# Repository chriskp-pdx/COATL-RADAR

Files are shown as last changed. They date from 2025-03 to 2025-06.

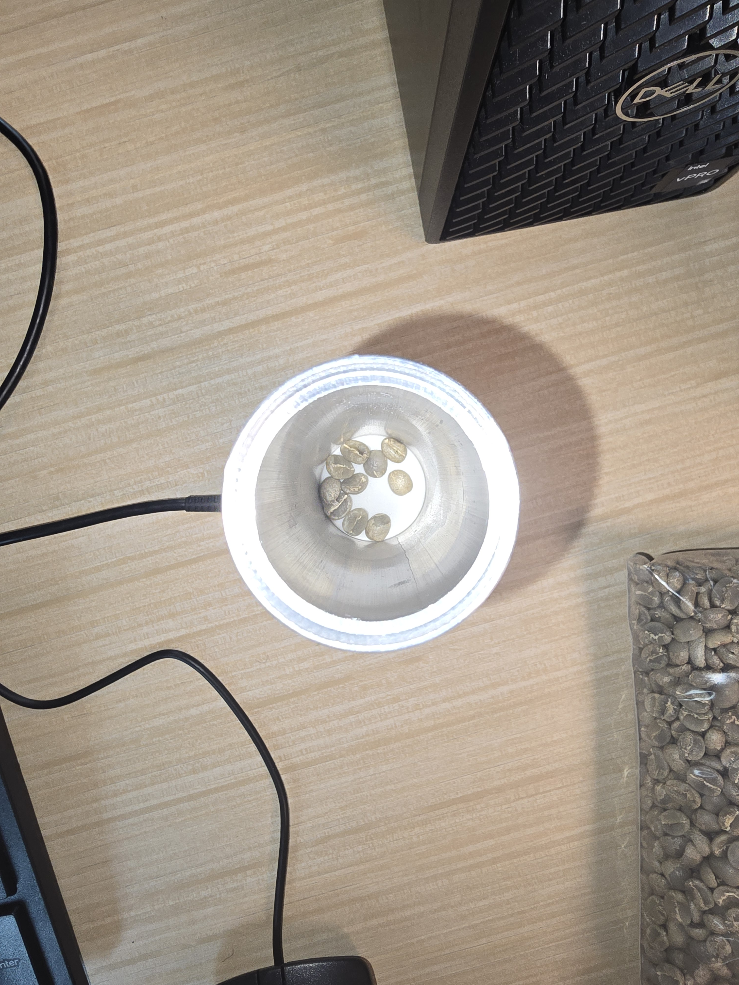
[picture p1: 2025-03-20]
Documentation/Test Documentation/3D Printed Prototype Testing/1-10 Bean Range Tests/Lens 1 Testing/Images/20250310_161537.jpg

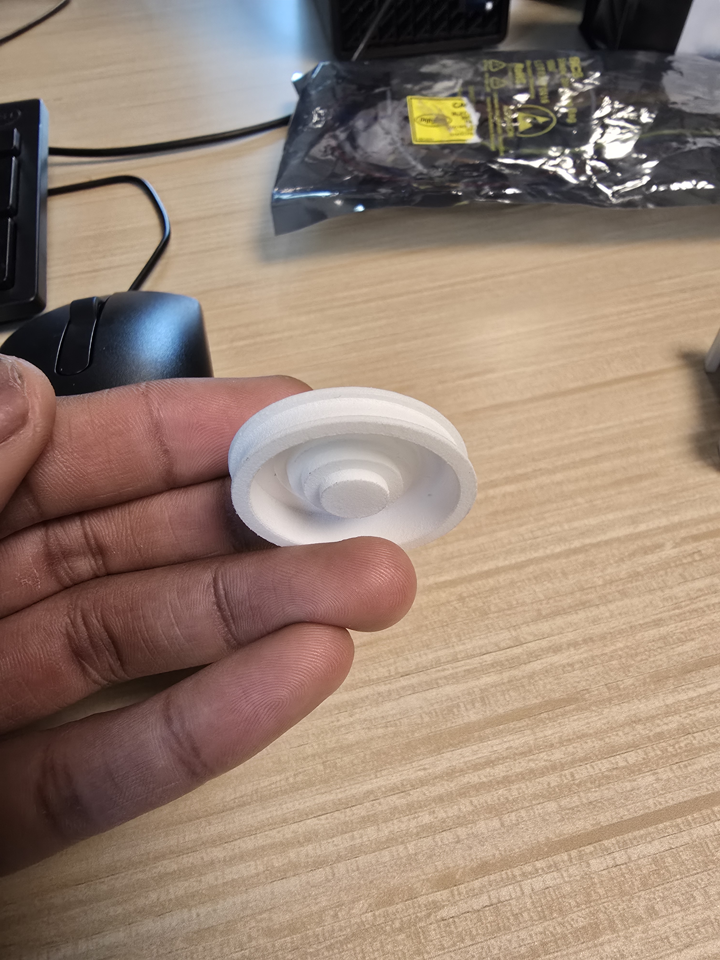
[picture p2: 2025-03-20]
Documentation/Test Documentation/3D Printed Prototype Testing/1-10 Bean Range Tests/Lens 2 Testing/Images/Lens2.jpg

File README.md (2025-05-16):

# COATL-RADAR

2025 ECE 412/413 COATL-RADAR PROJECT

Green Coffee Bean Moisture Content Detection Using 60GHz Radar Module

# Team:
Chris Kane-Pardy

Kamal Smith

Henry Sanders

Wallace Mckenzie

# Software:

## A121 Binary File

Acconeer Provided File for Flashing Firmware to New XE125 EVK Radar Module

## A121 Exploration Tool Connection

Initial Test Programs to Interface with Acconeer A121 Exploration Tool Through Python

## Data Collection

### Consistency Testing

After Deciding Against Calculating Permittivity, We Created These Programs, Which Attempted to Mitigate Inconsistencies in Results due to Bean Geometries

### Datasets

Collected Datasets for Use in Machine Learning

### Permittivity Calculations

Original Test Programs, Which Aimed to Determined Moisture Content by First Calculating Permittivity from Acconeer "IQ" Data

### FullAverageScan (Green Coffee)

Final Program Version Which Utilizes Several Averages and Captures the Entire Waveform of the IQ Data Scan

### FullAverageScan (Roasted Coffee)

Final Program Version With Modified Settings Aimed at using Ground Roasted Coffee

## Machine Learning

### Preliminary Testing

Original Exploratory Machine Learning Programs

### Experimentation Variants

3 Separate Versions of the Base Machine Learning Program (Chris, Kamal, & Henry), Which We Used to Test and Compare Accuracy Across Different Settings

### Final Machine Learning Program with Live Testing

The Final Version of Our Machine Learning Program

## Stepper Motor

Outdated Programs for Interfacing ESP32 to Stepper Motor Using I2C for Bean Rotation

# Documentation:
## Acconeer Documentation

-Acconeer A121 Radar Datasheets

-Acconeer XE125 EVK User Guides

-Acconeer Exploration Tool Documentation

-Acconeer Lens Kit Documentation & Data Sheet

## Administrative (Team Organization)

-Weekly Progress Reports

-Team Meeting Notes

## Datasheets

Miscellaneous Datasheets from Abandoned Components

## Research Documents

### COATL-RADAR Research Documentation

Documents Compiled by the Team Throughout Our Process Which We've Deemed Useful Starting Points

### Machine Learning Research (Mark Martin)

Brief Introduction to Machine Learning Provided by Our Wonderful Industry Sponsor (Dr. Mark Martin)

### Optics Research

Documents Focusing on the use of Lenses in Radar Applications (Brief Research from Wallace)

### Research Articles (Dr. Joshua Mendez)

Contains Research Papers Provided by Our Industry Sponsor (Dr. Joshua Mendez)

## Test Documentation

Test Results, Intermediate Procedures, and Various Methods We Attempted Throughout the Course of the Project

### 3D Printed Prototype

Testing Results Utilizing PETG/PLA 3D Printed Test Device

### Medium Metal Device Testing

Testing Results Utilizing Medium-Sized Aluminum Test Device

### Metal Device Testing

Testing Results Utilizing Large Aluminum Test Device

### Thin Metal Device Testing

Testing Results Utilizing Thin Aluminum Test Device

# 3D Modeling
### V1.1
Contains Original 3D Printed "Spider" Prototype for Testing Rotation
### V1.2
Contains Modified 3D Printed "Spider" Prototype with Updates
### V2.1
Contains "Christmas Tree Stand" to Hold Metal Tube Flush w/ Lens for Shielding and 0 Intereference

# Assigments:
Contains All Course Deliverables

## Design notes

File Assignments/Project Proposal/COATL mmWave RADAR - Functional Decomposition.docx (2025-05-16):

COATL mmWave RADAR:

Functional Decomposition

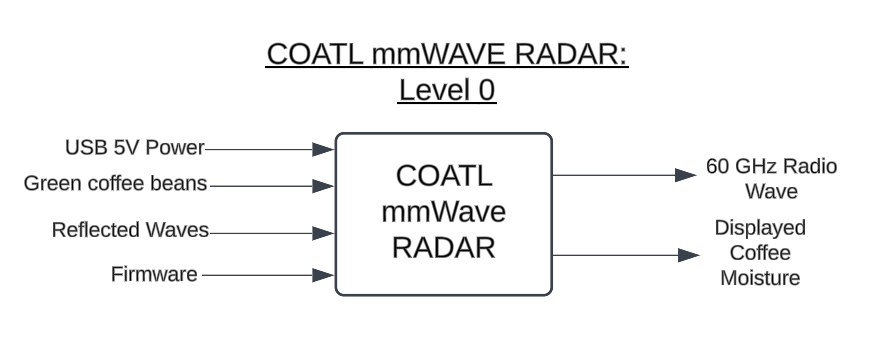
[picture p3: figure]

Module | COATL mmWave RADAR
Inputs
Outputs
Functionality

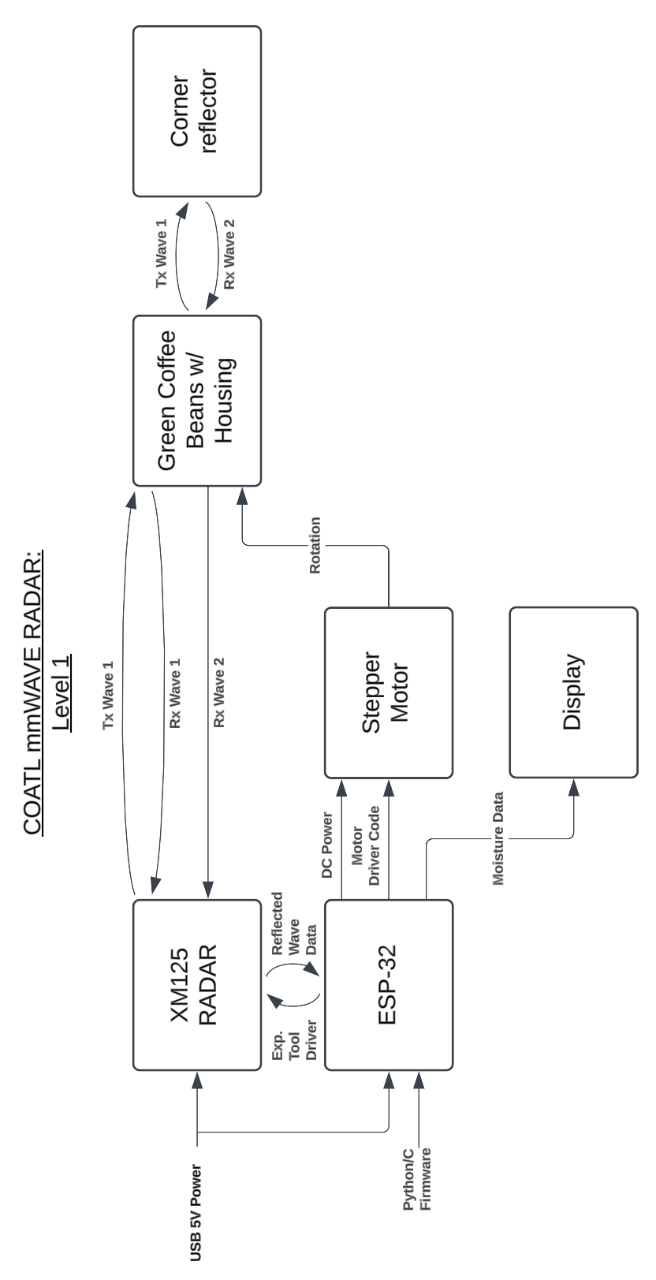
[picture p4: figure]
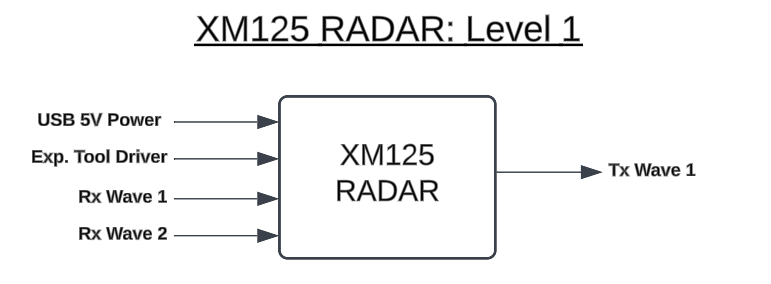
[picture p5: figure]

Module | XM125 RADAR
Inputs
Outputs
Functionality

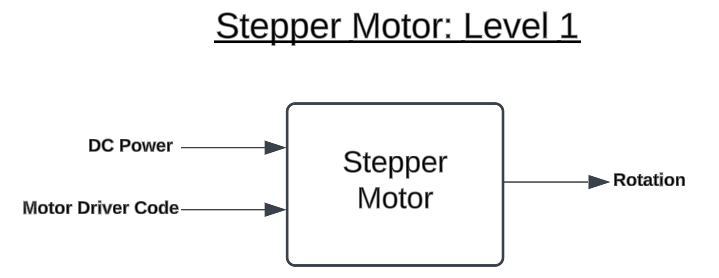
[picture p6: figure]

Module | Stepper Motor
Inputs
Outputs
Functionality

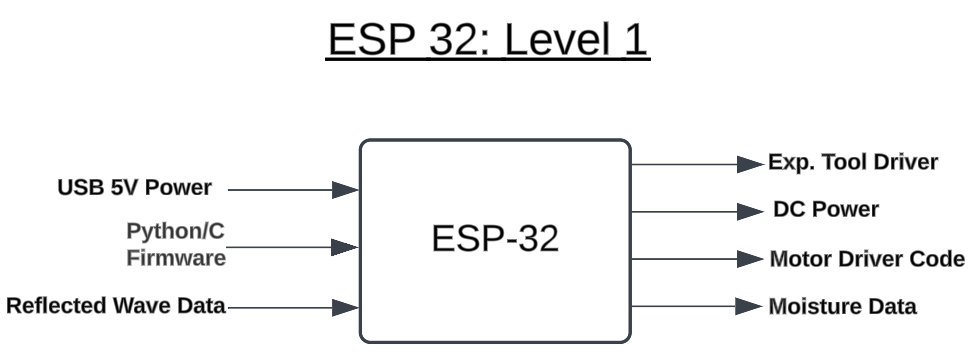
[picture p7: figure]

Module | ESP 32
Inputs
Outputs
Functionality

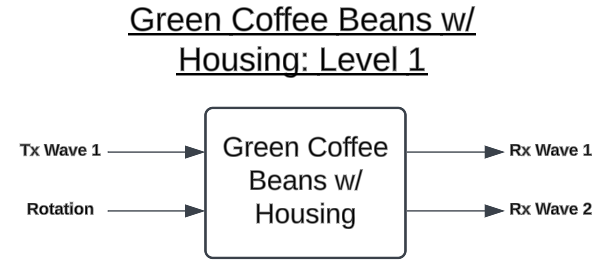
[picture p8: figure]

Module | Green Coffee Beans w/ Housing
Inputs
Outputs
Functionality

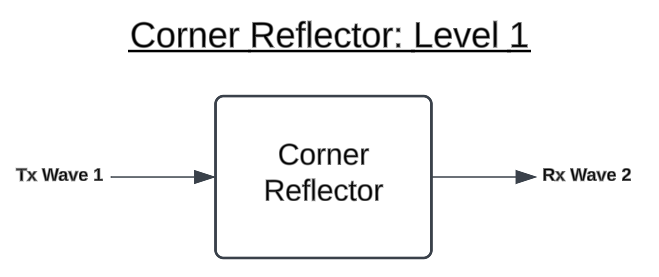
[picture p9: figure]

Module | Corner Reflector
Inputs
Outputs
Functionality

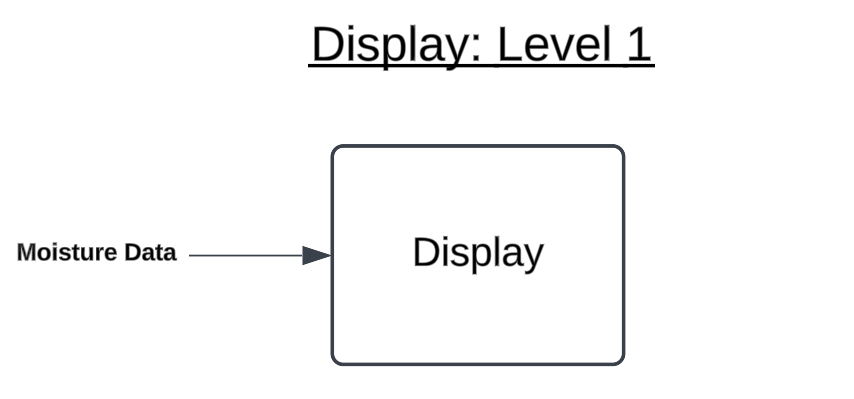
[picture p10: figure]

Module | Display
Inputs
Outputs
Functionality

Kamal Smith Henry Sanders Chris Kane-Pardy Wallace McKenzie 29 January 2025

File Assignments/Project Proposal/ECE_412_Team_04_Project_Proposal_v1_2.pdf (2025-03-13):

# COATL - Millimeter Wave

# RADAR Project Proposal

# Team 4

# Version 1.1

Portland State University

Maseeh College of Engineering & Computer Science

Department of Electrical & Computer Engineering

## Authors:

Kane-Pardy, Chris

McKenzie, Wallace

Sanders, Henry

Smith, Kamal

## January 31, 2025

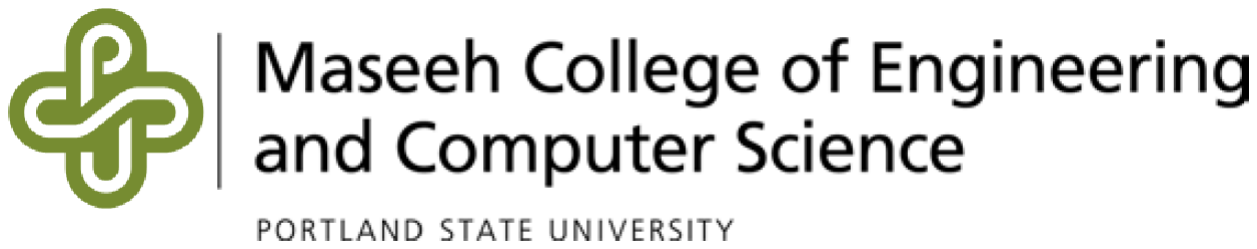
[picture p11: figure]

COATL - Millimeter Wave RADAR | PSU ECE 412

# Executive Summary

The Millimeter-Wave RADAR for Assessing Green Coffee Quality project aims to develop an innovative, non-destructive method for measuring the moisture content of green coffee beans. Accurate moisture measurement is critical for optimizing coffee roasting processes and preserving quality during storage. Current solutions, such as oven drying or capacitive moisture sensors, are either destructive or cost-prohibitive for widespread use.
To address these challenges, this project proposes leveraging the XM125 60 GHz millimeter-wave RADAR module, known for its sensitivity to moisture due to water’s strong absorption properties at this frequency. The system will utilize time-of-flight RADAR technology to detect variations in dielectric properties influenced by moisture content. A key innovation of this approach is its potential to offer a low-cost, scalable alternative for producers, importers, and specialty roasters.
The project will result in a functional prototype comprising a RADAR-based sensor system, software to estimate dielectric constants, and a real-time graphical user interface for visualizing measurement data. Core deliverables include moisture content estimation software, validation against professional-grade sensors, and a userfriendly design for practical use.
This multidisciplinary effort will require expertise in RF system design, programming, CAD modeling, and data analysis. The project aligns with industry needs and has significant implications for improving coffee quality assessment methods while reducing costs for small-scale producers.

Engineering Building, 1930 SW 4th Ave, Portland, OR 97201 1

# Contents

1 Background and Research | 3
2 Product Design Specification | 6
3 Project Management Plan | 13
4 Industry Sponsor / Faculty Advisor Signatures | 16

Engineering Building, 1930 SW 4th Ave, Portland, OR 97201 2

# 1 Background and Research

Sponsor
The project is sponsored by the Coffee And Telesensing Lab (COATL), a research group focused on applying advanced sensing technologies to improve agricultural processes and product quality. COATL specializes in using state-of-the-art remote sensing techniques, including radar and microwave systems, to address challenges faced by coffee producers and processors. By combining expertise in electrical engineering, signal processing, and agricultural science, COATL aims to develop scalable, cost-effective solutions to enhance coffee quality monitoring and control.

Technology Domain and Context
The technology domain of this project is millimeter-wave radar sensing for agricultural product quality assessment. Specifically, this system uses the XM125 60 GHz pulsed coherent radar module to measure the moisture content of green coffee beans. Moisture content is critical in coffee’s long-term storage stability, roasting profile, and overall quality. Traditional moisture measurement methods include oven drying (destructive and time-consuming) or capacitive sensors (non-destructive but expensive). The millimeter-wave radar system offers a promising alternative by leveraging water’s strong absorption characteristics at 60 GHz. This approach has already been used for monitoring moisture in other agricultural products, such as drying leaves.

System Functionality
The radar-based moisture sensor works on a time-of-flight principle. The radar transmits a series of electromagnetic pulses and measures the delay and amplitude of reflected waves. When green coffee beans are placed in a sample holder, the dielectric properties of the beans—directly related to their water content—affect the reflected signal. By extracting the dielectric constant, the system estimates the moisture level in the sample. The relationship between reflectivity γ and permittivity is given by:

γ =

√
ϵ1 −

√
ϵ2
√
ϵ1 +

√
ϵ2

!2

Engineering Building, 1930 SW 4th Ave, Portland, OR 97201 3 where ϵ1 and ϵ2 are the relative permeabilities on either side of the coffee-air boundary.
A conceptual design of the proposed RADAR-based moisture sensor is illustrated in Figure 1 below. The system includes: (1) the XM125 radar module, (2) a sample holder designed to contain coffee beans, and (3) a corner reflector. When the sample holder is empty, the millimeter-wave pulses emitted by the radar are reflected back with high amplitude from the corner reflector. To minimize interference with the measurements, the sample holder must be made from materials transparent to 60 GHz waves. When filled with green coffee beans, the pulses are attenuated proportionally to the moisture content in the beans. The raw radar data from the XM125 module is processed using a computer or microcontroller to calculate the dielectric constant of the sample. The system’s performance will be validated by comparing its moisture content estimates to those obtained using a commercial capacitive moisture sensor.

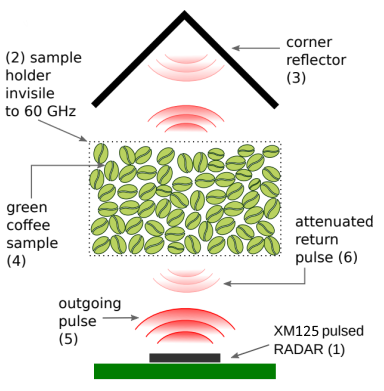
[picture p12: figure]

Figure 1: Conceptual model of material sensing with 60 GHz RADAR for coffee

Engineering Building, 1930 SW 4th Ave, Portland, OR 97201 4

## 1.1 Research

### 1.1.1 Commercial Off-the-Shelf Products

Our industry sponsor (Dr. Joshua Mendez) has provided us with the Acconeer XE125 EVK (evaluation board for the XM125 PCR module). Additionally, he’s provided us with access to the RoastRite Coffee Moisture and Density Meter RM-800 to act as a known good test module/baseline for our test results.

### 1.1.2 Open Source Projects

We’ll be using the Acconeer Exploration Tool (version A121) which runs on Python 3.11.9. Aside from using command line Python, we may utilize Spyder 6 for its convenience as a Python IDE. VS code will be used for C programming, along with the ESP-IDF.

### 1.1.3 Patents, Papers, White Papers, Articles, Conference Proceedings

Patents & White Papers:
Our project proposal and PDS have been thoroughly reviewed via extensive internet research to ensure that it does not infringe on any existing patents or intellectual property. We have conducted due diligence to confirm that all designs, methods, and materials used will be original or fall within the public domain.

Papers:

“A 60 GHz pulsed coherent radar for online monitoring of the withering condition of leaves,” ScienceDirect, Jun. 16, 2022.
https://www.sciencedirect.com/science/article/pii/S0924424722003314 (accessed Jan. 2025).
T. Albing, R. Nelander, and Acconeer AB, “Material Classification of Recyclable Containers Using 60 GHz Radar,” arxiv.org, 2023. https://arxiv.org/pdf/2312.14539

The two papers above use the same radar module as the one we will be using (the XM125). One detects moisture content in leaves, and the other detects recyclable material type. Neither is too dissimilar to our objective and appear to be good reference points. We plan to first try and replicate the recyclables project results to try and familiarize ourselves with the sensor, and periodically reference the leaf paper for any helpful information it may provide.

Engineering Building, 1930 SW 4th Ave, Portland, OR 97201 5

# 2 Product Design Specification

## 2.1 Product Overview

The millimeter-wave radar offers an affordable solution with capabilities rivaling more expensive competitors. This device accurately measures the moisture content of green coffee beans by sending a 60 GHz signal through the provided container. It helps users determine the freshness of their beans and whether it’s time to discard or roast them. Designed for coffee enthusiasts and newcomers alike, the device ensures users can identify beans that are too dry or perfectly suited for roasting. The device is simple to use: fill the container with the specified amount of coffee beans, ensuring it is not overfilled to maintain accuracy. Place the lid securely, then use the small screen to start the reading. Within moments, the moisture content will be displayed.
Initially, we will produce a limited quantity for our industry sponsor and as a proof of concept. If successful, we plan to pursue a patent and explore options for manufacturing or selling the finished product.

## 2.2 Stakeholders

Industry Sponsor

- Dr. Joshua Mendez

Engineering team

- Henry Sanders
- Chris Kane-Pardy
- Wallace McKenzie
- Kamal Smith

Customer/Intended Audience

- Coffee Roasters (companies)
- Coffee Enthusiasts

Engineering Building, 1930 SW 4th Ave, Portland, OR 97201 6

## 2.3 Requirements

- Must:

– Be able to extract the dielectric constant of a fixed-volume sample placed in the RADAR’s beam path for materials with dielectric constants ranging from 5-20.

– Differentiate between at least 3 coffees with different moisture contents (e.g. 8%, 10%, and 12%)

– Detect when the sample holder is empty.

- Should:

– Be able to determine the moisture content of coffees in the range of 7%-15%.

– Have the ability to determine the moisture content of green coffee with a resolution of 1%.

– Provide estimates of moisture content that are within 20% of the value reported by a professional capacitive sensor moisture meter.

- May:

– Have the ability to determine the moisture content of green coffee with a resolution of 0.1%.

– Provide estimates of moisture content that are within 10% of the value reported by a professional capacitive sensor moisture meter.

## 2.4 Specifications

- XM125 PCR Module
- Acconeer A121 Exploration Tool

Engineering Building, 1930 SW 4th Ave, Portland, OR 97201 7

## 2.5 Initial Product Design

Hardware Architecture

L0 Block Diagram-

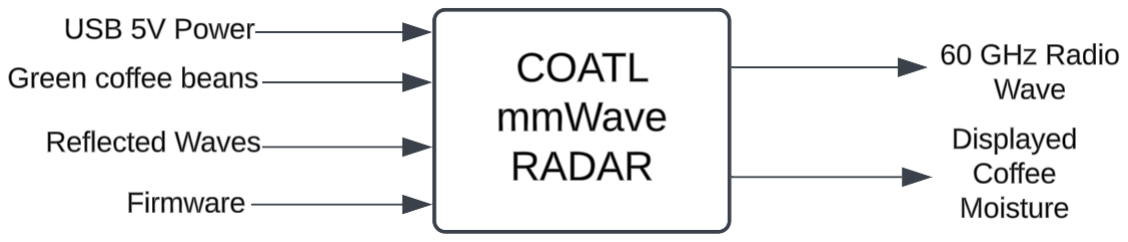
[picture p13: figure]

Figure 2: L0 Block Diagram - COATL mmWave RADAR

L1 Block Diagram-

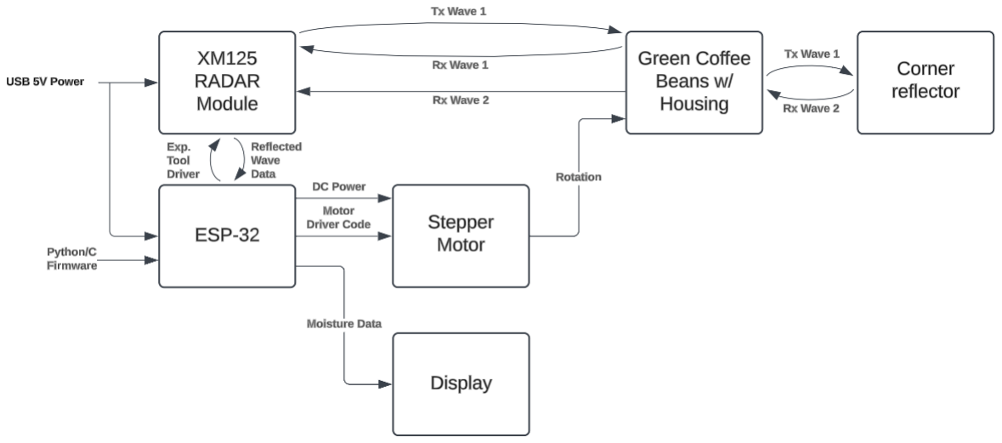
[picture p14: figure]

Figure 3: L1 Block Diagram - COATL mmWave RADAR

We intend to create L1 Block Diagrams for the individual modules in Figure 3 for the final revision of the project proposal.

Engineering Building, 1930 SW 4th Ave, Portland, OR 97201 8

Software Architecture

Languages-

- Python
- C (ESP-IDF)

IDE’s-

- Spyder 6 (Python Scripting)
- VS Code (C Programming)
- STM32Cube Programmer (XE125 EVK Firmware Updates)

Data Flow-

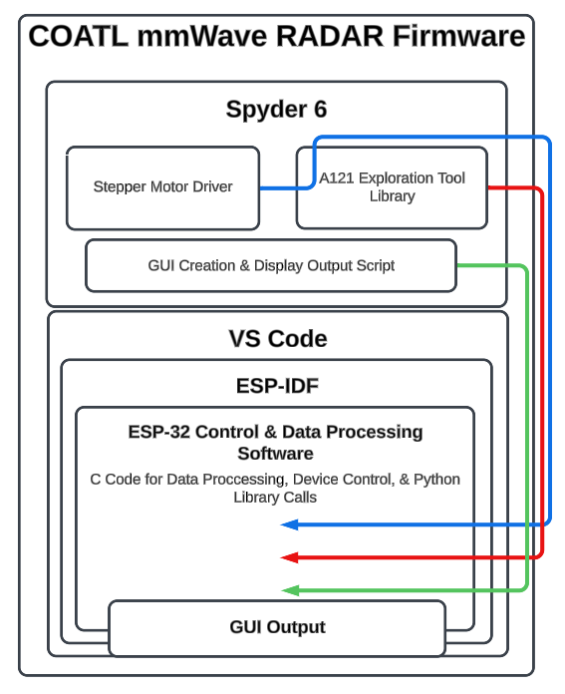
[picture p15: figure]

Figure 4: High-Level Data Flow Diagram

We intend to create more in-depth low-level code block diagrams for the future versions of this document as the project progresses.

Engineering Building, 1930 SW 4th Ave, Portland, OR 97201 9

User interface/experience

- Preparing for Measurement: The user begins by placing the provided container on a flat surface and filling it with the required amount of green coffee beans, ensuring it is not overfilled to maintain measurement accuracy. The lid is securely placed, and the container is positioned in the designated slot of the RADAR system.
- Initiating a Reading: Through the UI, the user selects the ”Start Measurement” option. The RADAR system sends a 60 GHz signal through the coffee beans, analyzing the time-offlight and dielectric properties to estimate moisture content.
- Viewing Results: Within seconds, the moisture content is displayed on the screen, accompanied by a visual indicator (e.g., color-coded bar or gauge) highlighting whether the beans fall within an ideal moisture range for roasting. For advanced users, the system provides an option to view detailed metrics, such as dielectric constant readings and moisture percentage.
- Data Management: Users can choose to save the results to the device’s memory or export them via USB for further analysis. This feature is especially valuable for producers who need to log data for quality control or compliance purposes.
- Maintaining the System: The software includes prompts for routine calibration checks to ensure long-term accuracy. Additionally, the device provides troubleshooting tips in case of measurement anomalies or user errors.

The interface prioritizes simplicity for beginners while offering advanced features for professionals. By combining straightforward setup, quick readings, and detailed insights, the system empowers users to make informed decisions about their coffee quality with minimal effort.

## 2.6 Verification plans

We will verify the accuracy of our product by comparing its results to those of the RoastRite™

Coffee Meter, a proven tool for measuring coffee bean moisture content.
The testing process begins with multiple bags of green coffee beans. A bag will be selected at random, and its moisture content measured using the RoastRite™ Coffee Meter. This value will

serve as the benchmark for our millimeter-wave radar system. While our initial goal was to achieve results within 20% of the benchmark, we aim to reduce this error margin to within 5%.
We will repeat the process for additional bags, averaging the deviations between our product’s measurements and the RoastRite™ results to evaluate overall performance. All testing will follow

the provided user instructions without any modifications.

Engineering Building, 1930 SW 4th Ave, Portland, OR 97201 10

## 2.7 Risks

Key risks for our project include:

- The radar module may not be as accurate as anticipated.
- Difficulty consistently detecting beans due to their size being comparable to the RF signal wavelength.

Although the extent of these risks is uncertain, we are exploring potential solutions. One idea is to adjust the angle of the transmitted signal to improve measurement accuracy. However, the interaction between the signal and similarly sized coffee beans remains unclear, so testing will begin as soon as possible to address this issue.
A critical challenge is determining how to effectively reflect the signal. While we were provided with an initial test setup, it has proven unreliable and may require redesigning. Resolving this will be a significant step toward refining our testing and code development process.
Another consideration is how to handle the collected data. Older XM125 modules support machine learning, while newer versions do not. Although we’ve discussed using machine learning, it’s unclear whether it would simplify or complicate the process. Further testing and analysis will help determine the best approach.

## 2.8 Deliverables

Course Deliverables

- Project proposal
- Weekly Progress Reports
- Final report
- ECE Capstone Poster Session poster
- Detailed design documentation, explaining what our design does, how our design works, and why we made the decisions we did
- Bill of materials and pricing
- User’s manual
- Version control
- A working prototype
- A manufacturable design

Engineering Building, 1930 SW 4th Ave, Portland, OR 97201 11

Industry Sponsor Deliverables

- Must:

– A USB-powered prototype system that demonstrates the ability to use millimeter-wave RADAR to perform non-destructive material detection and classification

– Software that computes the dielectric constant of a sample from RADAR returns

– A graphical user interface (on a computer) that can display both RADAR return signals and dielectric constant estimates in real time

- Should:

– Software that computes the water content of coffee beans from the estimated dielectric constant

– A graphical user interface (on a computer) that can display RADAR return signals, dielectric constant estimates, and moisture values in real time

– Software to remove the contribution of user-made sample holders from the RADAR return

Product delivery method to be determined w/ Industry Sponsor

Engineering Building, 1930 SW 4th Ave, Portland, OR 97201 12

# 3 Project Management Plan

## 3.1 Timeline, with milestones

Our project schedule can be found at: COATL-RADAR Project Schedule

## 3.2 Budget and Resources

The budget is currently loosely defined - specifics will be determined soon. We currently have 2 XM125 radar modules, and 2 more have been ordered. We also are in the process of determining our budget for 3D printing. The industry sponsor will be providing us with the coffee samples needed for testing.
We will conduct most of our experimentation in FAB 60-14, otherwise known as the ”Balloon Lab”. Additionally, we will be using the EPL as a resource for on-the-fly, as-needed components, as well as 3D printing. We intend to purchase a locker in the EB to store fragile and/or sensitive devices/components.

## 3.3 Intellectual Property Discussion

The industry sponsor has yielded all IP to the creators. Nothing is currently licensed, but a discussion about patenting will take place after the project is completed.

## 3.4 Team

Henry Sanders, FA Coordinator

Henry is the group’s record keeper, documentation expert, and power engineer. He will ensure all documentation requirements are met, assist with programming, and work on researching and implementing the dielectric constant calculations. He is currently researching power sources for the design.

Skills:

- Power Systems
- Python, C, Assembly
- Technical Communication/Writing

Engineering Building, 1930 SW 4th Ave, Portland, OR 97201 13

Chris Kane-Pardy, IS Coordinator

Chris is currently working on interfacing with the XM125, specifically researching alternative methods of programming and displaying the reflected waveform. Additionally, he will be in charge of 3D modeling.

Skills:

- Hardware Architecture Design
- Microelectronic Circuit Design
- 3D Modeling

Wallace McKenzie

Wallace is the resident optics engineer and will be looking into the best ways to manipulate the XM125’s millimeter wave to suit the needs of the project. Additionally, he will be assisting with programming and managing the project.

Skills:

- Embedded Systems, Micro-controllers, ESP-IDF, C , Python, C++, Assembly
- Leadership, project tracking, project management
- Applied Optics

Kamal Smith

Kamal will be tackling the machine learning aspect of this project, if there ends up being one (TBD). He will also be assisting with research, programming, 3D modeling, and project scheduling.

Skills:

- Code Debugging
- Hardware design
- PCB Circuit design

Engineering Building, 1930 SW 4th Ave, Portland, OR 97201 14

## 3.5 Development Tools and Process

Project Management Methodology

We will be adhering to a project schedule/timeline as outlined in section 3.1. We have weekly standups on Wednesdays from 7:30pm-8:30pm, and group work sessions on Fridays from 1:00pm-5:00pm. Research and work assignments for the following week will be designated during stand-up.

Collaboration Tools

- Email
- Discord
- Google Drive
- GitHub
- Overleaf (LaTeX)
- Google Calendar
- Zoom

Technical Tools

- STM32CubeProgrammer
- Python (Spyder 6 IDE)
- Fusion 360
- Lucid FlowCharts
- Excel/Google Sheets
- KiCAD (TBD)

Engineering Building, 1930 SW 4th Ave, Portland, OR 97201 15

# 4 Industry Sponsor / Faculty Advisor Signatures

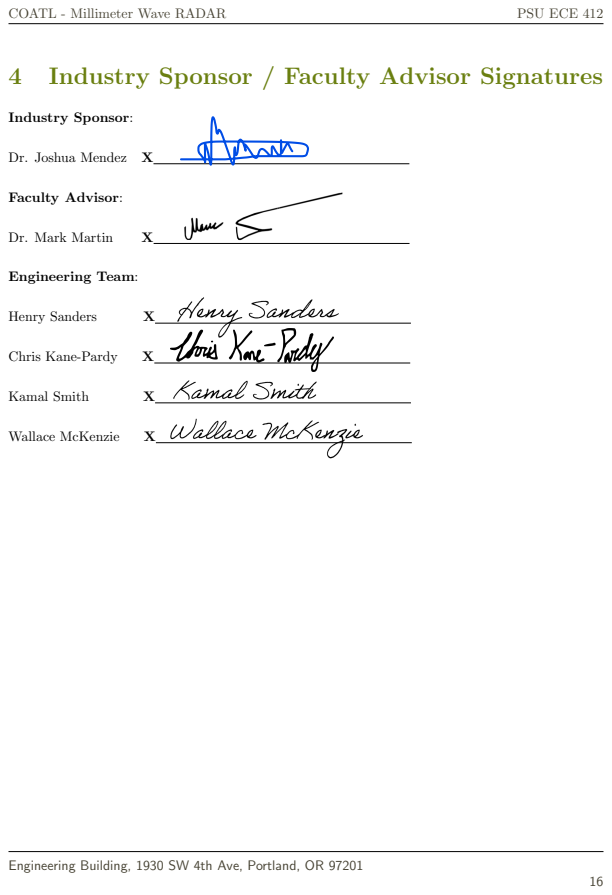
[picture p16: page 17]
Industry Sponsor:; Faculty Advisor:; Dr. Mark Martin; Engineering Team:; Henry Sanders; Chris Kane-Pardy; Kamal Smith; Wallace McKenzie

Dr. Joshua Mendez X

Engineering Building, 1930 SW 4th Ave, Portland, OR 97201

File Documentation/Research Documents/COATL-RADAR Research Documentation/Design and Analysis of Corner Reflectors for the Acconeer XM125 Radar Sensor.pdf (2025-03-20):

Design and Analysis of Corner Reflectors for the Acconeer XM125 Radar Sensor

Abstract

This paper examines the design of corner reflectors to optimize the performance and accuracy of the Acconeer XM125, a 60 GHz pulsed coherent radar sensor. Three reflector shapes—parabolic, flat plate, and trihedral corner—are analyzed for their radar cross-section (RCS), beam characteristics, and suitability within a constrained setup. A parabolic reflector is proposed for its focusing potential and compared to flat plate and trihedral alternatives to determine the best choice for enhancing signal quality and data collection.

### 1. Introduction

The Acconeer XM125 radar sensor operates at 60 GHz, offering a 2.5 mm range resolution and a wide field of view (FoV) due to its integrated antenna (Acconeer, 2023). However, its omnidirectional pattern can dilute signal strength for small or low-reflectivity targets. A corner reflector can increase the radar cross-section (RCS) and improve signal-to-noise ratio (SNR), enhancing measurement precision. This paper evaluates parabolic, flat plate, and trihedral corner reflectors to identify the optimal design for the XM125.

### 2. Reflector Design Considerations

### 2.1 Requirements

- Maximize RCS to boost reflected signal strength.
●
Enhance SNR for accurate detection of small targets. ●
Fit within a compact space (e.g., <50 mm dimensions).
●
Use lightweight, radar-reflective materials (e.g., aluminum).

### 2.2 Reflector Shapes

1. Parabolic Reflector:
- Description: A curved dish focusing radar waves into a narrow beam, with the XM125 at the focal point.
○
RCS: High when aligned, approximately σ ≈ πD²/(4λ²), where D is the diameter and λ is the wavelength (5 mm at 60 GHz)
○
Advantages: Concentrates energy, improving SNR and aiding precision.
○
Challenges: Needs precise alignment; harder to fabricate.
2.
Flat Plate:
- Description: A planar surface reflecting waves directly back when perpendicular to the radar beam.
○
RCS: σ = (4πA²)/λ², where A is the area
○
Advantages: Simple to make; predictable reflection.
○
Challenges: Narrow angular response; no focusing effect.
3.
Trihedral Corner:
- Description: Three orthogonal planes form a corner, reflecting waves back over a wide angle.
○
RCS: σ = (12πa⁴)/λ², where a is the side length.
○
Advantages: High RCS; wide FoV (up to 90°). ○
Challenges: Bulkier; no beam focusing.

### 2.3 Parabolic vs. Other Shapes

- Focusing: The parabolic reflector focuses energy into a tight beam, boosting SNR by ~10-15 dB (estimated from antenna gain, Balanis, 2012). Flat plates and trihedral corners scatter energy without concentration.
●
Angular Response: Trihedral corners reflect consistently across a 90° FoV, ideal for omnidirectional use, while parabolic and flat designs require alignment.
●
Size Efficiency: A 4 cm diameter parabolic dish (~12 cm³ volume) offers high RCS with less bulk than a trihedral corner (e.g., ~27 cm³ for a = 3 cm with similar RCS).

### 3. Design Implementation

### 3.1 Parabolic Reflector

- Dimensions: Diameter = 4 cm, depth = 1 cm (focal length ≈ 1 cm). ●
Material: Thin aluminum foil (0.1 mm), reflective at 60 GHz.
●
RCS: σ ≈ π(0.04)²/(4×0.005²) ≈ 50 m² (theoretical peak).
●
Fabrication: Molded from foil or 3D-printed with a conductive coating.

### 3.2 Flat Plate

- Dimensions: 4 cm x 4 cm square. ●
Material: Aluminum sheet.
●
RCS: σ ≈ (4π(0.04)²)/0.005² ≈ 20 m².
●
Fabrication: Cut from stock material; minimal processing.

### 3.3 Trihedral Corner

- Dimensions: Side length a = 3 cm. ●
Material: Aluminum panels.
●
RCS: σ ≈ (12π(0.03)⁴)/0.005² ≈ 30 m².
●
Fabrication: Assembled from three cut pieces; moderate complexity.

### 4. Performance Analysis

- Parabolic: Offers the highest SNR due to focused energy, ideal for precision tasks like small-target detection. Alignment is critical but manageable with fixed positioning.
●
Flat Plate: Provides moderate RCS but loses effectiveness if misaligned; lacks focusing for enhanced resolution.
●
Trihedral: Delivers high RCS across a wide angle, best for static setups needing omnidirectional reflection, but no SNR boost.

The parabolic reflector outperforms in directed signal enhancement, critical for detailed data collection, while the trihedral excels in versatility and the flat plate in simplicity.

### 5. Conclusion and Recommendation

The parabolic reflector is recommended for the XM125 due to its superior SNR and energy focusing, optimizing radar performance for precise applications. A 4 cm diameter design balances RCS and size, using aluminum foil for cost-effective fabrication. While trihedral corners offer wide-angle reflection and flat plates simplicity, the parabolic shape best enhances data quality within the XM125’s constraints. Future testing should validate theoretical RCS and explore alignment stability.

References

- Acconeer. (2023). A121 Pulsed Coherent Radar Sensor Datasheet. Acconeer AB. ●
Balanis, C. A. (2012). Antenna Theory: Analysis and Design (3rd ed.). Wiley.
●
Knott, E. F., Shaeffer, J. F., & Tuley, M. T. (2004). Radar Cross Section (2nd ed.). SciTech Publishing.

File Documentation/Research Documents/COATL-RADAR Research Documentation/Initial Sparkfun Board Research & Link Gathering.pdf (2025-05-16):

## Sparkfun XM125:

- The sensor has remarkably low power consumption (Look into on datasheet)
- AP2112K 3.3V/600mA and RT9080 1.8V/600mA voltage regulators
- USB I

2C
- Motion detection (although probably not particularly useful for us)
- Acconeer Exploration Tool (https://github.com/acconeer/acconeer-python-exploration) “The ML interface (no longer supported). Support for the Machine Learning interface in Exploration Tool has been dropped. If you still need to use it, it is possible to use an old version of Exploration Tool.”
- Note: Due to the higher frequencies, pulsed coherent radar sensors may be regulated in certain countries. Be sure to check local regulations before use. (Assuming fine bc chosen by Josh)

## XM125 Module Breakdown:

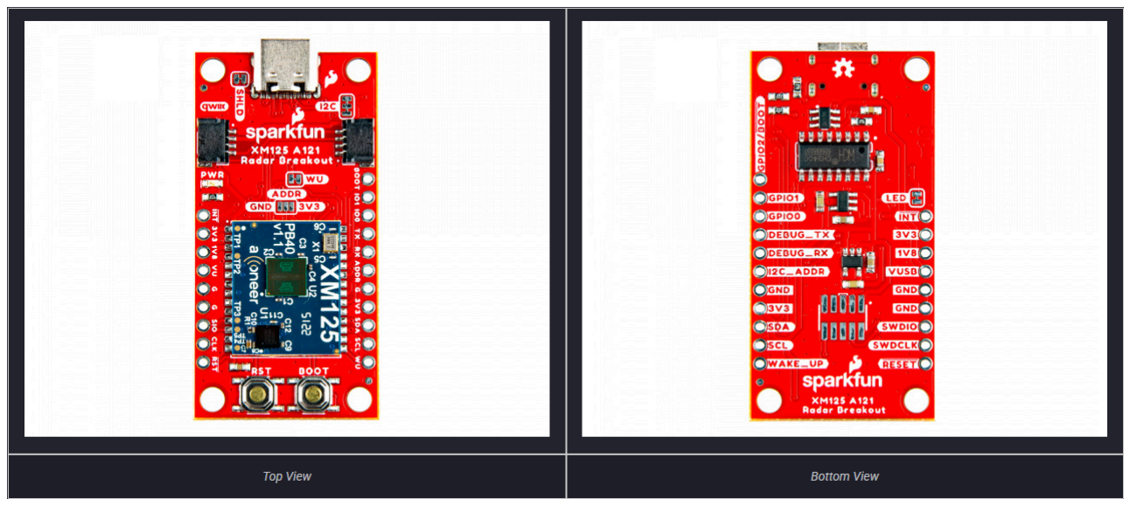
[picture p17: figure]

Hardware Overview - Acconeer XM125 Hookup Guide (https://docs.sparkfun.com/SparkFun_Qwiic_Pulsed_Radar_Sensor_XM125/hardware_overview/)
5V power from the USB C Connector or PTH is regulated down to 3.3V with the AP2112K 3.3V/600mA voltage regulator. The voltage is further regulated down to 1.8V with the RT9080 1.8V/600mA voltage regulator. The logic level for the XM125 is 3.3V for the I/O pins.
There are two PTHs labeled SDA and SCL on one side of the board. These are the I

2C data and clock lines and are connected to two 2.2kΩ pull-up resistors. We also conveniently added a GND and 3.3V pin on one side should you decide to daisy chain additional I

2C devices to the PTH. (SDA — I

2C data, SCL — I

2C
clock)

## XM125 Programming:

Arduino Library - Acconeer XM125 Hookup Guide (https://docs.sparkfun.com/SparkFun_Qwiic_Pulsed_Radar_Sensor_XM125/arduino_library/)
Arduino Examples- Acconeer XM125 Hookup Guide (https://docs.sparkfun.com/SparkFun_Qwiic_Pulsed_Radar_Sensor_XM125/arduino_examples/)

In addition to the Arduino IDE, you may need to install the STM32CubeProgrammer as well.
STM32CubeProgrammer - Acconeer XM125 Hookup Guide (https://docs.sparkfun.com/SparkFun_Qwiic_Pulsed_Radar_Sensor_XM125/installing_stm32cubeprogrammer/)

Flashing Firmware
Flashing Firmware to the XM125 (https://docs.sparkfun.com/SparkFun_Qwiic_Pulsed_Radar_Sensor_XM125/flashing_firmware_xm125/)

Python Exploration Tool
Installing the Acconeer Python Exploration Tool (https://docs.sparkfun.com/SparkFun_Qwiic_Pulsed_Radar_Sensor_XM125/installing_acconeer_python_exploration_tool/)
Getting Started with the Acconeer Python Exploration Tool (https://docs.sparkfun.com/SparkFun_Qwiic_Pulsed_Radar_Sensor_XM125/acconeer_python_exploration_tool/)

## XM125 Schematic:

XM125 Breakout Schematic (https://docs.sparkfun.com/SparkFun_Qwiic_Pulsed_Radar_Sensor_XM125/assets/board_files/SparkFun_Qwiic_Pulsed_Coherent_Radar_Sensor_Breakout-XM125_Schematic_v10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)

## Data Sheets:

A121 – Pulsed Coherent Radar (PCR) (https://docs.sparkfun.com/SparkFun_Qwiic_Pulsed_Radar_Sensor_XM125/assets/component_documentation/A121%20datasheet.pdf) ZED-F9F-02B - GNSS Module (https://cdn.sparkfun.com/assets/f/8/d/6/d/ZED-F9P-02B_DataSheet_UBX-21023276.pdf)

## Timing Requirements:

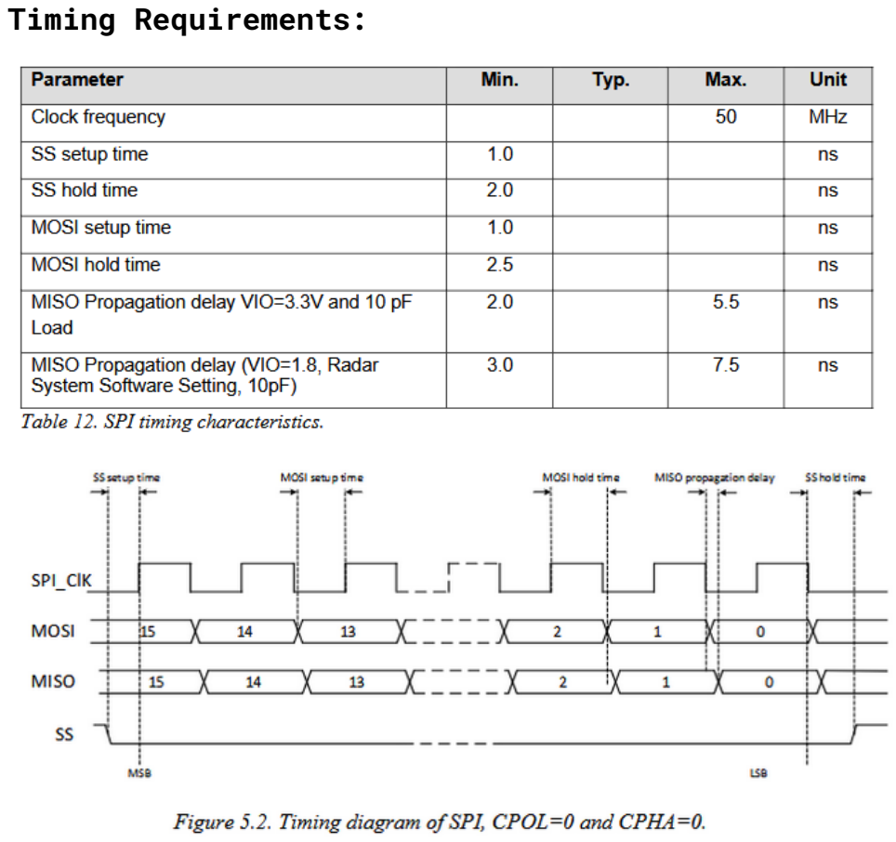
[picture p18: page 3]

## Previous Research Papers:

## Material Classification of Recyclable Containers Using 60 GHz Radar:

- Material Classification of Recyclable Containers Using 60 GHz Radar (https://arxiv.org/pdf/2312.14539)
- The frame rate was set to 15 frames per second and the disc rotated at 0.5Hz, resulting in 30 frames per revolution. One revolution of data is hereafter referred to as the classification window.
- The graphs where two distinct peaks are present correspond to the case when the material has some degree of transparency, allowing the transmitted pulse to partially pass through the front of the container, reflecting off the back, resulting in a second peak.

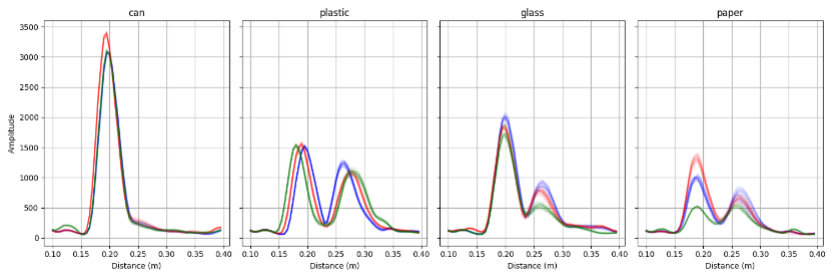
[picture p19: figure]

- Based on these observations, the following features were selected as inputs to the classification model.
- Main peak mean amplitude – Measured amplitude, reflected from the front of the container.
- Secondary peak mean amplitude – Measured amplitude, reflected off the back of the container.
- Peak amplitude ratio – The ratio between the main and secondary peak mean amplitudes.
- Main peak amplitude variance – The variance of the amplitudes, acquired while rotating the container, at the main peak.
- Secondary peak amplitude variance - The variance of the amplitudes, acquired while rotating the container, at the secondary peak.
- Peak variance ratio – The ratio between the variance of the main and secondary peak amplitudes.
These six features, along with the class label, were extracted from each classification window and used for training the classification model.

- One possible alternative to further improve the result and lower the miss-classifications is to extend the classification window to include a longer time series. However, this would increase the required measurement time.

## A 60 GHz pulsed coherent radar for online monitoring of the withering condition of leaves:

- A 60 GHz pulsed coherent radar for online monitoring of the withering condition of leaves (https://www.sciencedirect.com/science/article/pii/S0924424722003314)
- The advantage of using a pulse radar over continuous–wave (CW) radar is that pulse radar operates in the time domain and therefore it does not require the fast Fourier transform (FFT) analysis that characterizes CW radar. Without excessive computational needs, a highly integrated radar system can be implemented using low-power microcontrollers.
- In particular, the resonances for frequencies below 100 GHz occur at nearly 22 GHz for water vapor (H20) and 63 GHz for oxygen (O2). Attenuation due to water vapor is a strong function of temperature, pressure, and humidity. Since this work focuses on measuring changes in the water content in the leaf and not the properties of surrounding vapor or gas in its environment, the choice for 60 GHz over 24 can be decisive.
- The lens performances are conditional to the distance from the integrated antenna. In this work, the construction that allows the maximum gain 9.1 [dB] and 10.0 [dB] for the Fresnel Zone Plate lens (FZP lens) and Hyperbolic Lens (HBL lens), respectively, was chosen. The outlined maximum gains are relative to the free-space scenario.
- Depending on the use case and based on different algorithms, four modes of operation are available for Acconeer pulse coherent radar: sparse, power bins, IQ, and envelope. The sparse service is ideal for motion-sensing applications requiring high robustness and low power consumption. The Power Bins Service is mainly intended for use in low-power applications where large objects are measured at short distances from the radar sensor. The IQ service provides the capability of detecting fine movement occurring in a target scene. This service is similar to the envelope service. Though, the envelope service is optimized for providing an accurate envelope estimate, while the IQ service is optimized for producing a phase-stable estimate. Since there is no use of phase information in the data process for monitoring the withering condition of leaves, the envelope service was selected. A detailed description of all settings for the envelope and other services can be found at https://developer.acconeer.com/download/hardware-and-physical-integratio n-guideline-pdf (https://developer.acconeer.com/download/hardware-and-physical-integration-guideline-pdf)
- The assembled EVK was connected to a computer. A standard corner reflector with RCS of 1 m

2 at 60 GHz was used to fix the path length of the radar signal from the transmit antenna of the PCR along the direction of propagation and to make the power of the reflected signal independent of the environmental background and the other objects.
- The working principle of the prototype:

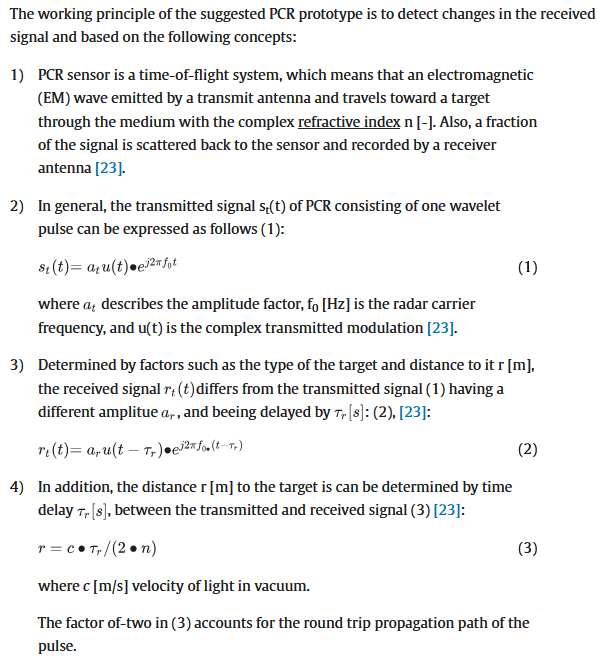
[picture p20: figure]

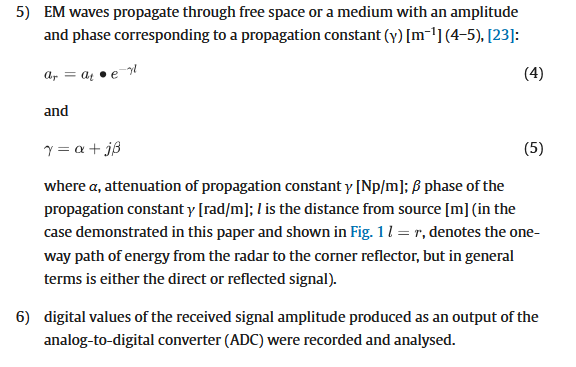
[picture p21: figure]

- Review “2.4. Determination of RWC in a plant leaf applying the Beer-Lambert’s law” for attenuation constant derivation
- Although, the absence of a radome did not show any extreme deviations in measurements and their analysis (the R-Squared value was between 0.93%−95% in all investigated cases), it is not recommended such a setup for monitoring the withering condition of leaves because of reasons described in Section 2.1. (RADOME?)

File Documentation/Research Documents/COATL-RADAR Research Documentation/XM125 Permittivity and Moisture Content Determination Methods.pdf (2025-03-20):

The Acconeer XM125 radar module provides its received data in the form of complex numbers (I/Q data). This is common in radar systems that use pulsed coherent radar (PCR) technology, as the complex representation allows for both amplitude and phase information to be retained.

1. In-phase (I) and Quadrature (Q) Components

The received signal is split into two parts:

- In-phase (I): The real component.
- Quadrature (Q): The imaginary component.

This helps in detecting motion, measuring distance, and determining the Doppler shift.

2. Phase Information
- The phase difference between transmitted and received signals allows for accurate distance measurement.
- The Doppler shift (rate of phase change over time) enables velocity estimation.
3. Signal Processing
- The complex format allows the application of FFT (Fast Fourier Transform) for spectral analysis.
- Phase unwrapping and IQ demodulation help in extracting useful features from the received signal.

Determining the permittivity (dielectric constant, ε ) of an object using the Acconeer XM125
r
involves analyzing how the emitted electromagnetic (EM) waves interact with the material. This can be done using phase shift, signal attenuation, and reflection properties from the complex I/Q data.

# Breaking Down the Amplitude vs Distance Graph in the Acconeer Exploration Tool

The y-axis (Amplitude) represents the strength of the radar reflections at different distances along the x-axis (Distance in meters).

1. Distance (X-axis, in meters)
- This corresponds to the range bins where reflections are detected.
- Each bin represents a specific time-of-flight measurement converted to distance using the speed of light.
- The bin resolution is dictated by the pulse characteristics and radar processing settings.
2. Amplitude (Y-axis, Unitless or Arbitrary Units)
- The amplitude is derived from the magnitude of the complex IQ signal:

A = I

2
+ Q

2

- It represents the strength of the reflected signal at each distance.
- The units are arbitrary, meaning they don’t correspond to a physical unit like volts or watts.
- Instead, the amplitude values are relative and can be used for comparing different reflections.
3. What the Amplitude Represents
- Higher amplitude means a stronger reflection, which can indicate:
- A dense or highly reflective object (e.g., metal, water-rich material like wet beans).
- A closer object that reflects more energy to the sensor.
- A large surface area reflecting the radar wave.
- Lower amplitude means a weaker reflection, possibly due to:
- An object being farther away.
- A material that absorbs or diffuses radar waves.
- The presence of multiple scattering effects.
4. What the Data Means for Moisture Sensing
- Moisture content affects the dielectric constant of materials, which in turn changes how radar waves reflect and propagate.

- Higher water content typically increases the reflection and attenuation, meaning you should see amplitude changes in the Sparse IQ data when comparing dry vs wet samples.
- By analyzing amplitude shifts at specific distances, you can create a model to correlate radar reflections with moisture content.

# Determining the Permittivity of Green Coffee Beans Using the Acconeer XM125: Attenuation-Based & Phase Shift Hybrid Approach

Since green coffee beans are organic and contain moisture, their permittivity is frequency-dependent and varies based on water content and density. Given that the XM125 operates at 60 GHz, the most suitable method would be one that captures both dielectric constant (ε′) and loss factor (ε′′).

A combination of attenuation-based analysis and phase shift measurement is ideal for measuring the real and imaginary parts of permittivity in coffee beans.

Coffee Beans Are a Lossy Dielectric

- They contain moisture and organic material that absorbs EM waves, leading to signal attenuation.
- The attenuation can be related to the loss factor ε′′.

Bean Density Variation Affects Phase Velocity

- The radar signal slows down inside the material, causing a measurable phase shift.
- This allows us to estimate the dielectric constant ε′.

Measuring Phase Difference

- The radar transmits an EM wave and receives the reflected signal.
- Compute the phase shift Δφ between the signal in free space and after passing through the material.

# Steps for Measuring Permittivity Using the XM125

1. Measure Attenuation Through a Known Thickness of Coffee Beans
- Place the coffee beans in a controlled container of known thickness d.
- Transmit the radar signal through the beans.
- Measure the received signal strength after passing through the beans.
- Compare with the signal strength in free space to calculate the attenuation coefficient.

Attenuation-Based Calculation
The transmitted power P through the beans is given by:
T
P

T = P
0

e

−αd

where:
- P received power through the beans
T =
- P received power in free space
0 =
- α = attenuation constant
- d = thickness of the beans

The imaginary part of permittivity ε′′ is related to α by:
ε′′ =
| cα
| 2πf
where:
- c = speed of light,
- f = frequency (60 GHz for XM125).
2. Measure Phase Shift for Permittivity Estimation
- Measure the phase difference between the received signal in free space and the received signal after passing through the beans.
- The relative permittivity ε is related to the phase shift Δφ as:
| r

ε′ =

| λ
| 0 λm

( )

2

where:
- λ free-space wavelength at 60 GHz (5mm for XM125)
0 =
- λ wavelength inside the coffee beans, derived from the measured phase shift m =

3. Relate Permittivity to Moisture Content
- The permittivity of green coffee beans is strongly correlated with their moisture content.
- By creating a calibration curve (mapping measured permittivity to known moisture levels), you can estimate the moisture of unknown samples (we probably will not take this approach).

# Extracting Real (ε′) and Imaginary (ε′′) Parts of Permittivity from XM125 Complex Data

1. Understanding the XM125 Complex Output

The XM125 provides complex I/Q data in the form:

### S = I + jQ

where:
- I = In-phase component (real part),
- Q = Quadrature component (imaginary part),
- S represents the received signal at different timestamps.

This I/Q data is influenced by the permittivity of the material through changes in signal attenuation and phase shift.

2. Extracting Phase Shift and Amplitude

The complex values contain both amplitude and phase information, which change depending on the material’s permittivity.

- Amplitude (A):

### A = |S| = I

2
+ Q

2

This represents signal attenuation, which relates to ε′′ (loss factor)

- Phase Shift (φ):

### φ = tan

−1 Q

( I )

This represents how much the wave slows down, which is linked to ε′ (dielectric constant).

3. Converting Phase Shift & Attenuation to Permittivity

The relationship between the phase velocity, attenuation, and permittivity is given by:

k

### m = β − jα

where:

- k complex propagation constant in the medium m =
- β = phase constant (linked to ε′),
- α = attenuation constant (linked to ε′′).

From measured phase shift and attenuation, we estimate:

ε′ =

βc

( ω )

2

ε′′ =

2αc
ω

where:
- c = speed of light (3 · 10 m/s),

8
- ω = 2πf = angular frequency of the radar (for XM125, f = 60 GHz)
- β = (estimated from phase shift across known material thickness ),

φ
d

d

- α = | (estimated from measured attenuation).

ln(A
0

/A)
d
4. Step-by-Step Process to Compute Permittivity
Step 1: Measure Free-Space Reference
- Record I/Q data when no material is present.
- Compute reference phase shift φ and amplitude .
0

A
0
Step 2: Measure Signal Through the Material
- Place the coffee beans in the radar path.
- Collect I/Q data and compute:
- Measured phase shift φ , m
- Measured amplitude A , m

Step 3: Compute Phase Change and Attenuation
- Compute phase constant:

β =

φm−φ0
d
- Compute attenuation constant:

α =

ln A
0

/A
m

( )

d
Step 4: Compute Permittivity
- Compute real permittivity:

ε′ =

βc

( ω )

2

- Compute imaginary permittivity:

ε′′ =

2αc
ω

# Determining Moisture Content of Green Coffee Beans from Permittivity

Since the permittivity (ε | ) of green coffee beans is directly influenced by moisture
r = ε′ − jε′′
content, we can estimate moisture levels by mapping measured permittivity values to known moisture percentages.

Moisture and Permittivity Relationship

1. Water has a high permittivity
- At 60 GHz, water has a permittivity of about ε
| r ≈ 5 − j12
- Dry organic material has a much lower permittivity (~2-3)
- More water content increases permittivity, especially the imaginary part (ε′′), which represents energy absorption
2. Empirical models relate permittivity to moisture

Several empirical relationships exist to relate moisture content (MC, in %) to permittivity. The most commonly used is the Lichtensteiger & Shubert model:

### MC = A · ε′ + B · ε′′ + C

where:
- A, B, C are material-specific coefficients found through calibration
- ε′ = real permittivity (dielectric constant)
- ε′′ = loss factor (absorption due to moisture)

# Using the RoastRite Capacitive Moisture Sensor as a Baseline for XM125 Model Comparison

1. Establish a Controlled Testing Setup

To ensure a fair comparison, both the RoastRite sensor and XM125 should measure the same coffee bean samples under identical conditions (temperature, humidity, bean density, etc.

- Prepare multiple samples with different moisture levels
- Ensure consistent packing density in both measurement steps
- If possible, use ground truth moisture values from oven-drying for additional accuracy (we will most likely not be using these values as we may not have access to this information - something to check in with Josh about)
2. Measure Moisture Content with RoastRite (Baseline Measurement)
- Take readings from the RoastRite for each sample
- Record the moisture content (%) it provides as the baseline truth value
3. Measure Permittivity Using the XM125
- Use the XM125 to measure the real (ε′) and imaginary (ε′′) parts of permittivity for the same samples.
- Ensure the same thickness/density of coffee beans is used in each measurement
4. Develop a Correlation Model Between Permittivity and Moisture Content

Since permittivity is a function of moisture content, we need to map the permittivity values from the XM125 to the moisture values from RoastRite.

- Fit a model of the form:

### MC = A · ε′ + B · ε′′ + C

where:
- MC = moisture content (from RoastRite),
- ε′ = real permittivity (XM125),
- ε′′ = imaginary permittivity (XM125),
- A, B, C = coefficients to be determined via regression.

- Perform a linear regression (or nonlinear regression if needed) to fit the XM125 permittivity values to the RoastRite readings.
5. Evaluate the Accuracy of the XM125 Model
- Compare the predicted moisture content from the XM125 model with the RoastRite moisture readings.
- Compute the Mean Absolute Error (MAE) or Root Mean Square Error (RMSE) to quantify the accuracy.

### MAE =

1
n
i=1

n
∑ MC

XM125 − MC
RoastRite

### RMSE =

1
n
i=1

n
∑ MC

XM125 − MC
RoastRite
( | )
| 2
- If necessary, refine the correlation model based on the observed error trends

# Example Python Script to Calculate Permittivity of Green Coffee Beans

# Example program that takes in I/Q data from the XM125 (both the sample and reference) # Computes phase shift (Δφ) and attenuation (α)

# Calculates permittivity:

# ε′(real part) from phase velocity

# ε′′(imaginary part) from attenuation

# Plots the results

import numpy as np
import matplotlib.pyplot as plt

# Constants

c = 3e8 # Speed of light (m/s)
f = 60e9 # Frequency of XM125 (Hz)
w = 2 * np.pi * f # Angular frequency

def process_xm125_data(iq_data, ref_iq_data, d):
"""
Compute permittivity (epsilon' and epsilon'') from XM125 I/Q data.
:param iq_data: Complex array of I/Q data (measurement with coffee beans) :param ref_iq_data: Complex array of I/Q data (free-space reference) :param d: Thickness of coffee bean sample (meters)
:return: epsilon' and epsilon''
"""
# Compute phase shift

phase_meas = np.angle(iq_data)
phase_ref = np.angle(ref_iq_data)
delta_phi = np.unwrap(phase_meas - phase_ref) # Phase difference beta = delta_phi / d # Phase constant

# Compute attenuation

amp_meas = np.abs(iq_data)
amp_ref = np.abs(ref_iq_data)
alpha = np.log(amp_ref / amp_meas) / d # Attenuation constant

# Compute permittivity

epsilon_real = (beta * c / w) ** 2
epsilon_imag = (2 * alpha * c) / w

return epsilon_real, epsilon_imag

# Example data (replace with real XM125 data)

num_samples = 100
iq_data = np.random.randn(num_samples) + 1j * np.random.randn(num_samples) # Simulated XM125 data
ref_iq_data = np.random.randn(num_samples) + 1j * np.random.randn(num_samples) # Simulated reference
d = 0.01 # Thickness of coffee bean sample (10 mm)

# Compute permittivity

epsilon_real, epsilon_imag = process_xm125_data(iq_data, ref_iq_data, d)

# Plot results

plt.figure(figsize=(10, 4))
plt.subplot(1, 2, 1)
plt.plot(epsilon_real, label="Real Permittivity (ε')") plt.xlabel("Sample Index")
plt.ylabel("ε'")
plt.legend()

plt.subplot(1, 2, 2)
plt.plot(epsilon_imag, label="Imaginary Permittivity (ε'')", color='r') plt.xlabel("Sample Index")
plt.ylabel("ε''")
plt.legend()

plt.tight_layout()
plt.show()

# Handling Variable Thickness (d) in Permittivity Measurements

Since the green coffee beans are irregularly shaped and packed together, the thickness d of the sample won’t be constant. This variability can introduce errors when calculating permittivity.

using a stepper motor to rotate the container is an approach that should be considered because:

- It captures multiple angles, reducing bias from non-uniform packing
- It smooths out variations in thickness, leading to a more reliable permittivity estimate
- It allows for averaging across different paths, minimizing errors from gaps between beans

How to Implement the Stepper Motor Approach

1. Rotate the Container & Collect Data at Multiple Angles
- Mount the container on a stepper motor.
- Rotate in small increments (e.g., 5° per step).
- Take multiple XM125 readings at each step.
- Store the I/Q data at each angle.
2. Estimate the Effective Thickness (d )
eff
- One way is to use a mechanical depth sensor to measure the average depth of beans in the container.
- Another way is to estimate (d ) statistically by averaging phase-based distance
eff
measurements over multiple rotations.
3. Compute Permittivity Using the Average Thickness
- After rotating, computed a weighted average thickness:

d

eff =

1
N
i=1

N
∑ d
i
- Use d in the permittivity calculations to account for variations
eff

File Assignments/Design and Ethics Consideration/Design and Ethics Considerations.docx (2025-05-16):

# COATL mmWave RADAR

# Design and Ethics Considerations

Capstone Team # | 4
Capstone Name | COATL mmWave RADAR
Team members | Henry Sanders, Wallace McKenzie, Chris Kane-Pardy, Kamal Smith

# Design Considerations

Consideration: | Yes/No/ Possibly | Why?
Public health, safety, and welfare | Possibly | While there is no significant direct impact on public health, safety, or welfare, there remains a minor risk associated with potential radar leakage from the container used to measure the moisture content of coffee beans. However, the likelihood and impact are considered very low.
Global factors | No | The use of the XM125 radar for measuring coffee bean moisture content is unlikely to have any global impact. The radar emits minimal energy and operates within non-ionizing radiation parameters, posing negligible risk.
Cultural factors | Possibly | There could be a positive cultural impact, as the introduction of a low-cost, accurate moisture detection method could benefit coffee producers, particularly small-scale and specialty roasters.
Environmental factors | Possibly | Similar to public health considerations, there is a minor potential for radar emissions to leak from the container. However, the environmental impact is expected to be very low and unlikely to affect people, animals, or ecosystems significantly.
Economic factors | Yes | The device has the potential to significantly lower the cost of measuring moisture content in green coffee beans, creating a positive economic impact. This may lead to lower prices across the coffee production and roasting industries, benefiting consumers and small businesses.

# Ethics Considerations

Consideration: | Yes/No/Possibly | Why?
Global | No | There are no expected global ethical concerns associated with this project. The radar device operates at low power and uses non-ionizing radiation, making it safe for widespread use.
Economic | No | No significant ethical issues are anticipated regarding the economic impact of the device.
Environmental | Possibly | From an ethical standpoint, minor environmental concerns could arise if radar emissions were to leak and interfere with nearby devices or living beings. However, the risk is minimal and manageable.
Societal | Possibly | There is a slight ethical consideration regarding societal impacts. Smaller coffee roasters may initially experience slightly less accurate measurements compared to high-end devices like the RM-800 from Roastrite. However, future iterations and improvements to the system are expected to address any performance gaps over time.

Kamal Smith Henry Sanders Chris Kane-Pardy Wallace McKenzie 25 April 2025

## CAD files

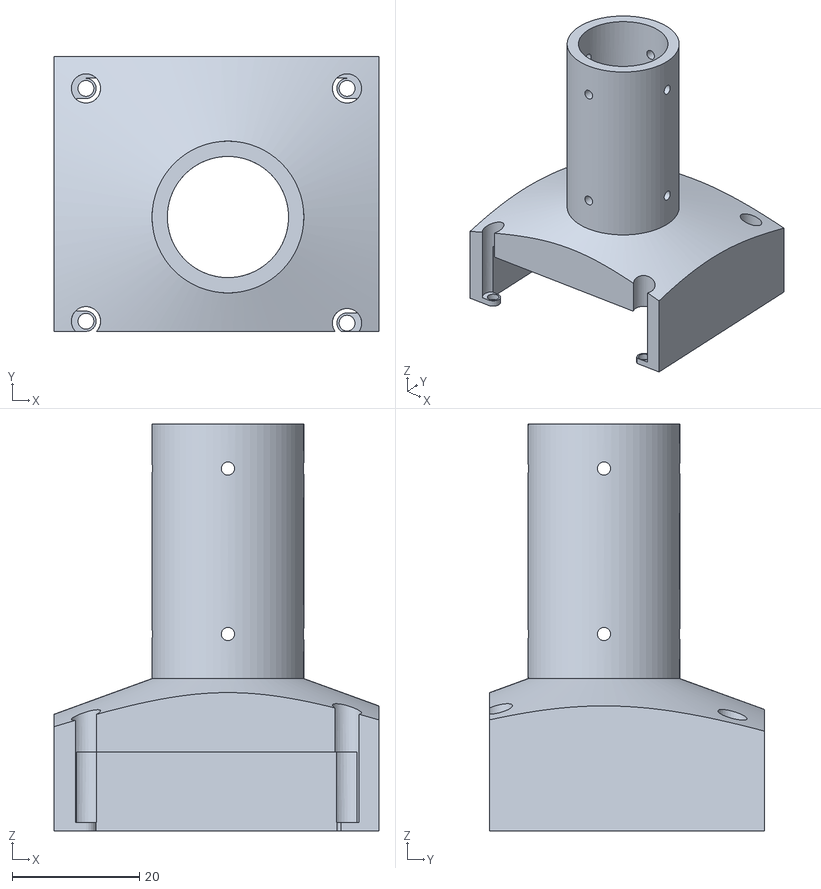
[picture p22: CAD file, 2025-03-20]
3D Modeling/V2.1/Skinny Device Frame.stl
51.0 x 43.2 x 64.0

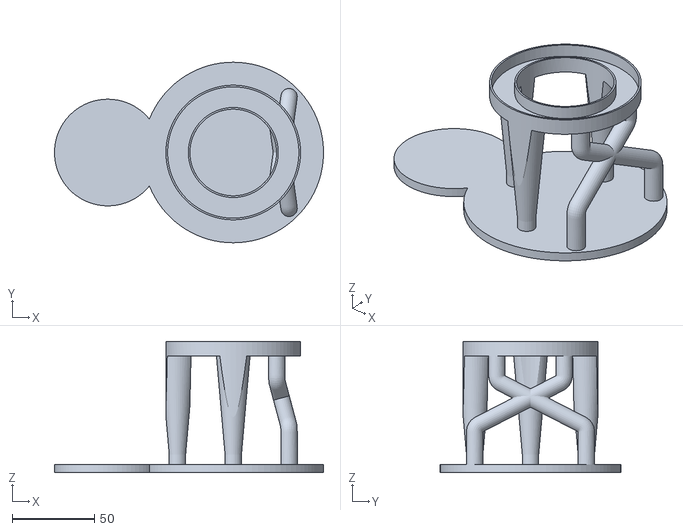
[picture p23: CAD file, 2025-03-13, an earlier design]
3D Modeling/V1.1/Individual Components/Base x 1 (PLA) v1.stl
163.8 x 110.0 x 80.0

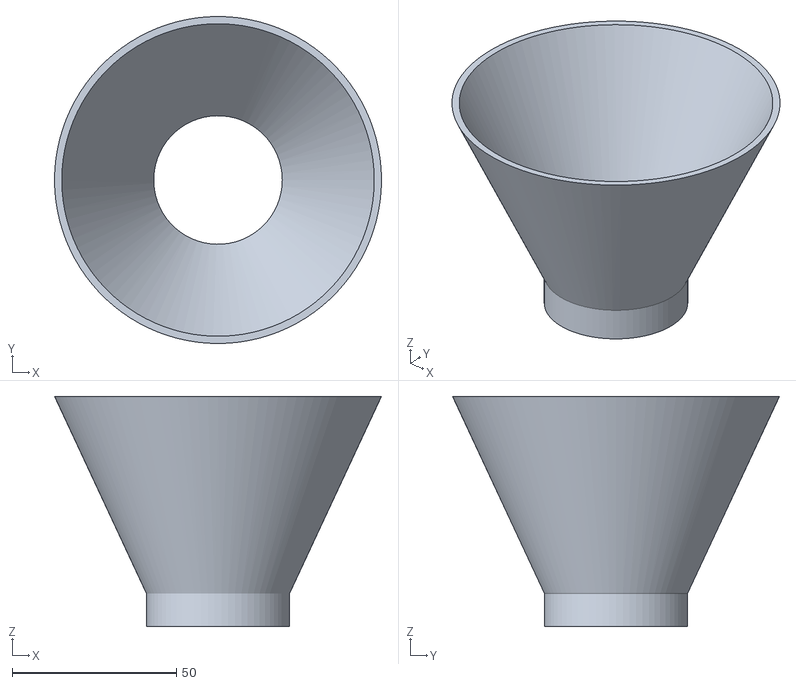
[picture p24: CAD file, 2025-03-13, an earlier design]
3D Modeling/V1.2/STL Files/Beannel x1 (PLA) v1.stl
99.5 x 99.5 x 70.0

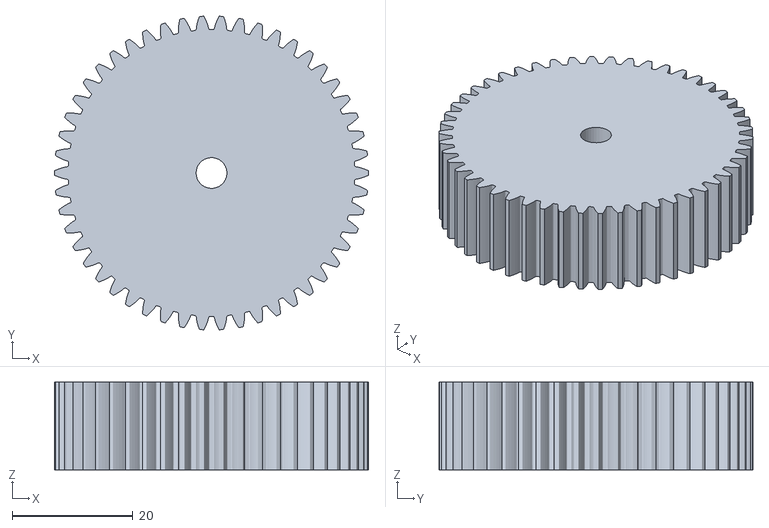
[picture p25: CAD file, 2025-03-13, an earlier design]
3D Modeling/V1.1/Individual Components/Stepper Gear x 1 (PLA) v1.stl
52.0 x 51.9 x 14.5

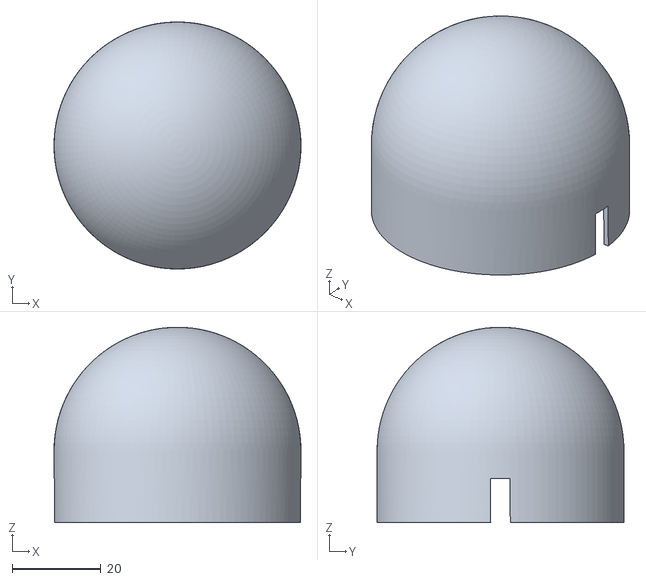
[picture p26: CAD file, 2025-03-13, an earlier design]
3D Modeling/V1.2/STL Files/Lid x 1 (PetG) v2.stl
55.6 x 55.6 x 44.0

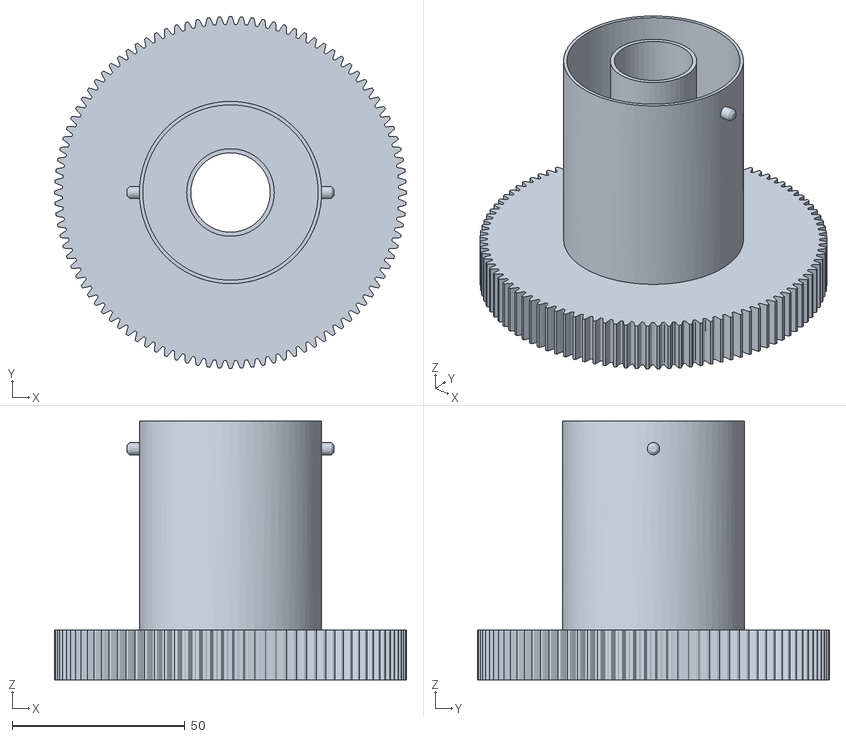
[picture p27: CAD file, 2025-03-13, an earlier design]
3D Modeling/V1.1/Individual Components/Bean Container x 1 (PETG) v1.stl
102.0 x 102.0 x 75.0

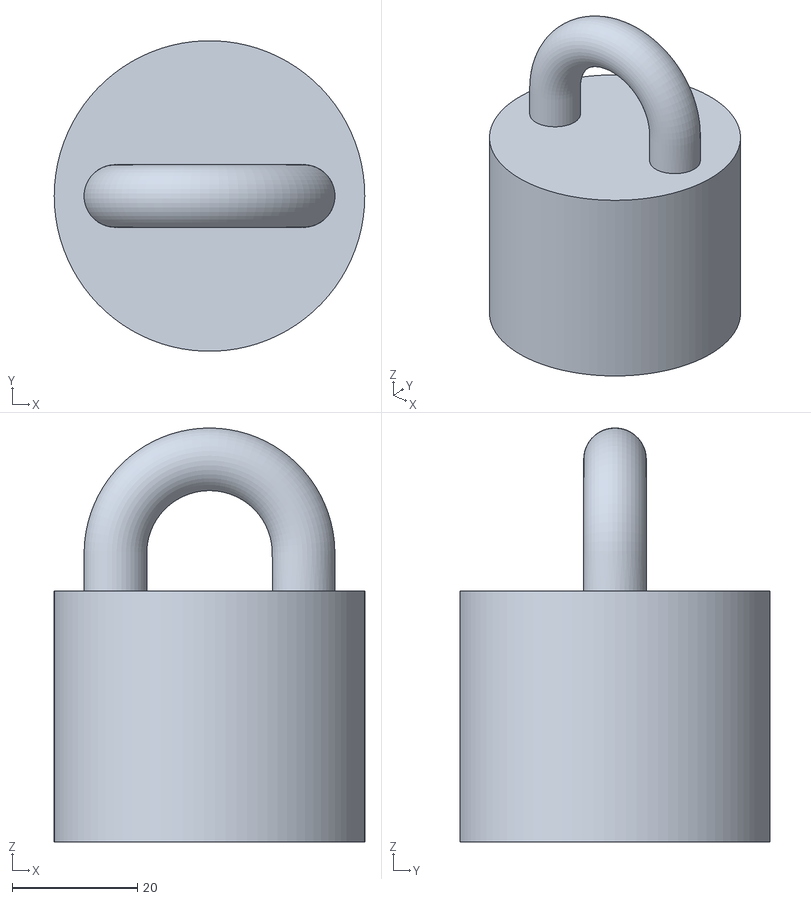
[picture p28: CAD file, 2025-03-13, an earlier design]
3D Modeling/V1.2/STL Files/Bean Plug x1 (PLA) v1.stl
49.5 x 49.5 x 66.0

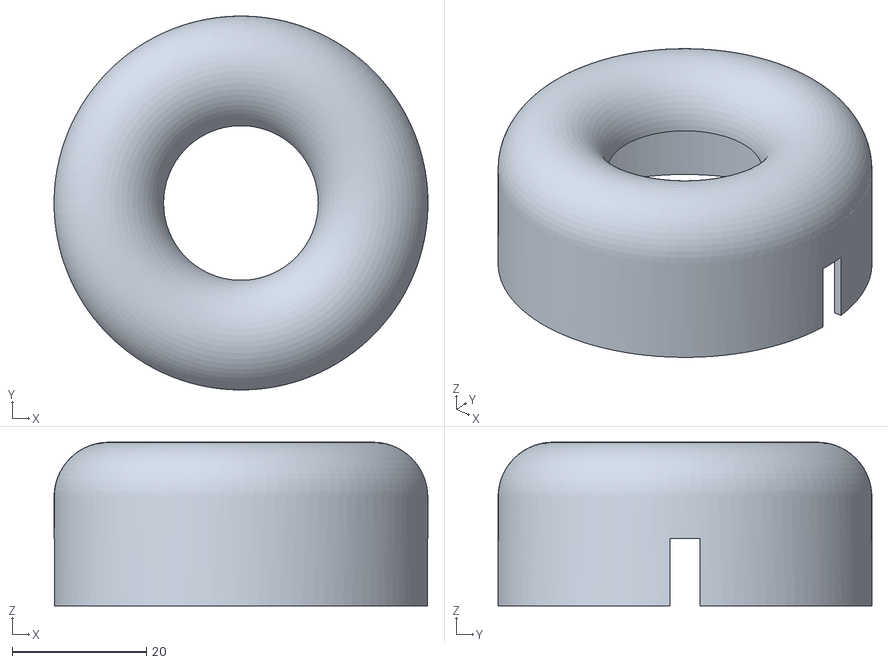
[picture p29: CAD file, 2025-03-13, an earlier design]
3D Modeling/V1.1/Individual Components/Lid x 1 (PETG) v1.stl
55.6 x 55.6 x 24.4

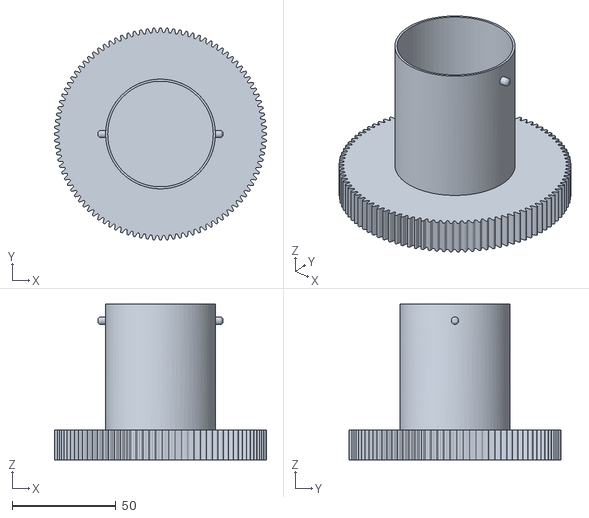
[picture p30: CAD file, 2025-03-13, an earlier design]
3D Modeling/V1.2/STL Files/Bean Container x 1 (petG) v2.stl
102.0 x 102.0 x 75.0

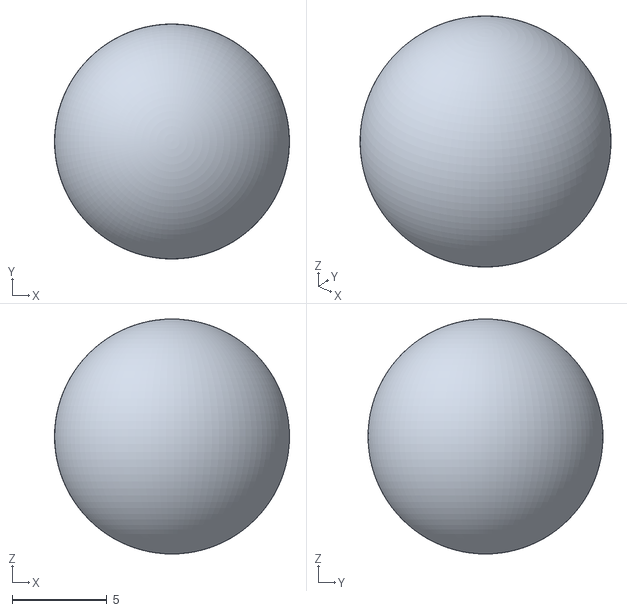
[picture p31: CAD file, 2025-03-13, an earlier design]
3D Modeling/V1.1/Individual Components/Ball x 20 (SLA Resin) v1.stl
12.4 x 12.4 x 12.4

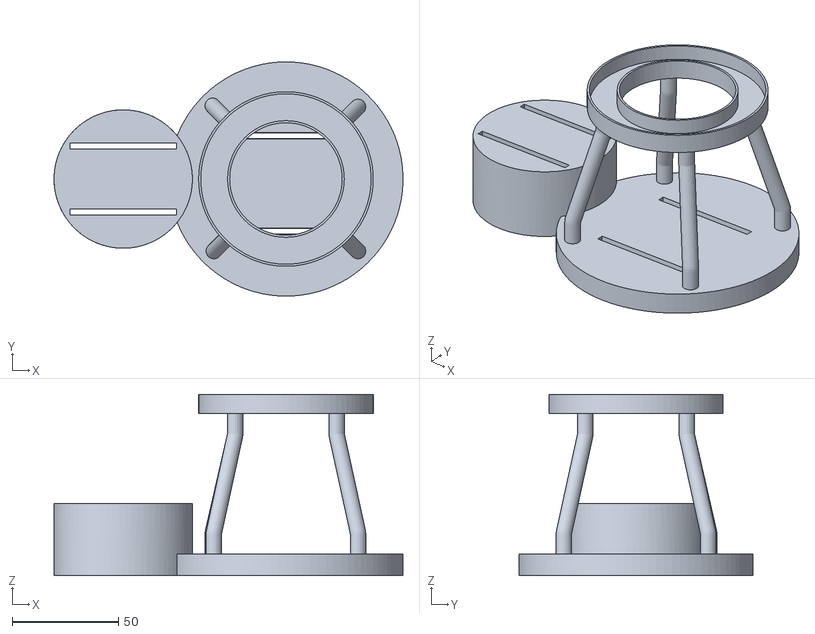
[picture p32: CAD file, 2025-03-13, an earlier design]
3D Modeling/V1.2/STL Files/Base x 1 (PLA) v2.stl
163.9 x 110.0 x 85.0

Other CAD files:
3D Modeling/V1.2/Base x 1 (PLA) v2.f3d
3D Modeling/V1.2/Bean Container x 1 (petG) v2.f3d
3D Modeling/V1.2/Bean Plug x1 (PLA) v1.f3d
3D Modeling/V1.2/Beannel x1 (PLA) v1.f3d
3D Modeling/V1.2/Lid x 1 (PetG) v2.f3d
3D Modeling/V2.1/Skinny Device Frame.f3d

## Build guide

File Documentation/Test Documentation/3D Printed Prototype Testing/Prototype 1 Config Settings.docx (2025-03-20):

XM125 Configuration Settings Brainstorm on 2/11/2025 w/ Henry:

Beans should be ~67.5 mm above the radar face on their side (topmost edge w/o lens)

- Stepper motor top will be 71 +/- 2mm
- We want the radar to pass through the beans at an ODD integer multiple of ~7.5mm (60GHz wavelength = 5mm, 1.5x5mm = 7.5mm) for maximum resolution
- Measurement should have a starting point of 37.5mm (15x2.5mm)to act as a buffer
- The step size should be 1 which is 2.5mm
- The endpoint is at 165mm (51 steps from the start) and should be just past the corner reflector

Since we’re comparing accuracy against the RoastRite, we need to use the same sample size of beans.

- What is the minimum amount of beans that can be used w/ the RoastRite to still produce an accurate reading?
  - 155 mL
- Ask Josh if the RoastRite has an instruction manual.

3D Model Bean Box Dimensions Brainstorm on 2/12/2025 w/ Henry:

The volume of beans measured must be 155mL to match the RoastRite

- The lens of the radar is ~13/16” = 20.65mm
  - To give some leeway to our measurements, we are suggesting a 1.5 inch = 38.1mm pathway for the radar to measure
  - For an Annular Cylinder, the equation for volume is:

V_(AnnularCylinder) =π(h)(r^2 _(outer) -r^2 _(inner) )

  - With the given volume of 155ml (155000 mm^3), and a chosen inner diameter of 1 inch, the inner radius will be 12.7mm
  - With our chosen values, the equation then becomes:

155000_(mm^3) =π(h)((12.7_(mm) +38.1_(mm) )^2 -(12.7_(mm) )^2 )

  - Solving for h yields a height of ~27.12435mm

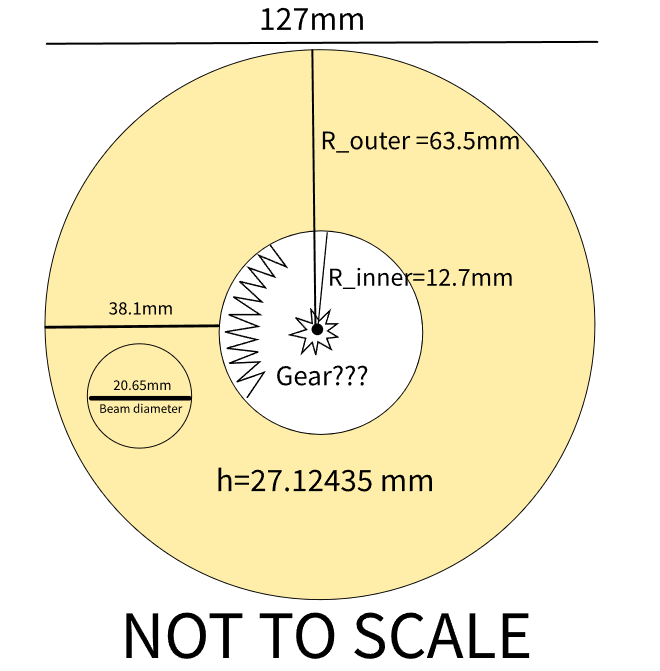
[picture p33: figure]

84.8mm diameter container

5mm shaft diameter

2:1 gear ratio

7.2degree steps

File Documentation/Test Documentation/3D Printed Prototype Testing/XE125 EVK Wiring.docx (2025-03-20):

XE125 Evaluation Board Product Brief (https://www.mouser.com/datasheet/2/1126/XE125_Product_Brief-3133230.pdf)

Power:

The XE125 is powered via the USB connector J1 and/or via the pin header J8. The USB 5V power domain supplies the USB-UART chip (U2). If the USB-UART interface is not used, a dedicated USB

charger can be used.

The power pin header J8 provides the possibility to supply the XM125 module with power from

external power supplies. In Table 1, the pin assignment of J8 is shown:

It seems like the best choice for use, due to both ease and modularity will be to power the device via the USB connector, either in parallel to the ESP-32 from our power supply, or the ESP-32.

DATA:

Inter-Integrated Circuit (I2C) - ESP32-S3 - — ESP-IDF Programming Guide v5.4 documentation (https://docs.espressif.com/projects/esp-idf/en/stable/esp32s3/api-reference/peripherals/i2c.html)

Above is documentation regarding programming I2C on the ESP-32 S3, it’s pinouts are given in the datasheet from the adafruit:

Pinouts | Adafruit ESP32-S3 Feather (https://learn.adafruit.com/adafruit-esp32-s3-feather/pinouts)

From this, it appears that SDA and SCL or the designated I2C connectors will be sufficient.

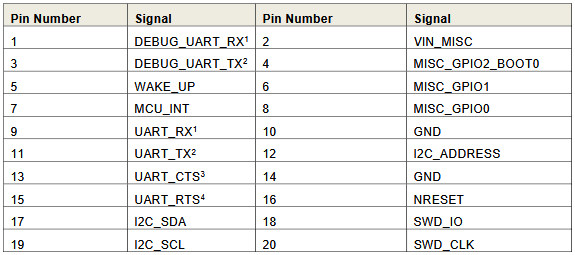
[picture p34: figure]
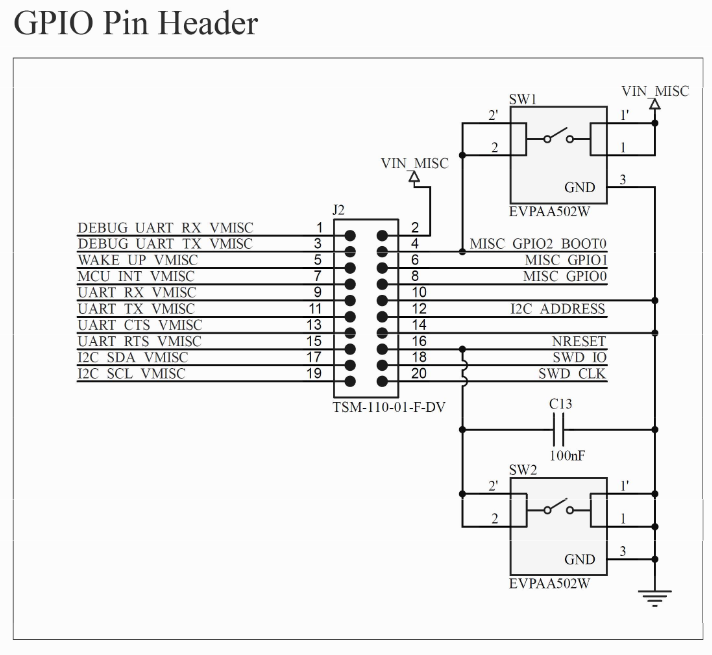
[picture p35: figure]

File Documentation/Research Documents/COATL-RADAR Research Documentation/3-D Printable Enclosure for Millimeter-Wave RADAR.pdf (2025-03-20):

ECE412 Capstone - Team 4 COATL Radar - Wallace McKenzie HenrySanders Chris Kane-Pardy KamalSmith IndustrySponsor: Joshua Mendez Academic Advisor: Mark Martin

# A 3-D Printable Enclosure for Millimeter-wave RADAR AnIn-depthlook at the pros and cons of viable candidates for best millimeter-wave performance

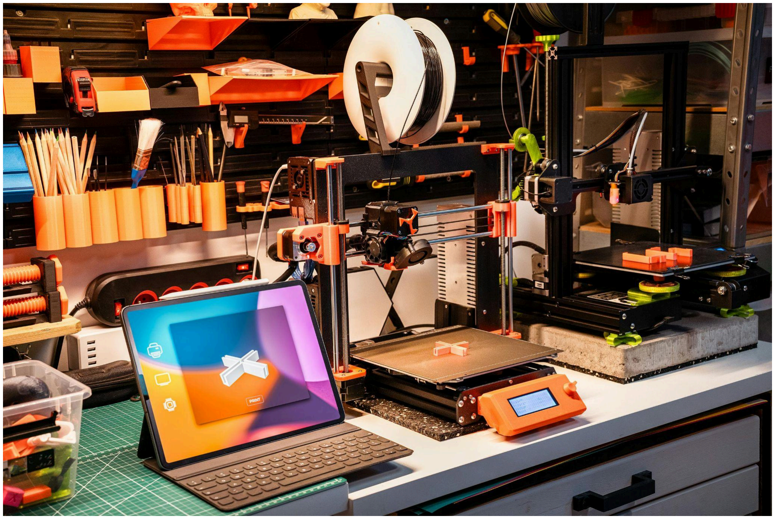
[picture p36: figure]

## Abstract

Coffee. One of the most traded commodities in the world. Roasting coffee is not only an art, but science as well. For this portion of the COATL millimeter-wave radar project, our focus is to find the most suitable material to use, for our Acconeer XM125 60GHz millimeter-wave radar, to detect, with great precision, the amount of water contained in coffee beans. The following research will help to understand the types of filaments that are out on the market for 3D printing enclosure(s), to give the best results. Let's take a look at the first point of contention in these filaments, their use cases, and which one would be best for this portion of the project.

Radar Characterization and Beam Attenuation

Radar Characterization

The XM125 radar, which includes acconeers’ A121 pulsed coherent radar technology, operating at a frequency of 60GHz, but is low power in usage. Due to the nature of this project, and the aim of this report, is to find which materials, shapes, size(s), and properties, the A121, has on the proposed enclosure. By the end of this report, the final summary will include suggestions for, and against, and and all materials which would be viable candidates for the enclosure.

Since reflective materials are a hindrance to the radar beam itself, as well as any materials that attenuate the signal, the comparisons will become more obvious in the final outcomes, and conclusions.

Beam Attenuation

Beam attenuation is of great concern for this project, hence the need to understand the problem statement in detail. We must find a material that minimizes the attenuation of the beam, and its deflection, when the receiver detects, and analyzes the signal. Since signal integrity will determine the data that will be used in the measurement of the coffee beans, and the moisture content therein, we must choose wisely, the density, and thickness of the materials, in addition to the evident chemistries involved with each filament and its production quality. This is the crucial part, in the success of the enclosure, and its intended function.

Filament Material and Properties

Filament Properties

For the function of the enclosure to work as intended, we must first understand the properties of the 3D printing process itself. The outcomes of the desired design and strength of the end product play a pivotal role in the time it takes to 1) print the enclosure, and even the lid, 2) the shape of the enclosure that can be reasonably printed, and 3) the curing/drying process. The best design for the outside of the enclosure, is that of something that supports the entire enclosure, with almost no fragility in the enclosure itself, which is the backbone of the entirety of this project.

For the filament, there are so many manufacturers, and types, that it took quite a bit of time to sort out which would be best utilized, in the creation process. For the remainder of this report, we will discuss, and even review charts, which can provide a process of elimination, for each type of filament.

The ideal properties would be one which does the following: 1) not degrade over time, 2) is not soluble when it comes into contact with moisture/water, 3) is relatively cost effective, 4) has low reflectivity and is transparent to radar, and 5) maintains its structural integrity when under extreme conditions (think heat, moisture, pressure, etc…) .

Filament Material(s) Considerations and Comparisons

Looking at a couple key lines within the above chart, we can see that for price, a majority of the candidates look reasonable, and are cost effective for this project.

Now, as we look at durability, this is one of the parameters that sets these materials apart. Right off the bat, you may notice that PLA (Polylactic Acid), and Carbon Fiber Filled, are quite low with this regard. The best options in this arena are the PETG (Polyethylene Terephthalate Glycol-Modified), Nylon, and Polycarbonate, keeping in mind the price point/cost effectiveness for each of these filaments.

Moving forward to our next area is stiffness. With stiffness, this category is to see how rigid the material is after curing/cooling. For this, the worst is flexible, which is not really an issue, since this will not be considered. The best candidates for this are PLA, HIPS

(High-Impact Polystyrene), PETG, Nylon, and Polycarbonate. This is one that we will need to consider, especially when interacting with the radar beam.

Our next area of study, with regard to categories in material considerations is Ultimate Strength. The worst performers in this category are ABS (Acrylonitrile Butadiene Styrene), Flexible, and HIPS. The best performers for this category are PLA, PETG, Nylon, and Polycarbonate. Take note, these are all with an Ultimate Strength rating of 50 or greater.

Let's take a look at density, as this is one of the key components in the success of this project. Density, when we look more closely at the chart, shows us some of the materials that are not a viable option. Considering radar and the properties of the container, the lesser the density, the least susceptible to radar attenuation or absorption will be likely for the creation of the container. Higher density, has an inverse relationship to the material being transparent/”invisible” to the radar. For this project’s purposes, the lowest density materials are ABS, HIPS, some Nylon, and Polypropylene. For some of the higher density materials, we have Flexible, PLA, PETG, Carbon Fiber Filled, and Polycarbonate. While we want a lower density material, we also want something that has a great rigidity profile, and stability when it comes to the elements.

Another resource for comparing materials, is found at https://www.miprotosolutions.com/post/3d-printed-material-comparison. This site does its comparisons a little bit differently, but has a similar structure to the above data that is found in the below chart (see Table 1).

Lastly, we have a couple more tables, which are similar to decision matrices, and can provide a little more insight, and guide as to the final choice, with regards to 3D printable materials. (Table 2, Table 3)

3D Printer Comparisons (Bambu Labs and Prusa Mk4S)

Achieving precise tolerances in 3D printing involves understanding both the capabilities of your printer and the characteristics of the materials you use. Below is an overview of tolerances for the Bambu Lab printers and the Prusa MK4S, along with considerations for various materials.

Bambu Lab Printers:

Dimensional Accuracy: Users have reported that Bambu Lab printers, such as the X1C, exhibit excellent dimensional accuracy. For instance, a 100 mm dimension may measure approximately 99.7 mm, indicating a minimal deviation of 0.3 mm.

Source: Bambu Labs (https://forum.bambulab.com/t/how-to-tune-your-bambu-printer-for-dimensional-accuracy/25564)
Design Tolerances: When designing parts, a common practice is to incorporate clearances between 0.15 mm and 0.3 mm. Specifically:

Moving Joints: 0.2–0.25 mm clearance

Glue/Screw Joints: 0.15–0.2 mm clearance
Draft/Prototype Prints: Up to 0.3 mm clearance to account for potential inaccuracies in draft settings.

Source: reddit.com (https://www.reddit.com/r/BambuLab/comments/y8f7ak/tolerance_when_designing_parts/)

Calibration: While Bambu Lab printers are known for their accuracy, it's essential to design with appropriate tolerances to accommodate slight variations. Regular calibration and test prints can help ensure parts fit as intended.
Prusa MK4S Printer:

Precision Tolerance: A well-assembled Original Prusa printer typically achieves a precision tolerance of 0.1 mm on the Z-axis and 0.3 mm on the X and Y axes. With additional calibrations, such as extrusion multiplier adjustments and extruder linearity correction, tolerances can be refined to as little as 0.05 mm on all axes.

Source: Prusa Mk4S Printer (https://help.prusa3d.com/article/faq-frequently-asked-questions_1932)

Design Tolerances: For part design:

Tight Fit: 0.15 mm clearance

Reasonable Fit: 0.2 mm clearance

Loose Fit: 0.3 mm clearance

These values serve as general guidelines and may require adjustment based on specific applications and materials.

Source: forum.prusa3d.com (https://forum.prusa3d.com/forum/original-prusa-i3-mk2-s-others-archive/general-tolerances-for-part-design/)

Material Considerations: Factors such as filament diameter consistency, material shrinkage during cooling, and ambient conditions can influence print accuracy. Regular calibration and test prints are recommended to account for these variables.

Source: Print Accuracy (https://forum.prusa3d.com/forum/english-forum-original-prusa-i3-mk4-general-discussion-announcements-and-releases/what-printing-accuracy-can-i-expect/)

3D Printer Comparisons (Bambu Labs and Prusa Mk4S vs FormLabs Form2 & 3)

When comparing the Formlabs Form 2 and Form 3 resin-based 3D printers to the previously discussed Bambu Lab and Prusa MK4S filament printers, it's essential to understand the differences in printing technologies and how they impact tolerances and part accuracy.

Formlabs Form 2 vs. Form 3:

Laser Spot Size and Resolution:

Form 2: Features a laser spot size of 140 microns.

Form 3: Improved with a reduced laser spot size of 85 microns, enhancing the ability to capture finer details.

liqcreate.com (https://www.liqcreate.com/supportarticles/difference-form-2-form3-formlabs)

Dimensional Accuracy:

Form 2: Users have reported achieving tolerances within ±0.015 inches (±0.381 mm).

reddit.com (https://www.reddit.com/r/3Dprinting/comments/rx2597/formlabs_form3_form3l)

Form 3: Some users have observed parts being consistently oversized by approximately 0.4%, with limited options for fine-tuning the X/Y axes.
forum.formlabs.com (https://forum.formlabs.com/t/part-accuracy-and-tolerances-on-f3/26510)

Support Structures and Surface Finish:

Form 3: Introduces light-touch support structures with thinner tips, making parts easier to remove and reducing surface imperfections.

liqcreate.com

User Feedback(FormLabs):

Some users have expressed a preference for the Form 2 over the Form 3, citing calibration capabilities and long-term reliability.
forum.formlabs.com (https://forum.formlabs.com/t/two-years-in-why-i-like-my-form-2-better-than-my-form-3/33671)

Comparison with Bambu Lab and Prusa MK4S:

Printing Technology:

Formlabs Form 2 and Form 3: Utilize Stereolithography (SLA) technology, curing liquid resin with a laser to produce parts.

Bambu Lab and Prusa MK4S: Employ Fused Deposition Modeling (FDM), extruding melted filament layer by layer.

Dimensional Accuracy and Tolerances:

SLA Printers (Formlabs): Capable of achieving high-resolution prints with fine details, but may require calibration to maintain dimensional accuracy.

FDM Printers (Bambu Lab and Prusa): Generally offer good dimensional accuracy, with tolerances typically around ±0.1 mm, depending on calibration and material used.

Material Considerations:

SLA: Offers a wide range of resins with varying mechanical properties, but parts may require post-curing and can be more brittle.

FDM: Supports a variety of thermoplastics, each with unique properties affecting shrinkage and tolerance.

Design Adjustments: Consider the specific characteristics of the chosen printing technology and material when designing parts, accounting for factors like shrinkage, support removal, and post-processing requirements.

For a visual comparison and more in-depth insights into the differences between the Formlabs Form 2 and Form 3, you might find the following video informative:
Formlabs Form 3 vs. Form 2 | See What's New (https://www.youtube.com/watch?v=D6Gbn2zOVL4)

This video provides a side-by-side comparison, highlighting the advancements and changes introduced in the Form 3.

Material Summaries (Finalized list):

PLA (Polylactic Acid): A biodegradable, easy-to-print filament with high rigidity and dimensional accuracy but poor moisture resistance and radar transparency due to its density.

ABS (Acrylonitrile Butadiene Styrene): Durable, impact-resistant, and moisture-resistant, but prone to warping and moderate radar attenuation. Requires controlled printing environments.

PETG (Polyethylene Terephthalate Glycol): Combines strength, flexibility, and moisture
resistance with moderate radar transparency, making it a versatile option. Prints easily compared to ABS.

Nylon: Strong, flexible, and moisture-resistant but highly hygroscopic, requiring drying before and after printing. Radar transparency varies based on density.

Resin (Formlabs SLA): High-resolution prints with smooth surfaces; moisture-resistant resins available. Radar performance depends on resin composition but typically offers high density and low transparency.

Final Summary and comparisons, with recommendation:

Recommendation for Radar Transparency > Moisture Resistance > Durability > Printability priorities (from left to right, left being highest priority):

PETG – Balanced radar performance, moisture resistance, and printability.

Nylon – Good radar transparency and moisture resistance, though printing complexity is higher.

PLA – Easy to print but moisture resistance is low and density may reduce radar performance.

ABS – Strong and moisture-resistant but radar transparency is moderate.

Resin – Precise, moisture-resistant, but potentially poor radar performance and brittle.
PETG likely provides the best tradeoff for the coffee bean XM125 radar enclosure.

Reference Charts/Tables for the above mentioned specifications:

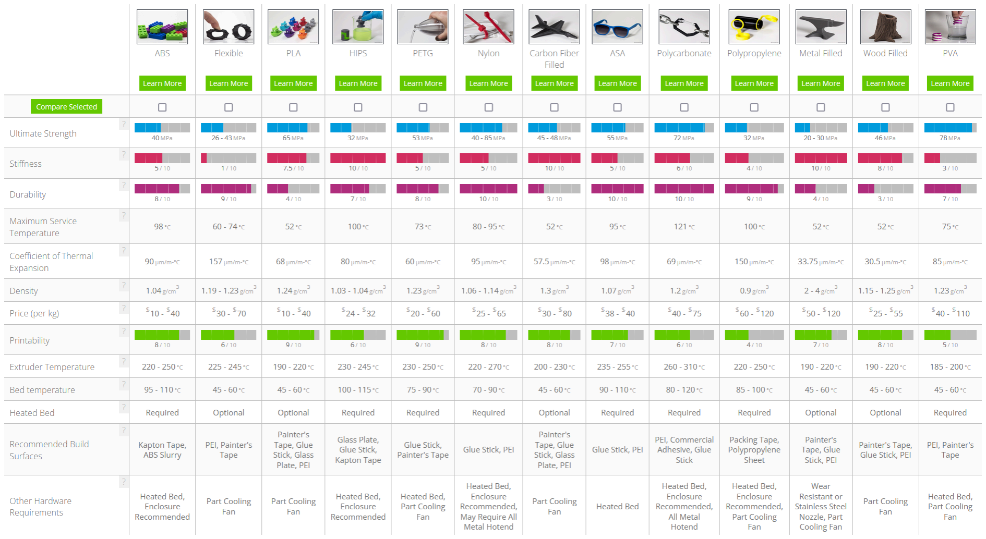
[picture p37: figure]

Table 1 Comparison of FDM and SLA Printing Materials

Category | SLA Resin | PETG (Best FDM Choice) | Polycarbon ate (PC) | Polypropylene (PP)
Moisture Resistance | ✅ Excellent | ✅ Excellent | ✅ Excellent | ✅ Excellent
Durability | ⛔ Brittle (unless tough resin) | ✅ Good | ✅✅ High | ⛔ Moderate
Printability | ✅✅ Very High Precision | ✅✅ Easy | ⛔ Hard (warping issues) | ⛔ Hard (adhesion issues)
Density (g/cm³) | 🔹 ~1.1 - 1.2 | 🔹 1.23 | 🔹 1.2 | 🔹 0.9
Radar Transparency | ⛔ Uncertain (may absorb waves) | ✅ Likely Good | ⛔ May Block Signals | ✅ Likely Best

Table 2 Best Candidates of FDM and SLA Printing Materials - Best Candidates Side-by-side

Material | Density (g/cm³) | Considerations for Radar & Structure
Polycarbonate (PC) | 1.2 | Strong and durable but could interfere with mmWave signals.
PETG | 1.23 | Good strength, moderate density, and likely decent radar transparency.
PLA | 1.24 | Easy to print but may absorb moisture and is not ideal for long-term use.
ABS | 1.04 | Good strength but less radar transparent. Requires an enclosure when printing.
Nylon | 1.06 - 1.14 | Durable but absorbs moisture over time, which could alter its properties.
Polypropylene (PP) | 0.9 | Least dense, great for radar transparency, but difficult to print reliably.

Table 3 Best Candidates of FDM and SLA Printing Materials - Density

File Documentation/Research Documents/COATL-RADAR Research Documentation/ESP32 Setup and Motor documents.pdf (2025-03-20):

## SETUP INSTRUCTIONS - Kamal Smith

Links to things used in this document

https://circuitpython.org/ (lightweight easy to use python library specifically for microprocessors) https://learn.adafruit.com/welcome-to-circuitpython/the-repl (Circuit python How to) https://learn.adafruit.com/circuitpython-essentials/circuitpython-essentials (Useful Circuit python info)
https://docs.circuitpython.org/projects/motorkit/en/latest/ (Motorkit library for turning motor) https://codewith.mu/ (Easy to use IDE for testing, works well with circuitpython) https://docs.espressif.com/projects/esp-idf/en/v5.4/esp32s3/get-started/index.html (esp32 setup) https://learn.adafruit.com/adafruit-esp32-s3-feather/factory-reset (To reset board to fac settings) https://learn.adafruit.com/adafruit-esp32-s3-feather/pinouts (this is not the 4MiB flash board, may be different)
https://components101.com/motors/nema17-stepper-motor (Not actually the right stepper, but one of the only datasheets I could find)

If you plan on using other IDEs you may need the following https://github.com/adafruit/Adafruit_CircuitPython_Bundlehttps://github.com/adafruit/circuitpython-build-tools
You can find requirement.txt files inside the libraries if you need to install certain tools

To place the board into serial mode for flashing
1. While holding the boot button
2. Press Reset
3. Lights should turn off, now you can program things to it.

You can also just plug the device in while holding the boot to put it into serial mode

Flashing the board (First two steps are documented, but may not be necessary)
1. First, you need to get esptool onto your system by following this link https://docs.espressif.com/projects/esptool/en/latest/esp32s3/ . This will instruct you on installing the esptool to your system. (NOTE: “pip install esptool.py” might not work on certain systems, so try “pip install esptool”) there are more detailed instructions in the link if this does not work.
2. Now connect the ESP32S3 to your computer and run the “esptool -p PORT flash_id” with the port being the name of the serial port. (NOTE: I had to unplug the device and while holding the boot button plug it in to put it in serial mode for this to work. Recheck the port on Windows because it might change!).
3. After this has been done, it's time to put circuitpython on the board. Run “esptool erase_flash” on your command prompt. If it does not automatically detect your boards port, try running “esptool --port PORTNAME erase_flash”. (NOTE: the – is a double dash and on windows the PORTNAME will be something like COM4).

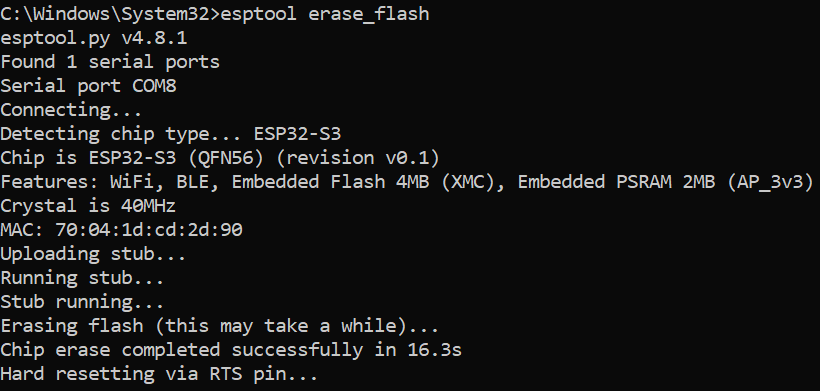
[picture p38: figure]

Figure 1: Example of esptool erase_flash
4. Now to deploy the firmware to the device run “esptool –baud 460800 write_flash 0 ESP32_BOARD_NAME-DATE-VERSION.bin” Feather ESP32-S3 4MB Flash 2MB PSRAM Download (https://circuitpython.org/board/adafruit_feather_esp32s3_4mbflash_2mbpsram/) with the .bin file found on this page. (NOTE: pay attention to the .bin file you download. We are using the firmware for 4MiB flash). You will then replace ESP32_BOARD_NAME-DATE-VERSION.bin with the path to the .bin you just downloaded.

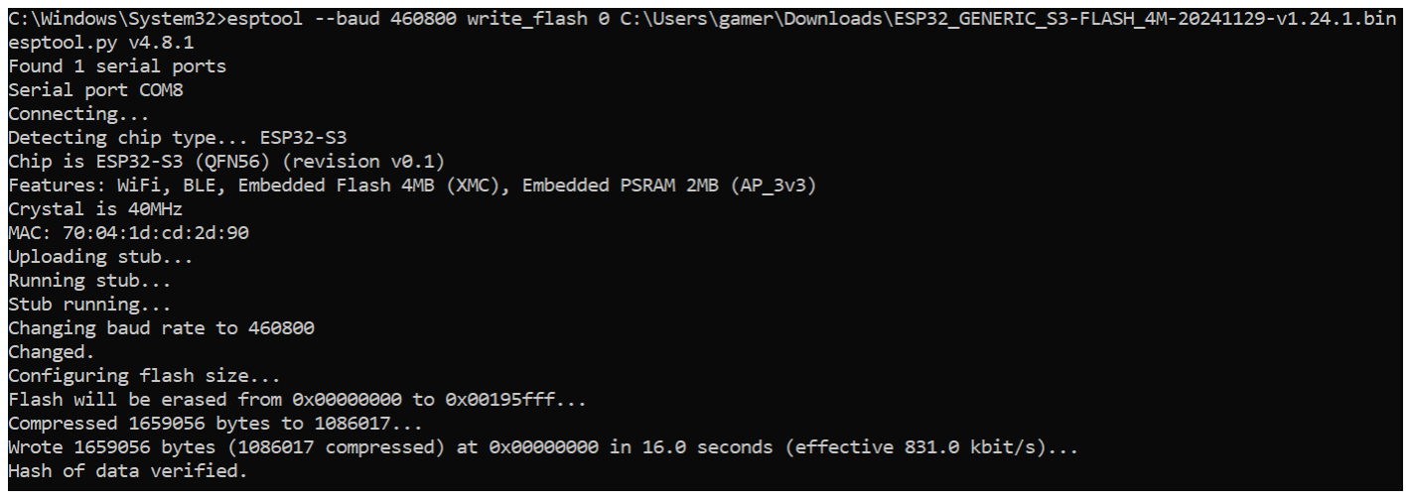
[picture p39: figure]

Figure 2: Example of flashing using the .bin provided

Side note : There is an online ESP32 factory reset tool that may make things easier, but when I tried using it I never got it to work so instead opted for the manual method. When you get to the final steps when you are loading the .bin file, you need the entire location of the bin file not just the name of the bin file.

MAKING THE MOTOR MOVE

https://learn.adafruit.com/keep-your-circuitpython-libraries-on-devices-up-to-date-with-circup/inst all-circup (https://learn.adafruit.com/keep-your-circuitpython-libraries-on-devices-up-to-date-with-circup/install-circup) (For updating libraries on circuit python)
https://www.adafruit.com/product/2927

https://learn.adafruit.com/adafruit-stepper-dc-motor-featherwing/pinoutshttps://learn.adafruit.com/welcome-to-circuitpython/library-file-types-and-frozen-libraries (converting py to .mpy)

https://learn.adafruit.com/adafruit-stepper-dc-motor-featherwing/circuitpython (documentation for featherwing addon)

Below is the wiring for the STEMMA QT header that we are using for the motor to connect by I2C.

- Red - 3.3VDC Power
- Black - Ground
- Blue - I2C SDA Data
- Yellow - I2C SCL Clock
1. Connect your red and black cable to the Logic power pins as shown below. I tested mine using the 3.3V power to the pin closest to the mounting hole, with GND in the other.

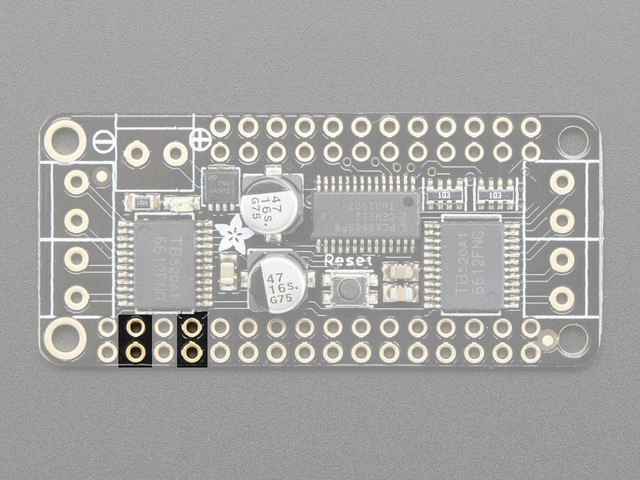
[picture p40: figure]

Image 3 : Adafruit showing the logic power pins on the featherwing NOTE: Pay attention to the reset button, this is the best way to tell the orientation of the featherwing board.

2. Next connect your SCL and SDA lines with SDA (Blue) being the closest to the mounting hole, and SCL (Yellow) being the one next to it.

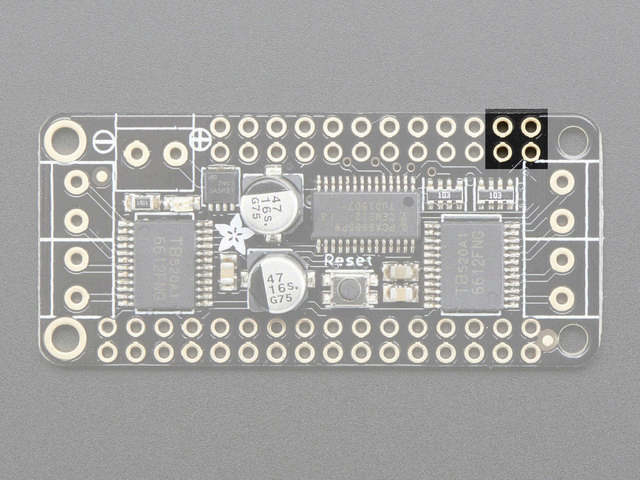
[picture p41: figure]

Image 4: Adafruit showing the I2C Data pins on the featherwing

3. Now to power it you will need to provide a Maximum of 12V. For testing, I used a simple 9V battery providing 5V of power. You will need both your power and ground.

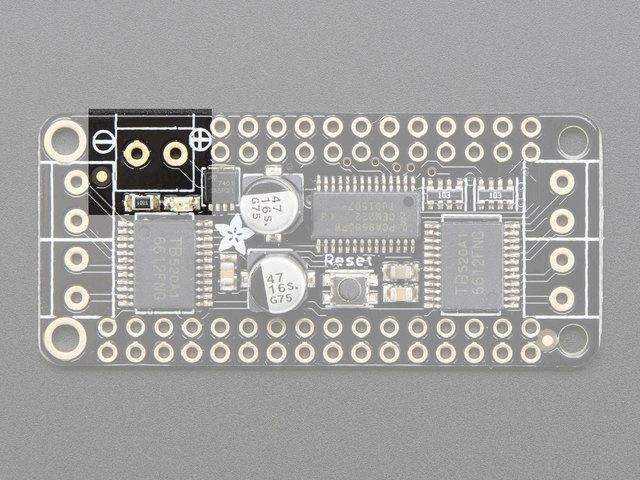
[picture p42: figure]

Image 5: Adafruit showing the power pins on the featherwing

4. The Stepper motor is still being tested, but my current working setup is posted below. The orientation of the input is a little twisted in the photo, so pay attention when plugging in.

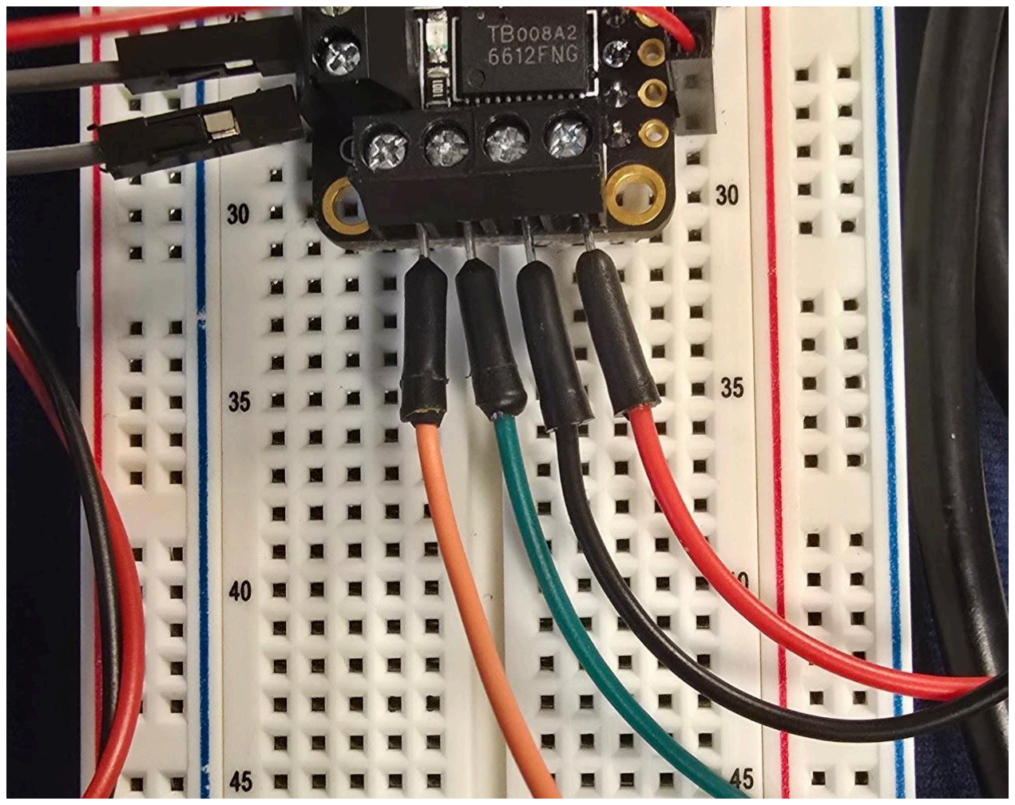
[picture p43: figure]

Image 6: Test setup wire input for motor

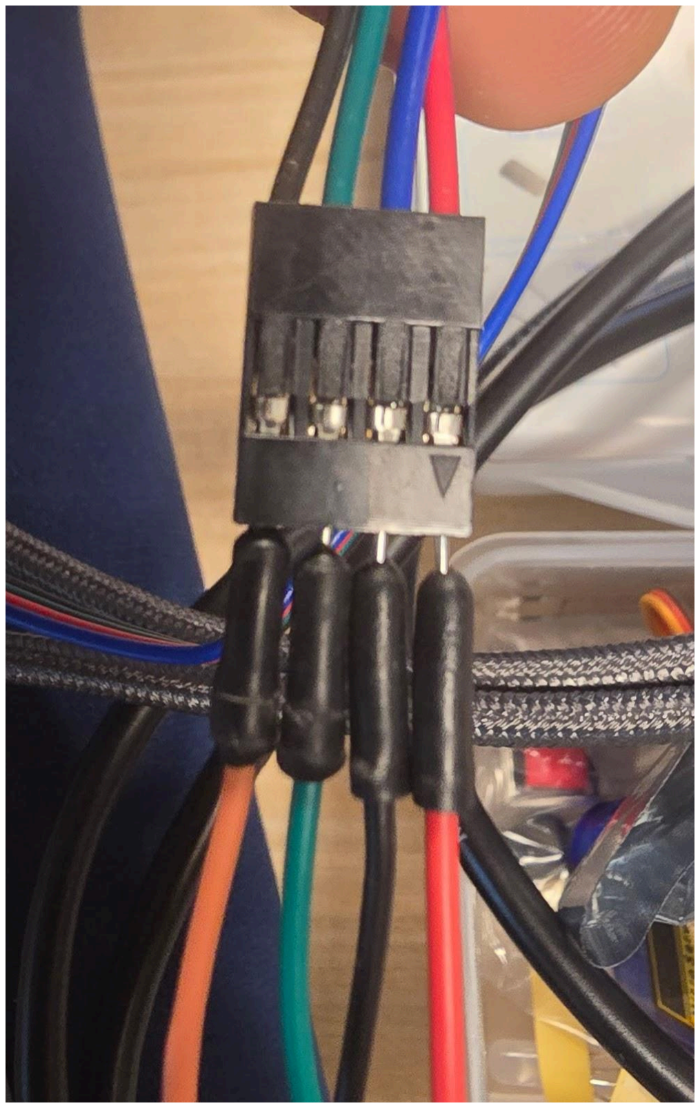
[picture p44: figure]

Image 6: Test setup wire input for motor with the orientation arrow

INTERFACING ESP32 TO XE125

https://learn.adafruit.com/introducing-adafruit-stemma-qt (This could help if we are running into issues)
https://www.sparkfun.com/qwiic (Can save us if we absolutely need it and can’t get the I2C to connect)

https://docs.circuitpython.org/en/latest/shared-bindings/microcontroller/index.html#micro controller.Pin (https://docs.circuitpython.org/en/latest/shared-bindings/microcontroller/index.html) (Documentation for Circuit python syntax)

https://learn.adafruit.com/circuitpython-essentials/circuitpython-i2c (I2C Notes)

https://circuitpython.org/libraries (Libraries for the circuit python)

https://learn.adafruit.com/adafruit-qt-py-esp32-s3/i2c

IDE SETUP
For this I am using the online code.circuitpython.org which is an online easy to use IDE for devices with circuit python on it.
1. To connect to the IDE with Circuitpython, you need to make sure your device is seen by Windows as a separate drive/ removable device. If flashed properly, this should work when you plug it in. This will allow you to open the device's files like any other drive.
2. When you connect the device, select the COM port that Windows is detecting. This was COM13 for me.
3. After you have selected the COM port, you will be asked what folder you would like to use. Select the root folder of the CIRCUITPY device that you have plugged in and continue.
4. The code that is currently on the board will show up as “code” and will be a python file. DO NOT CHANGE THE NAME OF THIS. While I am not sure if it actually messes things up, I was having issues whenever I renamed this file.

*SIDE NOTE* If your code is not saving, try pushing the reset button on the ESP32, this fixed my issues.

Wiring to XE125

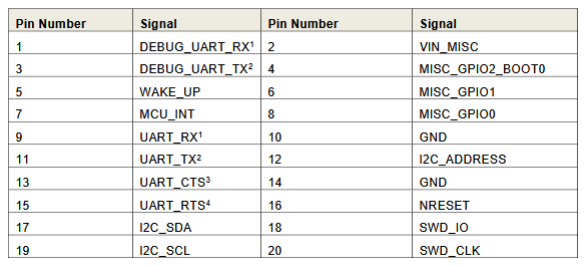
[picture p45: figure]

For this, we will be focusing on GND, pin 5,7,12,17 and 19. I2C_address can be set high,low or not connected.

XE125_I2C_Address = 0x52

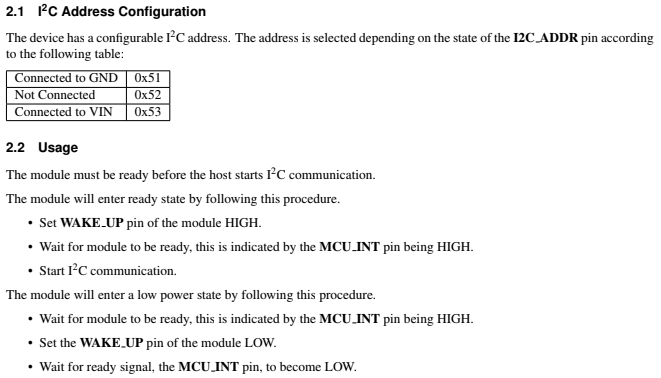
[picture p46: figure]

https://developer.acconeer.com/home/a121-docs-software/

Make Sure the ESP32-S3 and the XE125 share a common ground

Set WAKE_UP pin HIGH and check the MCU PIN before trying I2C processes

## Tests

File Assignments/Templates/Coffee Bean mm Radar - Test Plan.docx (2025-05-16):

# Coffee Bean mm Radar Test Plan

2025/04/04

# Overview

The major objective of this project is to use the XM125, measure coffee beans of varying moisture content, and sizes, then catalog those results in a spreadsheet. The key is to create consistent results, while determining the absolute minimum amount of measurements to get the best readings.

# System Radar Test Plan v1.0

Date of Test: | 2025/04/04
Tester: | Kamal Smith

## Purpose

Measure coffee beans with varying moisture content, using Pulsed Coherent Radar(PCR) device, and comparing those results to the Roastrite RM-800, which uses capacitive dielectric density/Volumetric Mass Density for its measurement capabilities.

## Equipment Needed

- System Equipment
  - Acconeer XM125 (A121 and XE125 sensors on the development board)
  - Acconeer Exploration Tool
- Test Equipment
  - Python Scripts (uses the Acconeer Exploration tool to interface with the Radar sensor
- Other Equipment
  - Within the ecosystem of python, using Pytorch, for machine learning utilization, in taking measurements, to detect the percent moisture content.

## Pre-Test Setup

1. Plug-in the XM125 into the laptop, via USB-C cable.
2. Open Python, and load the script to prepare for measurements.
3. Measuring the weight of coffee beans, to maintain consistency for the density of the coffee beans.
4. Fill the Beanis, in preparation for the measurements, with the coffee bean sample.

## Top Down Test Steps

1. Turn on the power switch.
  a. LED should turn on: ☐ Tests: power on indicator requirement
2. Measure 5V output, should be 5 ± 10% V: _________ V

## Post-Test Teardown

1. Unplug….
2. …

## Top-down Test Plan Conclusions / Discussion

Any further notes go here.

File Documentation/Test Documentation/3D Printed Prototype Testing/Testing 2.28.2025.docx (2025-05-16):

Test Plan 1: Locational Noise Readings - No beans*

*Using Fresnel Zone Plate lens

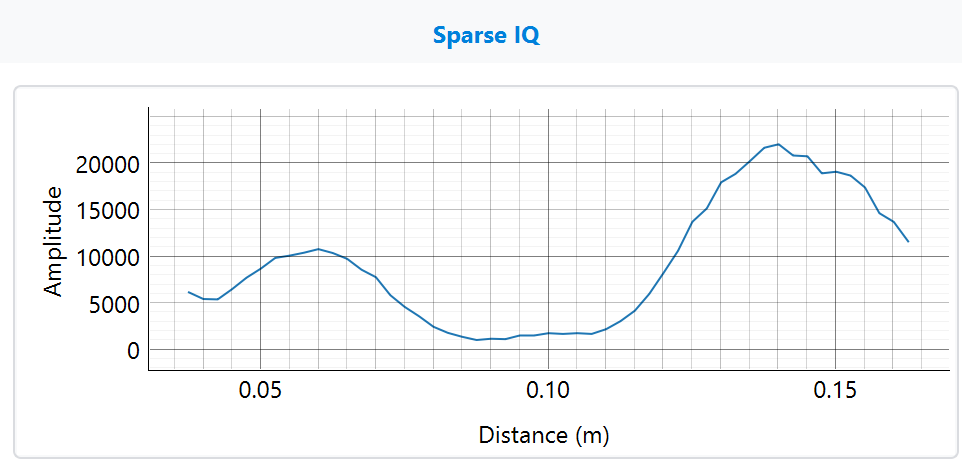
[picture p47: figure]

Figure 1: Balloon Lab - Black PETG

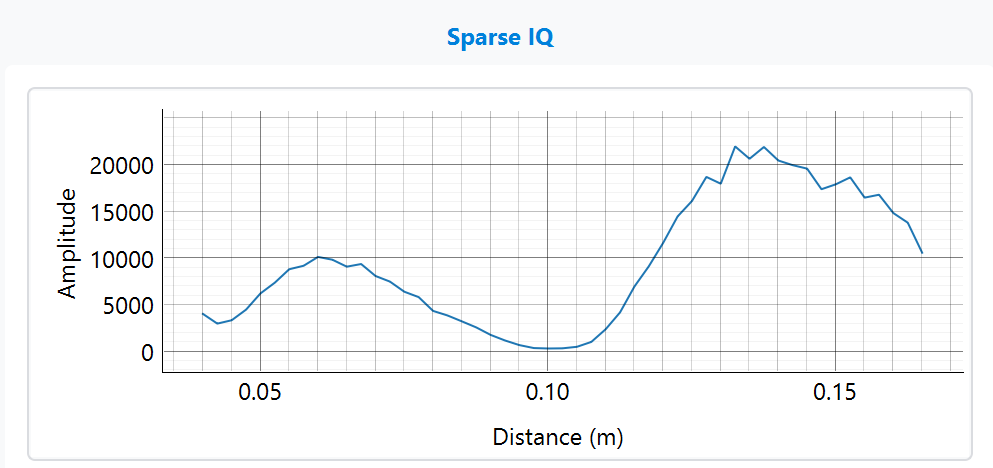
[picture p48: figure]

Figure 2: Balloon Lab - Orange PETG

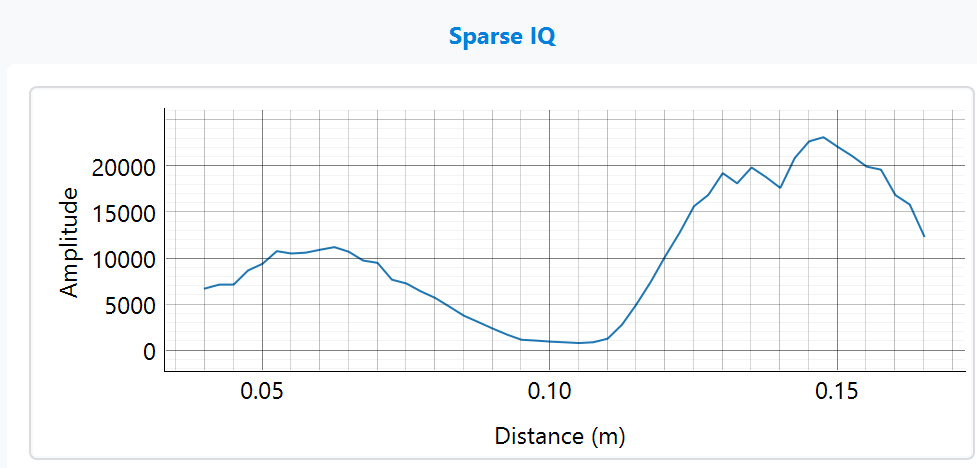
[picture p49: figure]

Figure 3: Tek Lab - Black PETG

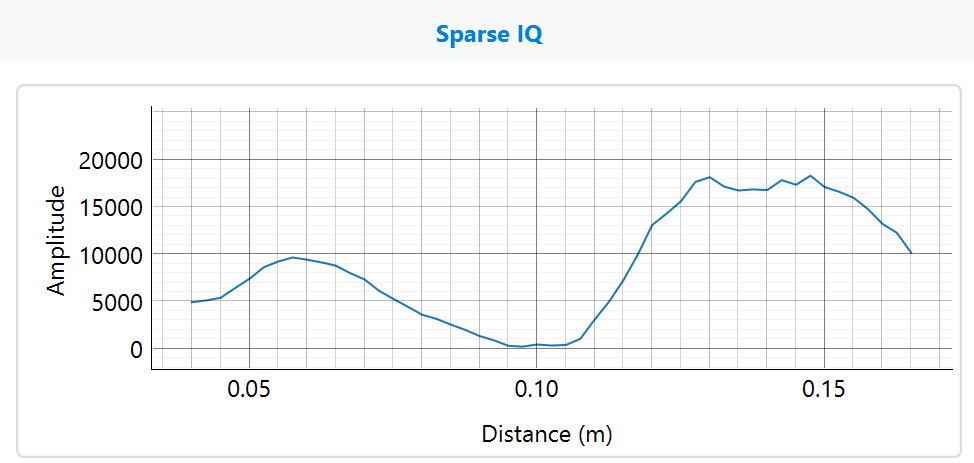
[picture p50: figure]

Figure 4: Tek Lab - Orange PETG

FZP (ridges up) D2:

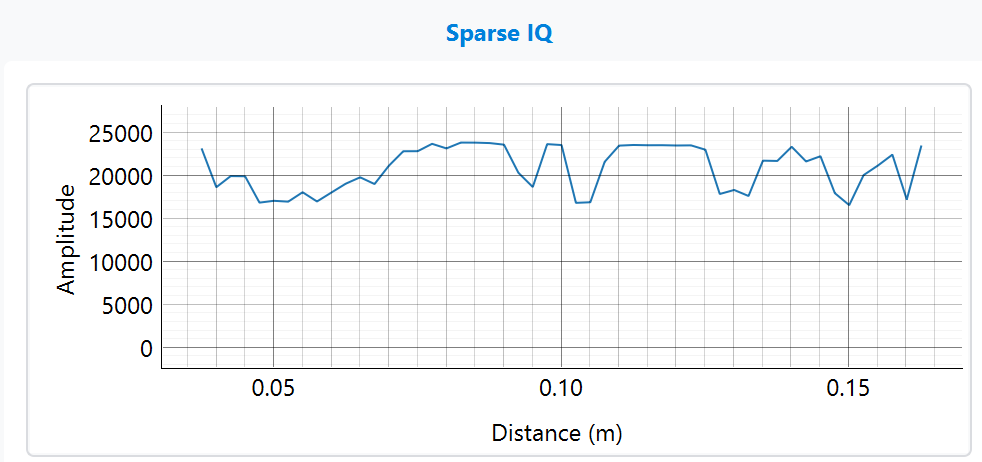
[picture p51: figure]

FZP (ridges up) D1:

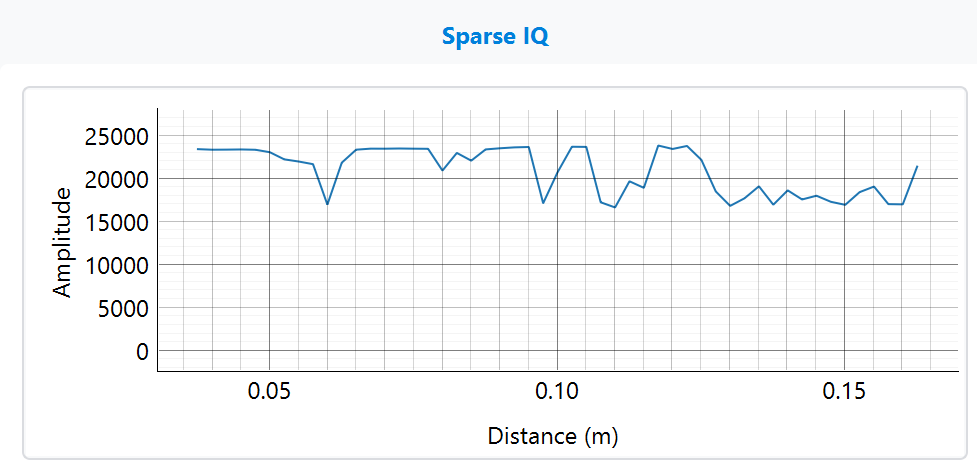
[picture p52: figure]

FZP (ridges down) D2:

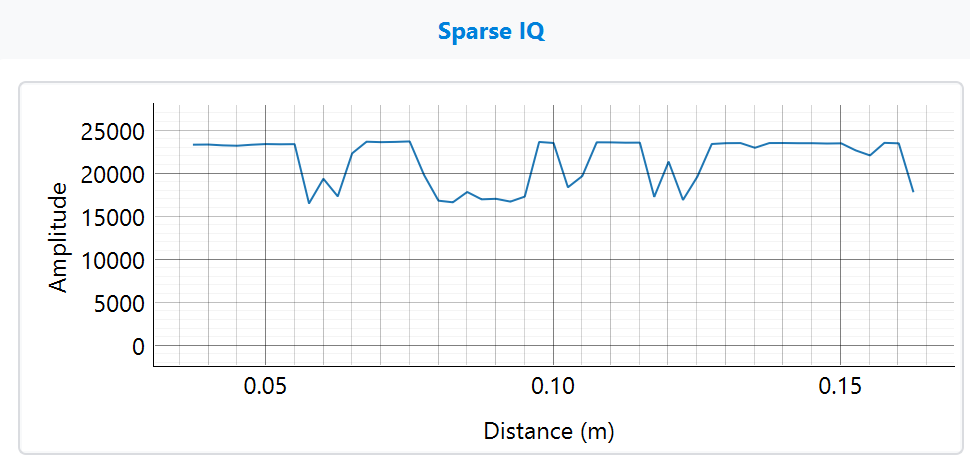
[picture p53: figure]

FZP (ridges down) D1:

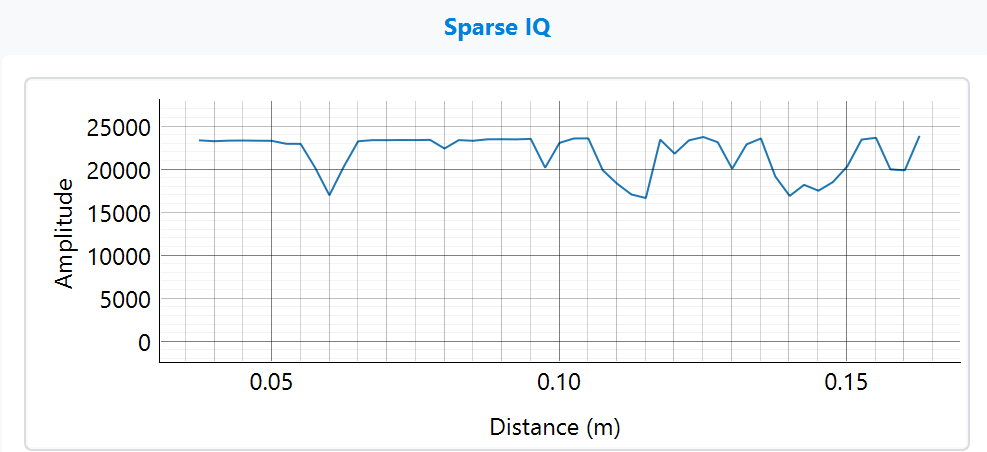
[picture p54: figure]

Parabolic D1:

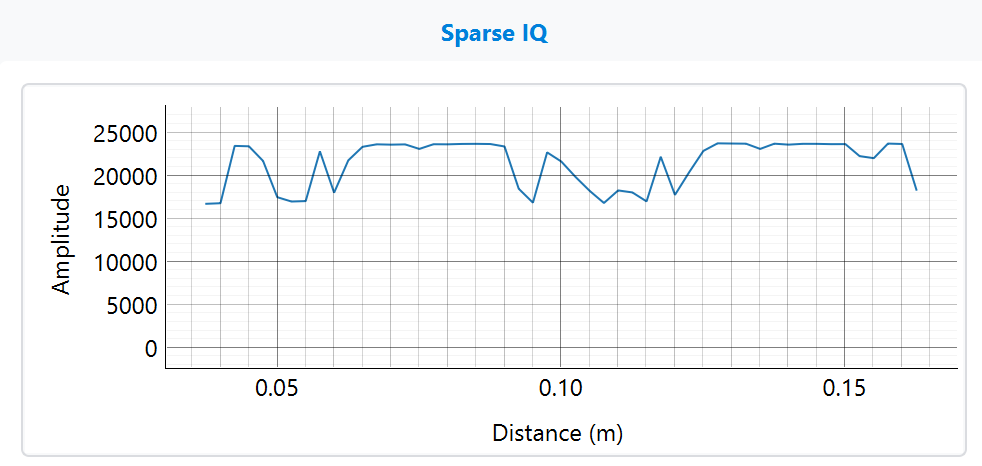
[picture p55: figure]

Parabolic D2:

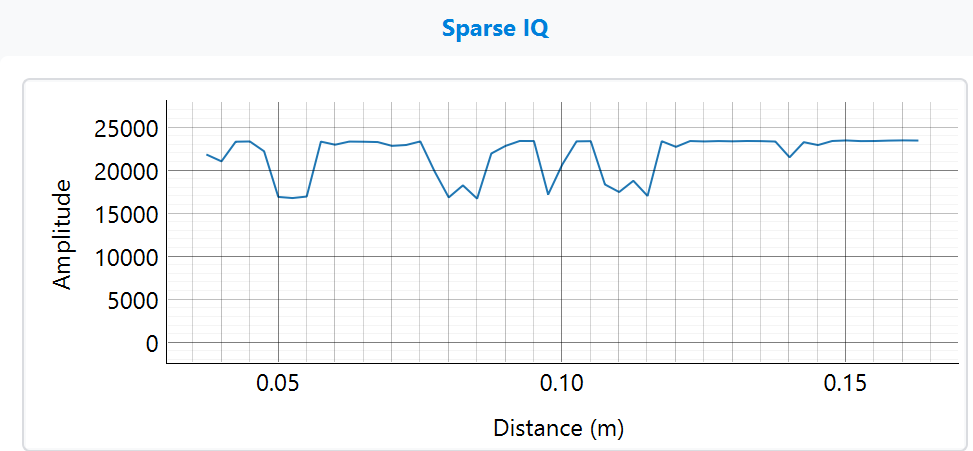
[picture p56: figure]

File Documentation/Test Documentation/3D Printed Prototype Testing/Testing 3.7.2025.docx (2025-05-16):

PETG Beannel Testing - Parabolic Lens, Flat lens on top to act as bean container, circular corner reflector

RoastRite Moisture Meter Readings:

- Sweet Maria’s: 9.8%
- Tailored Pulped Natural Brazil: 8.9%
- Comicovel: 7.6%


Baseline - No beans


Sweet Maria’s - Flat layer of beans


Tailored Pulped Natural Brazil - Flat layer of beans


Comicovel - Flat layer of beans


Beanis - No Beans


Beanis -

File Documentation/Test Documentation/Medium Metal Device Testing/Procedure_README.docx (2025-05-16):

1. Run the program with no beans and a reflector so that it can calibrate
2. When the program finishes calibration, add the beans to the MedBeanis. Pay attention to the “SettingsUsed” picture in the folder, it says the amount used.
3. Continue the program
4. When the bean scan group is complete, mix the beans and continue the program.
5. Repeat step 4 until all 10 scans have been completed.
6. Empty the beans out and restart at step 1.

NOTES:

For this particular test, I am replacing the beans with a new set of beans from that same bean type. This ensures that we see a larger number of varieties of sizes of beans and are not just testing off of one small sample group.

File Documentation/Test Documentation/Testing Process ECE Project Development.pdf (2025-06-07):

# Introduction

The purpose of this document is to explain the processes that we went through to test out certain configurations of our prototypes along with some searchable keywords for further explanations. Some of these tests ended early as we found no purpose in continuing them, while others continued for extended amounts of tests. Each section will have an explanation of the process used to test along with any changes that we may have made with the lens or the settings used. It will be sectioned off by the prototype tested with and should be used to search for keywords and file names.

# 3D Printed Prototype

Because of the significant amount of noise created from the 3D printed models, we decided to never actually use this as one of our testing devices since we couldn’t differentiate between noise and actual data.

# Metal Device

## 1- 10 Bean Range tests

This test was the first real test that we ran using our new metal testing device. While we had no luck using the 3D printed material, this was our first attempt at eliminating the outside noise. The tests are broken up into “Lens 1” and “Lens 2” tests. Using the IQ data tool from Acconeer we tested from 1 bean adding an additional bean per test all the way up to 10 (see the README in the lens folder). We also included some examples to show what the signal looked like without any beans in the device. This test was replicated for each of our chosen bean types.

The data for 1-10 Bean range tests can be found in the git in Documentation/Test Documentation/Metal Device Testing/1-10 Bean Range Tests. Additional README files can be found in these describing our testing process.

README - The readme is included in the folder to give an idea of the process that we used for testing the beans.

Used Settings - Each Lens testing folder contains the settings that we used for testing with the Acconeer tool. The “profile” setting changes the transmitted pulse length with profile 1 being the shortest pulse length.

No Beans - Alongside testing of different bean types, we include a test with no beans to show that the signal clearly shows when the device is not filled with any beans even when following the same steps as the actual bean tests.

Weight testing - This test was done after our initial 1 - 10 tests. Using varying bean amounts, we tested to find a good weight that did not fully attenuate our signal or eliminate our clear max amplitude peaks. This test was done using “Profile 2” on our Acconeer tool to find a reasonable weight that we could test at that would clearly define a max amplitude. There are two images in each test, one is the initial picture after adding the beans, while the next is after we shake the beans. This was done using various beans at different moisture levels as labeled.

### Lens 1 - Flat Lens

Beans Tested and their moisture levels

1. Comicovel 7.6%
2. Sweet Marias Guatemala Antigua Hunapu 7.8%
3. Tailored Pulped 8.8%

Unusual Signals - A couple of tests gave us very unusual results compared to similar bean amounts. An overhead picture was taken of these and recorded for reference.

### Lens 2 - Fresnel Lens

Our original metal testing device was not made to fit lens 2, so we did not continue the tests with this lens, but we did want a good idea with how the signals looked using it.

Beans Tested and their moisture levels

1. Comicovel 7.6%

## Large Amount Bean Testing V1

“Settings 1” tests were conducted using profile 1 with approximately 50 beans per test. There is an example of the amount of beans used in the folder along with a readme explaining that we would be turning the device rather than shaking to see if this gave more consistent results.

There is also a screenshot with the settings that we used with the Acconeer tool for this test. Just like the tests before, there is also a no beans test recorded for reference.

The data for this test can be found in the git Documentation/Test Documentation/Metal Device Testing/Large Amount Bean Testing (V1). There is an additional README that can be found in this folder as well explaining the process.

Seeing Reflector - These are the modified settings that we used for this test that showed us a good signal and was drastically affected by the use of our corner reflector.

Beans Tested and their moisture levels

1. Comicovel 7.6%
a. Conducted one test while spinning the device a quarter turn in between screenshots.
2. Sweet Marias Guatemala Antigua Hunapu 7.8%
a. Ran one test with quarter turns in between screenshots (test with spins old), mixed up the beans and tested again with quarter turns in between screenshots (test with spins new).
3. Tailored Pulped 8.8%
a. Ran one test with quarter turns in between screenshots (test with spins old), mixed up the beans and tested again with quarter turns in between screenshots (test with spins new).

## Large Amount Bean Testing V2

By this point, we finally had a good test program that used the IQ data from the Acconeer tool, but put it into a numeric value that we could easily record onto a CSV and compare against other tests. For this test, rather than spinning the device and taking the values at different turns, we would take 4 values at different time intervals without mixing, then mix the beans and repeat this a total of 4 values per test for 4 tests (16 values per bean type). As always, refer to the README in the folder for more information. We ran this test for two different days, retesting some of the beans we had already tested to see if days later in a different test setting we would get similar or different results.

The main value we are testing for in these tests was the peak amplitude from each reading, then after x amount of tests, we would find the average of those peak amplitudes and compare them against different beans to see if we can reliably tell which bean was which from the amplitude average.

Data from these tests can be found in “PeakAmplitudeTestNoSpin.xlsx”

Beans Tested and their moisture levels

1. Comicovel 7.6%
2. Sweet Marias Guatemala Antigua Hunapu 7.8%
3. *Tailored Pulped(OLD) 8.8% Both Tailored Pulped Old and New are the same, just different bags so we tested and found they were slightly different so we relabled them.
4. *Tailored Pulped(NEW) 8.9%
5. Sweet Marias India Monsoon Malabar 12.2%
6. Sweet marias Yemen Mokha sanani 11.4%
7. Sweet Marias Guatemala San Diego Buena 7.9%
8. Sweet Maria's Rwanda Rulindo Tumba 9.7%
9. Sweet Marias Ethiopiques 8.8%
10. Sweet Marias Yemen Mokha Peabery 10.4%

*Both Tailored Pulped Old and New are the same, just different bags so we tested and found they were slightly different so we relabeled them and tested again to see if the small moisture difference would make a noticeable difference in values.

## Large Amount Permittivity Testing

This test was done using a modified program that found the average for us using many scans over a time period and taking the average of those scans. This test was not fully completed because we found a lot of the data to be unreliable since our values could be so drastically different from one test to another. The settings used can also be found in this folder along with the README. For this test we ended up finding that the flat lens was more reliable for this testing prototype since it was specially sized for this lens and focused more on those tests.

Data from these tests can be found in “PermativityTesting.xlsx” and was found using “ConsistentAmplitudeV1.py” which can be found in the git. We continued to modify this program to try and get more reliable results.

Beans Tested and their moisture levels

1. Sweet marias Yemen Mokha sanani 11.4%
2. Sweet marias Guatemala Antigua Hunapu 7.8%
3. Sweet Marias Guatemala San Diego Buena 7.9%
4. Sweet Maria's Rwanda Rulindo Tumba 9.7%
a. We stopped part way through this test because we could see that our average amplitudes were all over the place, so this data was not going to end up being usable.

## Real and Imag Test V1

The real and imaginary Test was our final test using our First Metal testing device. We decided that we just needed more data to be able to tell if we were getting usable data or not. We chose 3 beans of varying moisture content so that if possible, we could clearly see the difference in the signal values that they produced. Because of some of the varying values from the tests before, we modified the program to get both the real and imaginary parts of the IQ data to see if we could use more than one value to differentiate the type of beans easier. The testing plan was as follows.

1. Start with an empty testing device for calibration and start the program.
2. When calibration is complete, fill the testing device with our chosen amount (5 grams).
3. Continue with the program by pressing enter and waiting for the program to get all the required data.
4. Once the first scan is complete, shake up the device and then press enter again.
5. Continue steps 3 and 4 until all 10 scans are completed, then remove the beans and restart from step one with another 5 grams from the same bean type.

Beans Tested and their moisture levels

1. Sweet marias Guatemala Antigua Hunapu 7.8%
2. Sweet Maria's Rulindo Tumba 9.7%
3. Sweet marias Yemen Mokha sanani 11.4%

Data from these tests can be found in the git in “Real_and_Imag_testV1.xlsx” and the program used was “ConsistentAmplitudeV6”.

## Thin Metal Device

This test was completed using profile 1 on the Acconeer tool. We broke it up into 2 main tests using the Fresnel lens, the flat lens, and the parabolic lens. The first test was testing the waves produced by 1-10 beans like the test before, and the second was adding a large amount of beas to our testing device.

The data for these tests can be found in the git in Documentation/Test Documentation/Thin Metal Device Testing. For additional information, see the README file inside this folder.

The coffee that we tested with this device was as follows

1. Sweet Maria's Rwanda Rulindo Tumba 9.7%

2. Sweet Marias Ethiopiques 8.8%
3. Comicovel 7.6%
4. Tailored Pulped 8.8%

## Medium Metal Device

This test was broken into two sections “2 gram testing” and “3 gram testing” which was just the amount of beans that we used for these particular tests along with “Final Testing” which was the final test that we ran with green beans.

These tests were run following the “Proceduere_README” which can be found in the “Medium Metal Device Testing” folder. The complete data for Final Testing can be found in Software/Data Collection/Datasets on the git.

Beans Tested and their moisture levels

1. Sweet marias Guatemala Antigua Hunapu 7.8%
2. Sweet Maria's Rulindo Tumba 9.7%
3. Sweet marias Yemen Mokha sanani 11.4%

## New Testing device

The purpose of this test plan is to evaluate the complete COATL mmWave RADAR
system designed for differentiating between different roasts from the same coffee bean using I/Q data collected via the XM125 radar. This includes verification of both hardware and software functionality, reliability of the data collection pipeline. The testing procedure begins with structured data collection using our new 3D printer inspired testing apparatus. Data is collected using Yemen Mokha Sanani green coffee beans roasted to three different levels: light roast, medium roast and dark roast. A total of 50 series of scans per variety are performed, with 3,300 I/Q measurements per series, producing a dataset of approximately 165,000 data
Points.

Refer to the Developer’s Manual in Section 12 for a complete list of all required hardware, tools, and software packages. Follow the instructions for hardware assembly and software environment setup prior to initiating any data collection or machine learning operations.

1. Read the Developer’s Manual and User’s Manual in Section 12 to understand hardware assembly and software operation.
2. Choose one of the three coffee roast varieties.
3. Fill and level the provided testing container.
4. Run the “FullAverageScan (Coffee Roast).py” script.
5. Follow all printed prompts while turning to the set measured steps on the bottom of the testing container in between each prompt.
- Important: At the start of each test, place the testing container with the star as the start point. This will ensure that you finish the required number of turns for the test with the same positioning each time.
8. Complete all 50 scans, then remove and store the beans in a separate container.
9. Repeat until 5 runs of the program are completed per roast.
10. The I/Q data will be exported to a CSV file within the same directory as the program file. Successive runs will append the I/Q data to the same CSV file Automatically.

### Equipment used

1. 6 x .5 inch A270 Hex bolts
2. 3D printed bean holder stand
3. Copper tape
4. 4 x .25 inch philips screws
5. 4 x 2.25 x .125 inch Plexi-glass
6. 6 x 6 x .125 inches Plexi-glass
7. Acconeer Radar with lens and USB
8. 4x 2.5mm standoff hex screws with standoffs
9. 5x .25 inch width L brackets
10. 43 inches of metal strut (will need to be cut to size)
a. 15 inches x 1
b. 7 inches x 4

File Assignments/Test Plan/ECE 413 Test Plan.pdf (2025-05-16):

# COATL Millimeter wave RADAR

# Test Plan

## Team 4

Portland State University

Maseeh College of Engineering & Computer Science

Department of Electrical & Computer Engineering

Industry Sponsor:
Joshua Mendez, joshmen@pdx.edu

Faculty Advisor:
Mark Martin, marmart2@pdx.edu

Engineering Team:
Wallace McKenzie, mwallace@pdx.edu Chris Kane-Pardy, chrisk@pdx.edu Henry Sanders, hensan@pdx.edu Kamal Smith, kamal@pdx.edu

### May 8, 2025


ECE 412/413

Senior Project Development I/II

COATL - MMwave RADAR | PSU ECE 412/413

## 1 Top Down Test Plan v1.0

Date of Test: 4/25/2025
Testers: Kamal Smith, Henry Sanders, Wallace McKenzie, Chris Kane-Pardy

### 1.1 Purpose

The purpose of this test plan is to test the accuracy of the machine learning model used in the COATL mmWave RADAR project. This model is currently being developed to differentiate between 3 varieties of green coffee beans of various moisture contents based on I/Q data obtained through the XM125 radar. Current testing involves using a sample data set acquired through our data collection program. This test plan involves using that sample data set, but successive testing will involve live prediction of at least 3 green coffee varieties, once our machine learning model is trained. This test plan will include suggestions for optimizing the machine learning model as well as a description of how to make additional datasets for it.

Note: Typical machine learning models are considered good if they are above 70% accurate. Machine learning models that are within the range of 80-90% are considered ideal. This test plan is designed to achieve accuracy within the range of 80-95%.

### 1.2 Equipment Needed

- System Equipment

– A computer with Python (version 3.8, 3.9, 3.10, 3.11, or 3.12)

– The Acconeer Exploration Tool

∗ Installation: Within your terminal, type

python -m pip install --upgrade acconeer-exptool[app]

– PyTorch

∗ Installation: Within your terminal, type

Engineering Building, 1930 SW 4th Ave, Portland, OR 97201 1 pip3 install torch torchvision torchaudio --index-url \ https://download.pytorch.org/whl/cu118/

– Scikit-learn

∗ Installation: Within your terminal, type

python -m venv sklearn-env sklearn-env\Scripts\activate # activate

pip install -U scikit-learn

– Download ”Full Array Average Scan Fixed.py” from GitHub repo:

https://github.com/chriskp-pdx/COATL-RADAR/blob/main/pyFiles/Beanis%20Scan%20Data%20Collection/Consistent%20Amplitude/Full_

Array_Average_Scan_Fixed.py (https://github.com/chriskp-pdx/COATL-RADAR/blob/main/pyFiles/Beanis%20Scan%20Data%20Collection/Consistent%20Amplitude/Full_Array_Average_Scan_Fixed.py)

– Download ”Chris MLTests.py” from Github repo: https://github.com/chriskp-pdx/COATL-RADAR/blob/main/pyFiles/Machine%20Learning/Chris_MLTests.py (https://github.com/chriskp-pdx/COATL-RADAR/blob/main/pyFiles/Machine%20Learning/Chris_MLTests.py)

– Download ”MedBeanis Testing v2 - BEANSV.csv” from
GitHub repo:
https://github.com/chriskp-pdx/COATL-RADAR/blob/main/pyFiles/Datasets/MedBeanis_Testing%20V2%20-%20BEANSV.csv (https://github.com/chriskp-pdx/COATL-RADAR/blob/main/pyFiles/Datasets/MedBeanis_Testing%20V2%20-%20BEANSV.csv)
- Test Equipment

– EVK125 Module Evaluation Kit with XM125 board and A121 Radar Sensor

– LH112 Lens Kit and Holder

– Aluminum tube

– 3 varieties of unroasted coffee beans

– 3-d printed Christmas tree stand

– 8 M2.5 x 10mm screws

– Corner reflector

– Copper tape

Engineering Building, 1930 SW 4th Ave, Portland, OR 97201 2

– USB to USB-C cable

– Metric scale

### 1.3 Pre-Test Setup

### 1.3.1 Hardware Setup

1. Insert the Hyperbolic lens into the holder.
2. Insert the aluminum tube into the 3D-printed Christmas tree stand and tighten the 8 screws on the sides such that the aluminum tube is level and positioned centered over the center of the Hyperbolic lens.
3. Plug the USB cable into a USB port on your computer and the USB-c end into the connector on the XM125.

### 1.3.2 Software Setup

1. Open Device Manager on your computer and make sure the COM port is being recognized (it should be the ”enhanced” COM port).
2. Open ”Full Array Average Scan Fixed.py” in your IDE or terminal of choice. You may have to ensure you have both the acconeer and PyTorch packages installed within the same environment as your IDE.
Running Full Array Average Scan Fixed.py will not work otherwise.
3. Change line 27 (the line with the variable definition ”client”) to reflect the correct COM port that matches your local ”enhanced” port determined in step 1 above.
4. Open ”Chris MLTests.py” in your IDE or terminal of choice.
5. Change line 13 (the line with the variable definition ”TrainingData”) to reflect the correct data path where you have ”MedBeanis Testing v2 - BEANSV.csv” downloaded.

Engineering Building, 1930 SW 4th Ave, Portland, OR 97201 3

### 1.4 Top-down Test Steps for Training the Machine Learning

### Model with a Sample Dataset

1. Run ”Chris MLTests.py”. It will take roughly 2 minutes to finish training the model. Take note of the printed accuracy. If the accuracy is below 80%, proceed with the following steps. If the accuracy is above 80%, proceed to subsection 1.5.
2. Experiment with modifying the number of epochs. The epochs variable is on line 67 and is currently set at 25000. Increasing or decreasing this value will have mixed results and may or may not yield improved accuracy.

Note: This value is considered high for typical machine learning models; however, the dataset for this experiment is large, requiring a large number of epochs to yield a higher accuracy.

3. Experiment with modifying the learning rate. The learning rate is on line 64 within the parameter ”lr” within the ”optimizer” variable. Increasing or decreasing this value will have mixed results and may or may not yield improved accuracy.

### 1.5 Top-down Test Steps for Data Collection

1. Choose a bean variety. Using the scale, measure out 3g of beans.
2. Carefully insert the beans into the aluminum tube.
3. Using an IDE of your choice, open and run ”Full Array Average Scan Fixed.py”. It will export the amplitude values to a CSV file within the same directory as ”Full Array Average Scan Fixed.py”.
4. For testing this new data set, open ”Chris MLTests.py” and change line 13 (the line with the variable definition ”TrainingData”) to reflect the correct data path where you have your new CSV dataset downloaded.
5. Return to subsection 1.4.

Engineering Building, 1930 SW 4th Ave, Portland, OR 97201 4

### 1.6 Top-down Test Plan Conclusions / Discussion

The goal of these tests is to create datasets for the machine learning model that yield accuracy results within the range of 80-95%. Currently, we are working on a program that allows for live input data to be compared against our sample dataset. Achieving consistent accuracy of prediction of 3 varieties of green coffee beans is the requirement we are ultimately striving to meet. Meeting this goal will require a combination of modifying the machine learning model and the data collection program, as well as much, much more testing.

The current model accuracy heavily depends on the amount and diversity of data available. Collecting additional datasets under slightly varied environmental conditions (e.g. slight variations in bean orientation within the tube) can help improve model generalization and reduce overfitting.

Moving forward, we are prioritizing increasing the amount and diversity of collected training data and continuing to refine the machine learning model. Implementing live prediction capabilities, along with broader validation strategies, will be critical steps toward achieving the ultimate requirement: reliable differentiation between three varieties of green coffee beans based on moisture content.

Engineering Building, 1930 SW 4th Ave, Portland, OR 97201 5

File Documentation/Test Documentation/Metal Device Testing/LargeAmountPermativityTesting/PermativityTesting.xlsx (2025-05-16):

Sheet: Sheet1
 | Permativity testing using the program ConsistentAmplitudeV1.py
LENS 1 TESTING (FLAT LENS)
Test # | Sweet Marias (India Monsoon Malabar) 12.2% | Sweet marias (Yemen Mokha sanani) 11.4% | Sweet marias (Guatemala Antigua Hunapu) 7.8% | Sweet Marias (Guatamala San Diego Buena) 7.9% | Sweet Maria's (Rulindo Tumba) 9.7% | SweetM(Ethiopiques) 8.8%
1 |  | Average Maximum Calibration Amplitude: 46329.636303342595 Average Maximum Bean Amplitude: 4945.130171896478 | Average Maximum Calibration Amplitude: 46329.636303342595 Average Maximum Bean Amplitude: 4621.629230098876 | Average Maximum Calibration Amplitude: 46329.636303342595 Average Maximum Bean Amplitude: 2949.6481040863073 | Average Maximum Calibration Amplitude: 46329.636303342595 Average Maximum Bean Amplitude: 2119.2776505620386
2 |  | Average Maximum Calibration Amplitude: 46329.636303342595 Average Maximum Bean Amplitude: 2422.630507090865 | Average Maximum Calibration Amplitude: 46329.636303342595 Average Maximum Bean Amplitude: 4157.816764215042 | Average Maximum Calibration Amplitude: 46329.636303342595 Average Maximum Bean Amplitude: 3063.175604189534 | Average Maximum Calibration Amplitude: 46329.636303342595 Average Maximum Bean Amplitude: 1907.0267789149323
3 |  | Average Maximum Calibration Amplitude: 46329.636303342595 Average Maximum Bean Amplitude: 4730.50385689538 | Average Maximum Calibration Amplitude: 46329.636303342595 Average Maximum Bean Amplitude: 2721.634141949423 | Average Maximum Calibration Amplitude: 46329.636303342595 Average Maximum Bean Amplitude: 3088.1875003705013 | Average Maximum Calibration Amplitude: 46329.636303342595 Average Maximum Bean Amplitude: 2730.677899946815
4 |  | Average Maximum Calibration Amplitude: 46329.636303342595 Average Maximum Bean Amplitude: 5814.166477788912 | Average Maximum Calibration Amplitude: 46329.636303342595 Average Maximum Bean Amplitude: 4523.375525761064 | Average Maximum Calibration Amplitude: 46329.636303342595 Average Maximum Bean Amplitude: 2283.5763631427244
LENS 2 TESTING (FRESNEL)
Test #
1 |  | Average Maximum Calibration Amplitude: 46329.636303342595 Average Maximum Bean Amplitude: 7701.888234916853 | Average Maximum Calibration Amplitude: 46329.636303342595 Average Maximum Bean Amplitude: 7001.347630121435 | Average Maximum Calibration Amplitude: 46329.636303342595 Average Maximum Bean Amplitude: 3597.8751859393146
2 |  | Average Maximum Calibration Amplitude: 46329.636303342595 Average Maximum Bean Amplitude: 6389.383132607707 | Average Maximum Calibration Amplitude: 46329.636303342595 Average Maximum Bean Amplitude: 4664.724805193101 | Average Maximum Calibration Amplitude: 46329.636303342595 Average Maximum Bean Amplitude: 4697.396566410864
3
4
LENS 3 TESTING (DOME)
Test #
1 |  | Average Maximum Calibration Amplitude: 46329.636303342595 Average Maximum Bean Amplitude: 10061.246557163879 | Average Maximum Calibration Amplitude: 46329.636303342595 Average Maximum Bean Amplitude: 14074.405214514229 | Average Maximum Calibration Amplitude: 46329.636303342595 Average Maximum Bean Amplitude: 7435.423197987804
2 |  | Average Maximum Calibration Amplitude: 46329.636303342595 Average Maximum Bean Amplitude: 18503.86604308729 | Average Maximum Calibration Amplitude: 46329.636303342595 Average Maximum Bean Amplitude: 14968.746102549903 | Average Maximum Calibration Amplitude: 46329.636303342595 Average Maximum Bean Amplitude: 7065.052332676302
3 |  | Average Maximum Calibration Amplitude: 46329.636303342595 Average Maximum Bean Amplitude: 7018.956867110869 | Average Maximum Calibration Amplitude: 46329.636303342595 Average Maximum Bean Amplitude: 10727.867179972538 | Average Maximum Calibration Amplitude: 46329.636303342595 Average Maximum Bean Amplitude: 9293.601632151604
4 |  | Average Maximum Calibration Amplitude: 46329.636303342595 Average Maximum Bean Amplitude: 11377.83327591509 | Average Maximum Calibration Amplitude: 46329.636303342595 Average Maximum Bean Amplitude: 10297.87830989156 | Average Maximum Calibration Amplitude: 46329.636303342595 Average Maximum Bean Amplitude: 7077.4425129217825

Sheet: Sheet2
 | Permativity testing using the program ConsistentAmplitudeV1.py (Revised Version with more scans) turned down gain to 19 and using approx 6g of beans
LENS 1 TESTING (FLAT LENS)
Test # | Sweet Marias (India Monsoon Malabar) 12.2% | Sweet marias (Yemen Mokha sanani) 11.4% | Sweet marias (Guatemala Antigua Hunapu Vieja) 7.8% | Sweet Marias (Guatamala San Diego Buena) 7.9% | Sweet Maria's (Rulindo Tumba) 9.7% | SweetM(Ethiopiques) 8.8% | Sweet Marias (Yemen Mokha Peabery) 10.4% (Flat)
1 | Average Maximum Calibration Amplitude: 46329.636303342595 Average Maximum Bean Amplitude: 3716.751414916746 | Average Maximum Calibration Amplitude: 46329.636303342595 Average Maximum Bean Amplitude: 2020.8519152346362 | Average Maximum Calibration Amplitude: 46329.636303342595 Average Maximum Bean Amplitude: 3364.3685799589766 |  | Average Maximum Calibration Amplitude: 46329.636303342595 Average Maximum Bean Amplitude: 2626.094348077821 |  | Average Maximum Calibration Amplitude: 46328.222089780225 Average Maximum Bean Amplitude: 1828.7114819155806
2 | Average Maximum Calibration Amplitude: 46329.636303342595 Average Maximum Bean Amplitude: 3650.4907109935716 |  |  |  |  |  | Average Maximum Calibration Amplitude: 46328.92920195761 Average Maximum Bean Amplitude: 2642.3941839319423
3
4

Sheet: Sheet4
 | Permativity testing using the program ConsistentAmplitudeV2.py (Revised Version with more scans) turned down gain to 19 and using approx 6g of beans added imaginary part back into program
LENS 1 TESTING (FLAT LENS)
Test # | Sweet Marias (India Monsoon Malabar) 12.2% | Sweet marias (Yemen Mokha sanani) 11.4% | Sweet marias (Guatemala Antigua Hunapu Vieja) 7.8% | Sweet Marias (Guatamala San Diego Buena) 7.9% | Sweet Maria's (Rulindo Tumba) 9.7% | SweetM(Ethiopiques) 8.8% | Sweet Marias (Yemen Mokha Peabery) 10.4% (Flat)
 |  | Normalized Calibration Max: 32760.000000000004 Normalized Bean Max: 778.8400000000001
 |  | Normalized Calibration Max: 32760.000000000004 Normalized Bean Max: 1081.7200000000003
Changed the program a little bit here, added more
 |  | Normalized Calibration Max: 32759.999999999993 Normalized Bean Max: 203.7160000000001

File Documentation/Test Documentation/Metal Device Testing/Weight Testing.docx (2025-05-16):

Weight Testing

Phase enhancement definition (may need this)

https://docs.acconeer.com/en/latest/radar_data_and_control/a121/in_depth_topics/loopback.html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

I will be testing different weights looking for noticeable differences trying to settle on a good weight. We will be starting at 6 grams since this is around where we have been testing before.

NOTE: I am adding a .2 tolerance to the weight meaning the weight can be between 5.8 - 6.2 grams and so on with testing. Also, for this testing, I have turned down the gain to 17 because this is the point at which the sensor is not fully saturated with our settings.

I am using the same method I did before with the following steps

1. Add Desired amount to tube
2. Screenshot the signal, this is the before image
3. Shake the beans up
4. Screenshot the new image
5. Remove the beans and add 1g to the amount then replace, all the way up to 7 repeating steps 1 - 4 each time.

India Monsoon Malabar 12.2%

8 grams (This is where we no longer have a defined peak. This means 7 should be the max to test at)


7 grams


6 grams


5 grams


4 grams


Yemen Mokha Peaberry 10.4%

7 grams


6 grams


5 grams


4 grams


Guatemala Antigua Hunapu Ciudad Vieja 7.8%

7 grams


6 grams


5 grams


4 grams


Yemen Mokha Sanani 11.4%

7 grams


6 grams


5 grams


4 grams


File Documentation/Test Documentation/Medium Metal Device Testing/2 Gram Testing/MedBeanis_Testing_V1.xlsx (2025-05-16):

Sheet: Yemen Mokha Sanani 11.4%
Scan_Group | Point_0 | Point_1 | Point_2 | Point_3 | Point_4 | Point_5 | Point_6 | Point_7 | Point_8 | Point_9 | Point_10 | Point_11 | Point_12 | Point_13 | Point_14 | Point_15 | Point_16 | Point_17 | Point_18 | Point_19 | Point_20 | Point_21 | Point_22 | Point_23 | Point_24 | Point_25 | Point_26 | Point_27 | Point_28 | Point_29 | Point_30 | Point_31 | Point_32 | Point_33 | Point_34 | Point_35 | Point_36 | Point_37 | Point_38 | Point_39 | Point_40 | Point_41 | Point_42 | Point_43 | Point_44 | Point_45 | Point_46 | Point_47 | Point_48 | Point_49
Real_1 | -5744.92 | 14616.78 | 25603.72 | 30693.56 | 31297.64 | 31788.24 | 32105.08 | 32545.66 | 32710.52 | 32820.18 | 32998.42 | 32706.88 | 32659.16 | 32898.18 | 32883.2 | 33000.24 | 33433.8 | 33481.22 | 33682.34 | 33751.52 | 34092.22 | 34572.4 | 34595.58 | 34402.06 | 34915.66 | 34779.2 | 34508.94 | 32123.54 | 14332.08 | 14923.86 | -4574.46 | 1851.18 | -2075.1 | 515.16 | 4796.88 | 6394.56 | 8417.12 | 11567.58 | 11021.58 | 11092.18 | 15031.38 | 10647.94 | 8782.16 | 2956.52 | 3261.76 | 5784.92 | 887.5 | -5248.04 | 892.06 | -2628.12
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

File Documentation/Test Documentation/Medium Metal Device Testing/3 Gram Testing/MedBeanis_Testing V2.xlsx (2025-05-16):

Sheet: Yemen Mokha Sanani 11.4%
Scan_Group | Point_0 | Point_1 | Point_2 | Point_3 | Point_4 | Point_5 | Point_6 | Point_7 | Point_8 | Point_9 | Point_10 | Point_11 | Point_12 | Point_13 | Point_14 | Point_15 | Point_16 | Point_17 | Point_18 | Point_19 | Point_20 | Point_21 | Point_22 | Point_23 | Point_24 | Point_25 | Point_26 | Point_27 | Point_28 | Point_29 | Point_30 | Point_31 | Point_32 | Point_33 | Point_34 | Point_35 | Point_36 | Point_37 | Point_38 | Point_39 | Point_40 | Point_41 | Point_42 | Point_43 | Point_44 | Point_45 | Point_46 | Point_47 | Point_48 | Point_49
Real_1 | 38957.08 | 38854.5 | 35930.6 | 35192.92 | 34564.14 | 33838.92 | 35049.92 | 35589.66 | 35177.56 | 35785.5 | 35937.04 | 35041.92 | 35660.84 | 35705.18 | 36017.28 | 35647.64 | 35413.64 | 35677.92 | 36127.5 | 35713.3 | 35981.68 | 36111.62 | 36454.88 | 36817.46 | 36731.72 | 36681.26 | 36697.84 | 35807.66 | 27472.66 | 28239.62 | -25133.34 | -30407.28 | -22008.76 | -28587.06 | -28417.6 | 13209.72 | -10901.52 | -12478.48 | -24747.24 | -8181.1 | 15748.34 | 8849.36 | -6789.58 | 27314.84 | 25020.32 | 25004.08 | 18449.26 | -9355.12 | 7712.3 | -32323.92
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

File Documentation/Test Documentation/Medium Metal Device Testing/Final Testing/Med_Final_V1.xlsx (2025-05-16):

Scan_Group | Point_0_Real | Point_1_Real | Point_2_Real | Point_3_Real | Point_4_Real | Point_5_Real | Point_6_Real | Point_7_Real | Point_8_Real | Point_9_Real | Point_10_Real | Point_11_Real | Point_12_Real | Point_13_Real | Point_14_Real | Point_15_Real | Point_16_Real | Point_17_Real | Point_18_Real | Point_19_Real | Point_20_Real | Point_21_Real | Point_22_Real | Point_23_Real | Point_24_Real | Point_25_Real | Point_26_Real | Point_27_Real | Point_28_Real | Point_29_Real | Point_30_Real | Point_31_Real | Point_32_Real | Point_33_Real | Point_34_Real | Point_35_Real | Point_36_Real | Point_37_Real | Point_38_Real | Point_39_Real | Point_40_Real | Point_41_Real | Point_42_Real | Point_43_Real | Point_44_Real | Point_45_Real | Point_46_Real | Point_47_Real | Point_48_Real | Point_49_Real | Point_0_Imag | Point_1_Imag | Point_2_Imag | Point_3_Imag | Point_4_Imag | Point_5_Imag | Point_6_Imag | Point_7_Imag | Point_8_Imag
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

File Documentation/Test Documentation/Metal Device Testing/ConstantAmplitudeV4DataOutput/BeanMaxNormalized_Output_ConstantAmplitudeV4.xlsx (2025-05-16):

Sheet: BeanMaxNormalized_Output.csv
Yemen Mokha Sanani 11.4% |  | Guatemala Antigua Hunapu Ciudad Vieja 7.8% |  | Rwanda Rulindo Tumba 9.7%
Test 1
Iteration | BeanMaxNormalized | Iteration | BeanMaxNormalized | Iteration | BeanMaxNormalized
1 | 1959.704 | 1 | 3878.912 | 1 | 1626.526
2 | 1963.29 | 2 | 3825.612 | 2 | 1546.614
3 | 1951.222 | 3 | 3884.636 | 3 | 1544.508
4 | 1956.824 | 4 | 3916.352 | 4 | 1529.842
5 | 1929.432 | 5 | 3986.956 | 5 | 1567.092
6 | 1956.194 | 6 | 3685.848 | 6 | 1506.588
7 | 1924.31 | 7 | 3875.344 | 7 | 1534.282
8 | 1988.722 | 8 | 3823.356 | 8 | 1538.474
9 | 1977.402 | 9 | 3734.18 | 9 | 1501.66
10 | 1986.712 | 10 | 3820.8 | 10 | 1533.412
Test 2
Iteration | BeanMaxNormalized | Iteration | BeanMaxNormalized
1 | 1651.716 | 1 | 2199.142 | 1 | 1447.4
2 | 2087.94 | 2 | 2000.598 | 2 | 1417.814
3 | 2213.566 | 3 | 2113.76 | 3 | 1161.76
4 | 2391.906 | 4 | 2096.584 | 4 | 1441.36
5 | 2230.348 | 5 | 2112.534 | 5 | 1378.396
6 | 2252.298 | 6 | 2082.096 | 6 | 1391.48
7 | 2277.622 | 7 | 2023.952 | 7 | 1393.926
8 | 2325.614 | 8 | 2054.91 | 8 | 1323.032
9 | 2394.546 | 9 | 2114.806 | 9 | 1396.08
10 | 2320.466 | 10 | 2081.026 | 10 | 1390.602
Test 3
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

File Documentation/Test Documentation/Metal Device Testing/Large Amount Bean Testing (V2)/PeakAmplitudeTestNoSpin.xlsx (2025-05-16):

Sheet: Beanis
2025-03-24
LENS 1 TESTING (FLAT LENS)
Test # | SweetM (Rulindo Tumba) 9.7% | SweetM(Ethiopiques) 8.8% | TailoredPulped(OLD) 8.8% | TailoredPulped(NEW) 8.9% | Comicovel 7.6%
1 | 3522.81, 3638.47, 3368.72, 3329.24 | 11686.28,12507.56, 11517.31, 11611.02 | 5246.83, 5397.91, 5408.13, 5699.90 | 6189.58, 6028.91, 6555.78, 6248 | 2851.60, 2961.17, 3079.43, 2885.83
2 | 5076.41, 5112.41, 5328.81, 5327.86 | 9998.27, 9540.32,9614.67, 9075.86 | 6737.49, 6876.41, 6470.46, 6796.81 | 7097.33, 6685.41, 6978.36, 7252.68 | 2561.82, 2409.90, 2375.35, 2696.01
3 | 10955.94, 10769.35, 11157.17,10889.25 | 7175.81, 7657.16, 7611.11, 7426.82 | 8125.89, 7948.36, 8044.29, 8063.17 | 10236.85,10858.84, 10987.82,10305.97 | 2905.32, 2662.63, 2785.46, 2783.03
4 | 4103.04, 4153.22, 4214.86, 4300.71 | 3973.38, 3964.63, 4002.71, 4000.35 | 5581.23, 5383.53, 5587.74, 5371.84 | 4293.84, 4351.1, 4413.72, 4334.16 | 2830.54, 2772.49, 2792.01, 2790.45
Average | 5953.55875 | 8209.75625 | 6426.9075 | 7033.521875 | 2758.94
LENS 2 TESTING (FRESNEL)
Test # | SweetM (Rulindo Tumba) 9.7% | SweetM(Ethiopiques) 8.8% | TailoredPulped(OLD) 8.8% | TailoredPulped(NEW) 8.9% | Comicovel 7.6%
1 | 4760.57, 4708.06, 4915.82, 4744.17 | 6478.40, 6634.32, 6495.95, 6495.68 | 4545.13, 4562.91, 4267.01, 4524.96 | 9515.29, 9554.35, 8849.91, 9536.77 | 4060.57, 4353.52, 4011.58, 4052.36
2 | 4225.95, 4000.62, 3850.95, 4226.89 | 6549.25, 6115.28, 6487.32, 6162.5 | 3545.93, 3762.69, 3725.68, 3677.39 | 12657.16, 13217.12, 12688.77, 12941.36 | 5521.01, 5382.64, 5120.43, 5514.78
3 | 3540.41, 4847.53, 3644.88, 3954.70 | 12359.22, 11870.01, 12379, 12153.81 | 6247.77, 6430.10, 6299.87, 6114.61 | 6695.37, 7304.54, 7192.59, 7357.49 | 5963.03, 5879.57, 6674.69, 5840.84
4 | 1403.80, 1428.23, 1193.24, 1484.42 | 11593.06, 11766.06, 12231.81, 12026.9 | 7715.46, 7746.55, 7895.03, 7606.87 | 8105.29, 7744.27, 7827.78, 7771.22 | 6816.43, 7243.42, 6737.09, 6986.55
Average | 3578.136875 | 9237.47625 | 5541.675 | 9309.955 | 6135.905
LENS 3 TESTING (DOME)
Test # | SweetM (Rulindo Tumba) 9.7% | SweetM(Ethiopiques) 8.8% | TailoredPulped(OLD) 8.8% | TailoredPulped(NEW) 8.9% | Comicovel 7.6%
1 | 1957.55, 2019.20, 1910.95, 1923.13 | 38131.11, 35523.79, 33824.28, 34102.77 | 30751.04, 30617.22, 30259.45, 30407.99 | 13897.24, 13632, 13668.85, 14142.71 | 4675.62, 4998.08, 4863.61, 4941.45
2 | 2583.47, 2709.75, 2462.40, 3160.43 | 31593.06, 31459.7, 31483.24, 31310.06 | 10785.26, 10539.04, 10819.71, 10853.64 | 15085.63, 14837.48, 15130.5, 15273.69 | 6178.94, 5828.27, 6259.14, 6289.73
3 | 2880.77, 3281.81, 2777, 3021.59 | 33430.53, 37604.36, 35929.87, 34862.5 | 24723.78, 24121.22, 24356.46, 23893.14 | 11138.45, 10906.09, 10832.12, 11227.62 | 5195.33, 5148.28,5270.07, 5171.01
4 | 1462.99, 1421.03, 1341.34, 1451.42 | 38508.72, 39292.38, 38844.55, 38072.29 | 10420.22, 10355.86, 10216.49, 10161.28 | 8407.84, 8626.82, 8657.41, 8605.48 | 4407.13, 4289.30, 4088.15, 4101.21
Average | 2247.776875 | 35498.3275 | 18980.0125 | 12129.34188 | 5106.5575
2025-03-28
LENS 1 TESTING (FLAT LENS)
Test # | Sweet Marias (India Monsoon Malabar) 12.2% | Sweet marias (Yemen Mokha sanani) 11.4% | Sweet marias (Guatemala Antigua Hunapu) 7.8% | Sweet Marias (Guatamala San Diego Buena) 7.9% | Sweet Maria's (Rulindo Tumba) 9.7% | SweetM(Ethiopiques) 8.8% | Sweet Marias (Yemen Mokha Peabery) 10.4% (Flat)
1 | 2314.43,2282.84,2009.42,2300.43 | 4808.83,5388.35,4967.54,4992.10 | 7035.24,7460.67,6974.10,7014.48, | 7352.88,7693.65,7295.90,7733.87, | 2668.088454, 2556.9122, 2557.79534, 2475.253522, | 9853.040546, 9713.025996, 9981.568464, 9841.691979, | 4257.972522,4169.299821,4467.502658,4104.546869,
2 | 1936.31,1833.42,1941.92,1643.69 | 5516.10,5240.64,5420.91,5507.11 | 3941.23,3914.72,3883.23,3856.02, | 2903.87,3028.31,2888.51,2761.99, | 4090.773154, 4093.077693, 3923.885829, 3997.942596, | 3598.535397, 3668.128951, 3650.110135, 3700.597249, | 8459.414932,8133.532812,8772.802802,8327.706287,
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

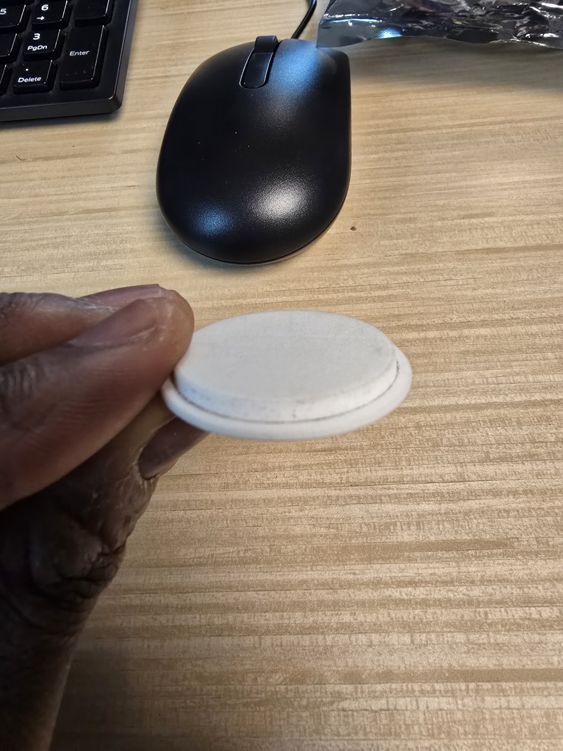
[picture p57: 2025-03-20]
Documentation/Test Documentation/3D Printed Prototype Testing/1-10 Bean Range Tests/Lens 1 Testing/Images/Lens1.jpg

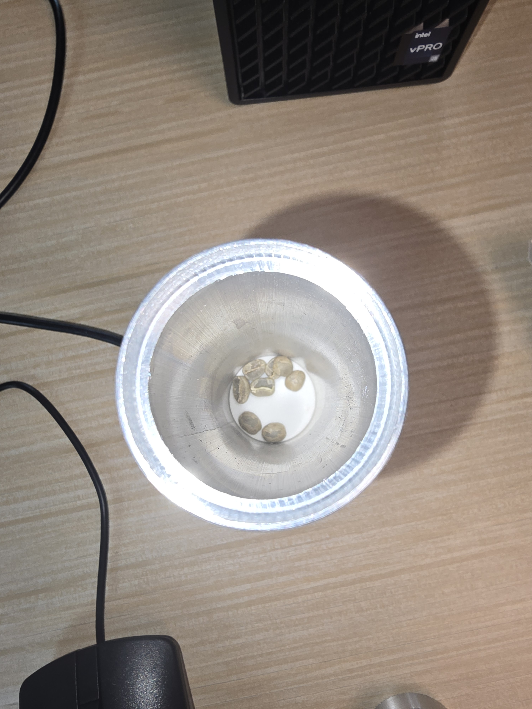
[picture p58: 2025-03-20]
Documentation/Test Documentation/3D Printed Prototype Testing/1-10 Bean Range Tests/Lens 1 Testing/Images/SweetMariaProfile2_Eight_After_BeanOrientation.jpg

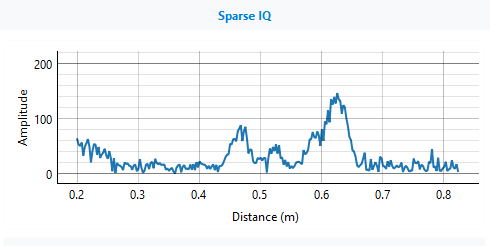
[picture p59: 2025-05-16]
Documentation/Test Documentation/Thin Metal Device Testing/1-10 Bean Range Tests/Profile 1/Hyperbolic Lens Testing/Comicovel/Comicovel_Three_After.png

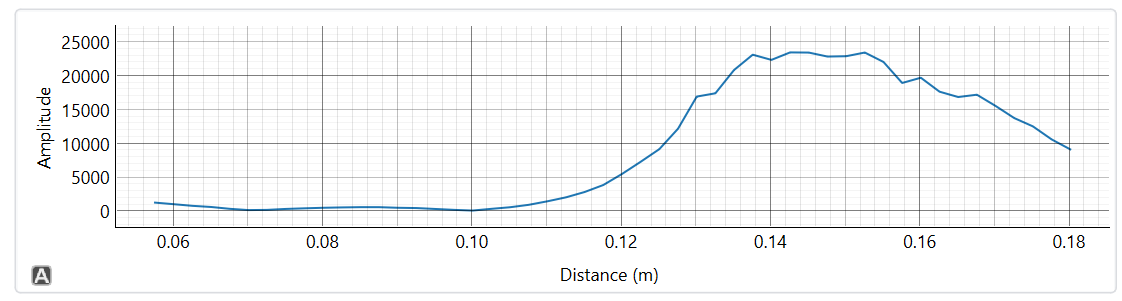
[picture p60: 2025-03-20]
Documentation/Test Documentation/3D Printed Prototype Testing/1-10 Bean Range Tests/Lens 2 Testing/No Beans/Profile 1/Comicovel_NoBeans_Before.png

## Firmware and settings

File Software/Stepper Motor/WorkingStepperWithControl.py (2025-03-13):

# Kamal Smith COATL Project 2/26/25 (Modified to run infinitely until we get a connection or turn off)

# This is the basic code to connect the I2C and began turning the motor.
# I am adding code so that the motor will began turning at the click of a button and can
# be stopped and started at will. I will mark the sections that we need to change if we 
# would like the speed of the motor to be faster or slower. 

import digitalio
import time
import board
from adafruit_motorkit import MotorKit
from adafruit_motor import stepper

# setting up the Outputs on the board using CircuitPython naming
StartAndStop = board.A2 # for starting and stopping the motor
SpeedUp = board.A1 # to increase the speed of the motor
SpeedDown = board.A0 # to decrease the speed of the motor

# Setting up the digital IO
button = digitalio.DigitalInOut(StartAndStop)
button2 = digitalio.DigitalInOut(SpeedUp)
button3 = digitalio.DigitalInOut(SpeedDown)

# Setting Buttons as input with pull up resistors
button.direction = digitalio.Direction.INPUT
button.pull = digitalio.Pull.UP
button2.direction = digitalio.Direction.INPUT
button2.pull = digitalio.Pull.UP
button3.direction = digitalio.Direction.INPUT
button3.pull = digitalio.Pull.UP

# Create the I2C object using the STEMMA QT connector
i2c = board.STEMMA_I2C()

# Initialize the MotorKit at the default I2C address (0x60)
kit = MotorKit(i2c=i2c)

while True:
# This section is in progress
    if not button:

        print("Entered button section")


    elif not button2:

        print("Entered button2 section")
# Section in progress
    else:

        print("No button pressed, will continue on")

    print("Stepping forward a bit...")
    for _ in range(20):  # Step 20 times forward
        kit.stepper1.onestep(direction=stepper.FORWARD, style=stepper.SINGLE)
        # The stepper.DOUBLE is for utilizing both coils for more torque
        # Still figuring out the motor for this feature
        #kit.stepper1.onestep(direction=stepper.FORWARD, style=stepper.DOUBLE)
        time.sleep(0.01)  # Adjust to change speed

#    time.sleep(1)  # Pause so you can observe the move

#    print("Stepping backward a bit...")
#    for _ in range(20):  # Step 20 times backward
#        kit.stepper1.onestep(direction=stepper.BACKWARD, style=stepper.SINGLE)
#        time.sleep(0.01)

#    time.sleep(1)  # Pause before the next cycle

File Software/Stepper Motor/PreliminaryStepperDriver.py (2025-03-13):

import time
import board
from adafruit_motorkit import MotorKit
from adafruit_motor import stepper

# Initialize the MotorKit instance for the default I2C bus
kit = MotorKit(i2c=board.I2C())

# Define stepper motor speed (in seconds between steps)
step_delay = 0.01  # Adjust this value to set the speed

# Function to drive stepper motor continuously
def drive_stepper_motor(steps, direction, style):
    for _ in range(steps):
        if direction == 'forward':
            kit.stepper1.onestep(direction=stepper.FORWARD, style=style)
        elif direction == 'backward':
            kit.stepper1.onestep(direction=stepper.BACKWARD, style=style)
        time.sleep(step_delay)

# Main loop to run the stepper motor continuously
try:
    while True:
        drive_stepper_motor(200, 'forward', stepper.SINGLE)  # Adjust steps as needed
        drive_stepper_motor(200, 'backward', stepper.SINGLE)  # Adjust steps as needed
except KeyboardInterrupt:
    print("Motor stopped by user")

# Release the stepper motor
kit.stepper1.release()

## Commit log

2025-01-15 first git ignore & Ishaans Motor Driver
2025-02-06 Preliminary Base design - No Lid
    This is just the basic design for the main container, without the lid. Will add a lid once the main design is voted on.
    [Container Beans - Shell - No Bottom v1.0 v1.f3d]
2025-02-06 organized folders & added ML documentation
    [Container Beans - Shell - No Bottom v1.0 v1.f3d]
2025-02-07 Create permittivity_calcs.py
    Example program to calculate permittivity of green coffee beans based on reference amplitude/phase and amplitude/phase of sample data
2025-02-12 Final Config Parameters for Integration/Prototype 1
2025-02-15 Create XE125I2C_to_ESP32_S3_GPTSlop.py
    GPT slop code for testing the I2C, for some reason, it's constantly saying connected even with nothing plugged in
2025-02-18 I2C Testing code
    This code is for testing purposes using I2C and the onboard LED
2025-02-18 Infinite I2C Test
    This is to make it easier when testing the I2C, so you can in real time see that the check is still happening
2025-02-18 Update INFINITE_TestI2CWithLED.py
    Added comments and added new import. This is for directly testing if it finds a I2C Connection
2025-02-20 Create TEST.py
    Testing I2C code
2025-02-20 20 Small Balls
    [Container Beans - Shell - No Bottom v1.0 v1.f3d, Prototype 1 (20 Small Balls).3mf]
2025-02-21 comment + components
    [Ball x 20 (SLA Resin) v1.stl, Base x 1 (PLA) v1.stl, Bean Container x 1 (PETG) v1.stl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]
2025-02-27 Create WorkingStepperWithControl.py
    This is the current code I will be editing for the stepper control
2025-03-13 3D Modeling Additions
    [Ball x 20 (SLA Resin) v1.stl, Base x 1 (PLA) v1.stl, Base x 1 (PLA) v2.f3d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]
2025-03-13 3d model rearrangement
    [Ball x 20 (SLA Resin) v1.stl, Base x 1 (PLA) v1.stl, Base x 1 (PLA) v2.f3d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]
2025-03-13 Done for Today, More to Come Soon
    [Gantt Chart Template.xlsx]
2025-03-13 no more fires
    [Ball x 20 (SLA Resin) v1.stl, Base x 1 (PLA) v1.stl, Base x 1 (PLA) v2.f3d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]
2025-03-20 3d printed frame
    [Skinny Beanis Frame v5.3mf, Skinny Beanis Frame v5.f3d, Skinny Beanis Frame v5.stl]
2025-04-08 Fixed a couple things in V4
2025-04-11 Create BeanMaxNormalized_Output_ConstantAmplitudeV4 - ToExport.csv
    [BeanMaxNormalized_Output_ConstantAmplitudeV4 - ToExport.csv]
2025-04-11 Update BeanMaxNormalized_Output_ConstantAmplitudeV4 - ToExport.csv
    [BeanMaxNormalized_Output_ConstantAmplitudeV4 - ToExport.csv]
2025-04-16 Create BeanMaxNormalized_Output_ConstantAmplitudeV4 - ToExport4.csv
    Adding this for testing. No bean number will add that from the program
    [BeanMaxNormalized_Output_ConstantAmplitudeV4 - ToExport4.csv]
2025-04-17 added some testing things
    [BS Sheet - ToExport4.csv]
2025-04-24 Create MedBeanis_Testing V2 - BEANSV.csv
    [MedBeanis_Testing V2 - BEANSV.csv]
2025-04-24 Moved a bunch of stuff for organization
    [BS Sheet - ToExport4.csv, BeanMaxNormalized_Output_ConstantAmplitudeV4 - ToExport.csv, BeanMaxNormalized_Output_ConstantAmplitudeV4 - ToExport3.csv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]
2025-04-25 Reorganized and Renamed a bunch of PyFiles
    [BS Sheet - ToExport4.csv, BeanMaxNormalized_Output_ConstantAmplitudeV4 - ToExport.csv, BeanMaxNormalized_Output_ConstantAmplitudeV4 - ToExport3.csv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]
2025-04-25 new ML program
    [MedBeanis_Testing V2 - BEANSV2.csv]
2025-04-25 Update MedBeanis_Testing V2 - BEANSV2.csv
    [MedBeanis_Testing V2 - BEANSV2.csv]
2025-05-03 Made Dark_Med_Light_Comparison
    [Dark_Med_Light_Roast_Comparison.xlsx]
2025-05-15 Massive Git Organizational Overhaul
    [BS Sheet - ToExport4.csv, Ball x 20 (SLA Resin) v1.stl, Base x 1 (PLA) v1.stl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]
2025-05-15 Massive Overhaul 2
    [BeanMaxNormalized_Output_ConstantAmplitudeV4.xlsx, CombinedBeanDataAll3.xlsx, CombinedBeanDataGuatemala.csv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]
2025-05-16 ml update
    [CombinedBeanDataAll3.csv]
2025-05-16 csv update
    [CombinedBeanDataAll3(100).csv, CombinedBeanDataAll3(100).xlsx, CombinedBeanDataGuatemala(100).csv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]
2025-06-04 documentation things
    [CombinedBeanDataAll3 - Test.csv, Comparison Graph Data.csv]
2025-06-05 graphing stuff
    [Data for Roast Comparison.csv]
